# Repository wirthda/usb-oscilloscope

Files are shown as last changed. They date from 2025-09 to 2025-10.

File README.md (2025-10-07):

# Introduction
This repository serves as documentation and overview of the project **USB-oscilloscope**,
which was carried out in the summer semester 2025 at the efi faculty of the University of Applied Sciences Nuremberg (Georg-Simon-Ohm).
# Overview
### Project structure:
Project structure separated into areas of responsibility.
<ins>legend:</ins>\
HW - hardware\
FW - firmware\
SW - software

### USB oscilloscope prototype:
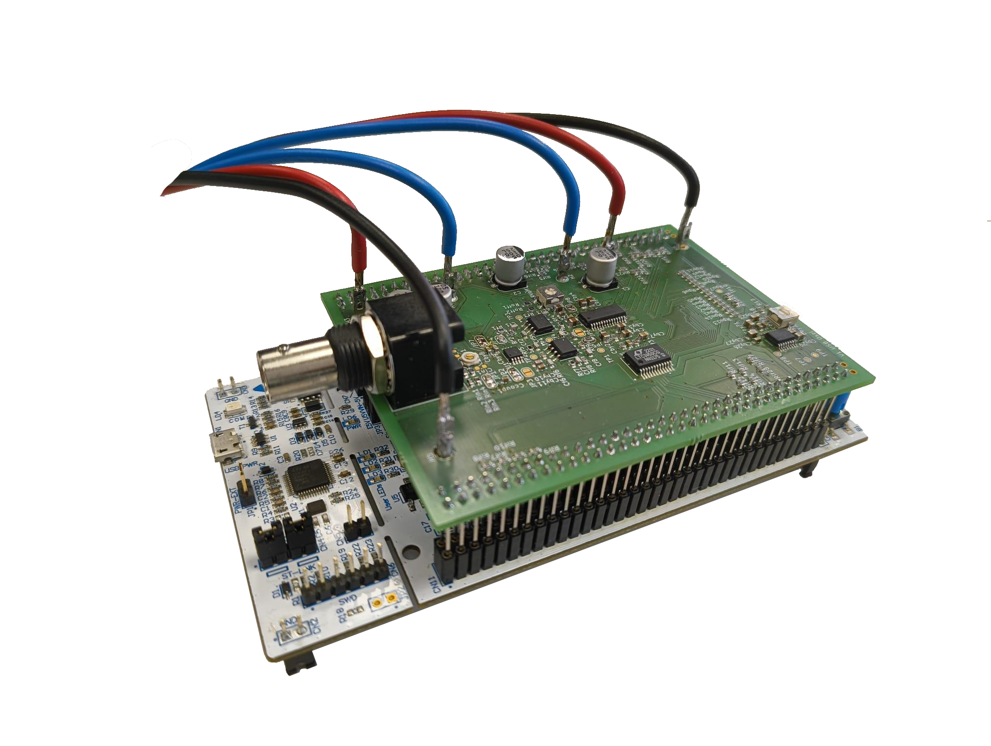
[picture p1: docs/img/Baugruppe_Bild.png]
Picture of the USB oscilloscope prototype.


### Documentation:
PDF [GER]: [Dokumentation_Projekt_USB_Oszi.pdf](docs/documentation/LATEX_german/Dokumentation_Projekt_USB_Oszi.pdf)

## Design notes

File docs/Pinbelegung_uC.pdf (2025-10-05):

## Projekt USB Oszilloskop

Pinbelegungen Microcontroller-Entwicklungsboard NUCLEO-F767ZI

CN11 und CN12 sind sowohl auf dem NUCLEO-Board, als auch auf der Baugruppe vorhanden.
Die Verbindung erfolgt 1:1.
ADC | | | | Trigger | | | | DAC
Pin | Funktion | Stecker | Steckerpin | Pin | Funktion | Stecker | Steckerpin | Pin | Funktion | Stecker | Steckerpin
PF3 3V3_ADC1_D0 | CN12 | 58 | PF2 | 3V3_TRIGGERED_SIG_OUT CN11 | 52 | PE0 | 3V3_DAC1_CLEAR_LOW_ACTIVE CN12 | 64
PF4 3V3_ADC1_D1 | CN12 | 38 | PE1 | 3V3_DAC1_LOAD_LOW_ACTIVE | CN11 | 61
PF5 3V3_ADC1_D2 | CN12 | 36
PF6 3V3_ADC1_D3 | CN11 | 9 | PE2 | 3V3_DAC1_D0 | CN11 | 46
PF7 3V3_ADC1_D4 | CN11 | 11 | PE3 | 3V3_DAC1_D1 | CN11 | 47
PF8 3V3_ADC1_D5 | CN11 | 54 | PE4 | 3V3_DAC1_D2 | CN11 | 48
PF9 3V3_ADC1_D6 | CN11 | 56 | PE5 | 3V3_DAC1_D3 | CN11 | 50
PF10 3V3_ADC1_D7 | CN12 | 42 | PE6 | 3V3_DAC1_D4 | CN11 | 62
PF11 3V3_ADC1_D8 | CN12 | 62 | PE7 | 3V3_DAC1_D5 | CN12 | 44
PF12 3V3_ADC1_D9 | CN12 | 59 | PE8 | 3V3_DAC1_D6 | CN12 | 40
PF13 3V3_ADC1_D10 | CN12 | 57 | PE10 3V3_DAC1_D7 | CN12 | 52
PF14 3V3_ADC1_D11 | CN12 | 50 | PE11 3V3_DAC1_D8 | CN12 | 56
PF15 3V3_ADC1_OF_BIT (Overflow Flag) | CN12 | 60 | PE12 3V3_DAC1_D9 | CN12 | 49
PE13 3V3_DAC1_D10 | CN12 | 55
PE9 3V3_ADC_CLK_IN | CN12 | 52 | PE14 3V3_DAC1_D11 | CN12 | 51

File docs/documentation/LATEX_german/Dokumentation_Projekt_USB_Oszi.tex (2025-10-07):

% Ersteller: 	Daniel Wirth
% Software:	TeX-Distribution --> MiKTeX (https://miktex.org/); Editor --> Texmaker (https://www.xm1math.net/texmaker/)
% Literatur:	.bib erstellt mit JabRef (https://www.jabref.org/); %Achtung: bilatex-mode verwenden (preferences) und dann .bib-file erstellen; Engine --> biber
%

\documentclass[a4paper, portrait, 12pt]{scrartcl} % Vorgabe TH Nbg
%%%%%%%%%%% Präambel %%%%%%%%%%%

% Standardpakete
%\usepackage[latin1]{inputenc}
\usepackage[T1]{fontenc}
\usepackage[ngerman]{babel}
\usepackage[left=3cm, right=2cm]{geometry} % Vorgabe TH Nbg
\usepackage{graphicx}
\graphicspath{ {../../img/} }
\usepackage{amsmath,amsfonts}
\usepackage{siunitx}
\usepackage{textcomp} % €
\usepackage[dvipsnames]{xcolor}
\usepackage{xspace} % Sorgt dafür, dass Leerzeichen hinter parameterlosen Makros nicht als Makroendezeichen interpretiert werden

% Formatierung etc.: Allgemein
\usepackage{setspace}
\onehalfspacing % Vorgabe TH Nbg
%\spacing{1.X}
\setlength{\parindent}{0pt} % Kein Einzug
\usepackage{afterpage}
\usepackage{lastpage}
\usepackage{fancyhdr} % Für beliebige Kopf- und Fußzeilen
\pagestyle{fancy}
\fancyhf{} % Löscht vorherige Einstellungen - Gesamt
%\fancyhead{} % Löscht voherige Einstellungen
%\fancyfoot{} % Dito
\renewcommand{\headrulewidth}{0 pt} % Keine obere Trennlinie
%\(this)pagestyle{empty} % Keine Seitenzahlen
%\setcounter{page}{n} % Bestimme Seite mit n bezeichnen, nachfolgende ist dann n+1
\rfoot{\thepage\ von \pageref{LastPage}} % Seite x von y; Vorgabe TH Nbg
\usepackage{enumitem}

% Formatierung etc.: Schrift
\usepackage{lmodern} % bessere Fonts
%\usepackage{ulem} % Unterstreichen
\usepackage{relsize} % Schriftgröße relativ festlegen

% Formatierung etc.: Tabellen/Arrays
%\usepackage{tabularx} % "Einfacher Tabllen gestalten"
%\usepackage{adjustbox}
\usepackage{caption} % Beschriftung von Bildern/Tabellen
\usepackage{subcaption} % Analog zu oben
%\setlength{\topsep}{0pt} % Kein xtra Abstand über Tabulator	
%\setlength{\partopsep}{0pt} % Kein xtra Abstand unter Tabulator	

% Code-Snippets
\usepackage{listings}

% Hyperlinks und URLs etc.
\usepackage[ 
       colorlinks=true,		%% wenn keine Farbigen Links: = false
    ]{hyperref}
\hypersetup{colorlinks=true, linkcolor=black, urlcolor=MidnightBlue, citecolor=black}
\urlstyle{same}

% Graphiken, Plots, PDFs etc.
%!TEX root = name.tex % Andere .tex-Datei einbinden
\usepackage{pdfpages}
\usepackage{float}
\usepackage{wrapfig}
%\usepackage{pgfplots}
%\pgfplotsset{width=10cm,compat=1.9} % Zweiten Parameter nicht verändern!

% Rechtschreibung bzw. Trennung
%\hyphenchar\font=\string"7F % Nötig für korrekte Silbentrennung!
%\hyphenation{Kom-pli-ziert-es-Wort}
%\hyphenpenalty = XXX
%\tolerance = XXX

% Mathe
%\usepackage{aligned-overset}
%\usepackage{mathabx} %\widehat{•} & \widecheck{}

% "Speziellere" Befehle
%\newcommand{\forceindent}{\leavevmode{\parindent=1.5em\indent}}

% Bibliographie
\usepackage[style=alphabetic, backend=biber]{biblatex}  
\usepackage{csquotes} % Für Anführungszeichen bei Zitaten
\addbibresource{Bibliographie_Projekt_USB_Oszi.bib}
%\usepackage[nohyperlinks, printonlyused]{acronym} % Abkürzungsverzeichnis

% define style for code snippets
\definecolor{codegreen}{rgb}{0,0.6,0}
\definecolor{codegray}{rgb}{0.5,0.5,0.5}
\definecolor{codepurple}{rgb}{0.58,0,0.82}
\definecolor{codefunc}{rgb}{0,0.3,0.7}
\definecolor{backcolour}{rgb}{0.95,0.95,0.92}

\lstdefinestyle{pythonstyle}{
    backgroundcolor=\color{backcolour},   
    commentstyle=\color{codegreen},
    keywordstyle=\color{magenta},
    identifierstyle=\color{codefunc},
    numberstyle=\tiny\color{codegray},
    stringstyle=\color{codepurple},
    basicstyle=\ttfamily\footnotesize,
    breakatwhitespace=false,         
    breaklines=true,                 
    captionpos=b,                    
    keepspaces=true,                 
    numbers=left,                    
    numbersep=5pt,                  
    showspaces=false,                
    showstringspaces=false,
    showtabs=false,                  
    tabsize=2
}

\lstdefinestyle{plaintextstyle}{
    language={},                     % Keine Sprache -> keine Keywords
    basicstyle=\ttfamily\scriptsize, % Nur kleine Monospace-Schrift
    keywordstyle=,                    % Keywords deaktivieren
    commentstyle=,                    % Kommentare deaktivieren
    stringstyle=,                     % Strings deaktivieren
    identifierstyle=,                 % Variablen/Bezeichner deaktivieren
    numbers=none,                     % Keine Zeilennummern
    showspaces=false,                 
    showstringspaces=false,           
    showtabs=false,                   
    breaklines=true,                  
    breakatwhitespace=false,
    backgroundcolor=                  % Kein Hintergrund
}

\lstset{style=pythonstyle}

\title{Projektarbeit ``USB-Oszilloskop``}
\author{Samuel Oeser, Nicole Sturm, Daniel Wirth}
\date{\today}

%%%%%%%%%%% Main %%%%%%%%%%%
\begin{document}

\setlist{noitemsep}	% no item separation in lists

%%%%%%%%%%% Deckblatt %%%%%%%%%%%
\maketitle
\begin{figure}[H]
	\centering
     
	\label{fig:Baugruppe_Bild}
\end{figure}

\begin{center}
	Bachelorstudiengang Elektro- und Informationstechnik (BEI)\\
	Technische Hochschule Nürnberg\\
	Fakultät efi\\
	SoSe2025
\end{center}

\thispagestyle{empty}

\pagebreak

%%%%%%%%%%% TOC %%%%%%%%%%%
%\thispagestyle{empty}
\tableofcontents
\pagebreak

%%%%%%%%%%% Abstract / Zusammenfassung %%%%%%%%%%%
\section{Abstract / Zusammenfassung}

Im Rahmen eines praxisnahen Projektes wurde erfolgreich ein USB-Oszilloskop als digitaler Speicheroszilloskop-Prototyp entwickelt. Zielsetzung war die eigenständige Realisierung aller wesentlichen Entwicklungsphasen, von der Konzeption bis zur Inbetriebnahme, unter Zusammenführung von Hardware, Firmware und PC-Software. Die Hardware besteht aus einem analogen Frontend zur Signalaufbereitung, einem 12-Bit-Analog-Digital-Wandler und einem Mikrocontroller, der die Schnittstelle zum PC bereitstellt.\\ 
Das Projektteam folgte einem strukturierten Vorgehensmodell und definierte die Systemanforderungen in enger Abstimmung mit der Projektbetreuung. Dazu gehörten eine Bandbreite von 1~MHz, eine Abtastrate von 10~MS/s und ein flexibler Eingangsspannungsbereich von $\pm5$~V, der mit üblichen Tastköpfen erweitert werden kann. Die Firmware steuert die Datenerfassung und Vorverarbeitung effizient mittels Zustandsautomat und DMA, die Datenübertragung zum PC erfolgt stabil über USB. Die eigens programmierte Benutzeroberfläche ermöglicht eine intuitive Steuerung sowie Echtzeit-Visualisierung und Analyse der Messdaten.\\ 
Im Rahmen umfangreicher Tests wurde bestätigt, dass das System die Kernanforderungen in vollem Umfang erfüllt. Die Signalaufzeichnung ist bis 500~kHz besonders präzise, für höhere Frequenzen wurden Verbesserungsmöglichkeiten herausgearbeitet. Die modulare Systemarchitektur gewährleistet eine zuverlässige Zusammenarbeit aller Komponenten; die Bedienung erwies sich als benutzerfreundlich und fehlerfrei.\\ 
Das Projekt bot nicht nur Gelegenheit, technische Kompetenzen in den Bereichen Schaltungsentwicklung, Embedded Software und GUI-Design zu vertiefen, sondern auch Teamarbeit, Organisation und systematisches Vorgehen praxisnah umzusetzen. Der Prototyp liefert somit eine fundierte Grundlage für weitere Optimierungen sowie die Entwicklung zusätzlicher Messfunktionen.
\pagebreak

%%%%%%%%%%% Einleitung %%%%%%%%%%%
\section{Einleitung}
Die vorliegende Projektarbeit wurde im Rahmen des Bachelorstudiengangs Elektrotechnik und Informationstechnik an der Fakultät für Elektrotechnik, Feinwerktechnik und Informationstechnik (EFI) der Technischen Hochschule Nürnberg Georg Simon Ohm durchgeführt. Ziel des Projekt-Moduls ist es, den Studierenden die Möglichkeit zu geben, ihr theoretisch erworbenes Wissen in einem praxisnahen, ingenieurwissenschaftlich strukturierten Entwicklungsprojekt anzuwenden. Die Motivation für die Auswahl des Projektthemas lag in der Abbildung des vollständigen Entwicklungsprozesses eines aus Hardware, Firmware und Software bestehenden Gesamtsystems. Auf diese Weise konnten praxisnahe Erfahrungen in allen wesentlichen Entwicklungsdisziplinen gesammelt werden. Darüber hinaus bot das Projekt die Gelegenheit, die grundlegenden Funktionen eines Oszilloskops zu verstehen und im Rahmen eines Prototyps zu realisieren. Ein weiteres wesentliches Auswahlkriterium für das Thema war die klare Unterteilung in abgegrenzte Aufgabenbereiche, sodass die Teammitglieder ihre Aufgaben eigenständig bearbeiten konnten, während gleichzeitig eine Zusammenarbeit im übergeordneten Kontext möglich war.\\

Das zu Beginn definierte Ziel des Projekts war die Entwicklung eines USB-Oszilloskops. Das Gesamtsystem, bestehend aus selbstentwickelter Hardware und einem über Universal Serial Bus (USB) angeschlossenen Computer, soll die Grundfunktionen eines digitalen Speicheroszilloskops (DSO) abbilden. Die Realisierung sollte durch den Einsatz eines Analog-Digital-Umsetzers (ADC) zur Messwerterfassung sowie eines Mikrocontrollers ($\mu$C) als Schnittstelle zwischen der Hardware (ADC-Schaltung) und der Software (Computer) erfolgen.\\

Das Projektteam setzte sich aus drei Studierenden zusammen: Samuel Oeser war verantwortlich für die Entwicklung der Hardware (HW), Daniel Wirth übernahm die Firmware (FW), während Nicole Sturm die Software (SW) einschließlich der grafischen Benutzeroberfläche (GUI) entwickelte. Die Betreuung des Projekts erfolgte durch Prof. Dr. Sven Loquai, der die Studierenden während des gesamten Entwicklungsprozesses begleitete.
\pagebreak

%%%%%%%%%%% Fachliche Grundlagen %%%%%%%%%%%
\section{Fachliche Grundlagen}

\subsection{Allgemeiner Aufbau eines DSOs}
\label{subsec:oscilloscope_func}
Das DSO erfasst Eingangssignale, digitalisiert sie und stellt die Messdaten nach Speicherung und Verarbeitung dar. Der grundlegende Aufbau umfasst die Eingangsumschaltung (DC AC GND) mit Vertikalverstärkung/abschwächung, den ADU mit Signalvorverarbeitung, den Datenspeicher, Takt und Steuerung, die Triggereinrichtung sowie die Anzeige. Die digitalisierten Daten werden im Speicher abgelegt und für Darstellung und Auswertung ausgelesen (vgl. \cite[S. 216]{Muehl2020}).

\begin{figure}[H]
	\centering
     
	\caption{Blockschaltbild eines Digitaloszilloskops (Abb. 14.1 aus \cite[S. 216]{Muehl2020})}
	\label{fig:blockdiagram_oscilloscope}
\end{figure}

Für die Abtastung sind zwei Betriebsarten relevant. Die Echtzeitabtastung erfasst den kompletten Verlauf in einem Durchlauf und die zeitliche Auflösung wird durch die Rate des AD-Umsetzers (ADU) begrenzt. Die Äquivalenzzeitabtastung rekonstruiert sehr schnelle periodische Verläufe aus mehreren Durchläufen (vgl. \cite[S. 216]{Muehl2020}).

\begin{figure}[H]
	\centering
     
	\caption{Gegenüberstellung Echtzeitabtastung (a) und Äquivalenzzeitabtastung (b) (Abb. 14.2 aus \cite[S. 216]{Muehl2020})}
	\label{fig:real_equivalent_sampling}
\end{figure}

Für eine gut auswertbare Darstellung sind etwa zehn Stützstellen je Periode zweckmäßig und die si-Interpolation (auch sinc-Interpolation genannt) ermöglicht bei erfüllter Nyquist Bedingung eine nahezu verzerrungsfreie Rekonstruktion. In der Praxis sollte die maximale Signalfrequenz mindestens um den Faktor 2,5 unter der Abtastrate liegen (vgl. \cite[S. 218f]{Muehl2020}).

\begin{figure}[H]
	\centering
		 
		\caption{\centering Punktedarstellung (a) und lineare Interpolation (b)\\(Abb. 14.4 aus \cite[S. 218]{Muehl2020})}
	\label{fig:point_linear_display}
\end{figure}

\begin{figure}[H]
	\centering
		 
		\caption{\centering Lineare Interpolation (a) und si-Interpolation (b)\\(Abb. 14.5 aus \cite[S. 219]{Muehl2020})}
	\label{fig:linear_si_display}
\end{figure}

In der Praxis werden für die Digitalisierung schnelle Flash-ADUs sowie mehrstufige Sub-ranging- / Pipeline‑Varianten eingesetzt. Diese ermöglichen hohe Raten bei moderater vertikaler Auflösung. Übliche Geräte arbeiten mit acht Bit vertikaler Auflösung. Je nach Architektur sind höhere Auflösungen möglich (vgl. \cite[S. 114-119]{Bernstein2023}). Für die Datenaufnahme stehen verschiedene Acquisition-Modi zur Verfügung. Der direkte Modus liefert äquidistante Samples. Min-Max oder Peak-Detect erfasst Extremwerte innerhalb eines Abtastintervalls und macht kurze Spikes sichtbar. Average reduziert Rauschen durch wiederholtes Mitteln. Single Shot zeichnet einmalige Ereignisse auf und der Roll-Modus zeigt sehr langsame Verläufe kontinuierlich an (vgl. \cite[S. 220f]{Muehl2020}). Die Genauigkeit wird wesentlich durch die Abtastrate und Abtaststrategie, Interpolation und Quantisierung sowie durch die Eingangsbeschaltung bestimmt. Bei Unterabtastung droht Aliasing und die Rekonstruktion wird unzuverlässig (vgl. \cite{Muehl2020}, Grundlagen zur Abtastung und Quantisierung). Wichtige Kenngrößen von DSOs sind analoge Bandbreite, Abtastrate, vertikale Auflösung, Speichertiefe, Triggerfunktionen, Eingangsimpedanz, analoge Eingangsspannung sowie Anzeige und Darstellungsoptionen. Über die Kurvendarstellung hinaus gehören auch automatische Messfunktionen zum Grundumfang.

\subsubsection{Trigger}

Die Triggerung steuert die Signalspeicherung. Fortlaufend erfasste Abtastwerte laufen in einen Ringspeicher und beim Triggerereignis wird das Überschreiben gestoppt, sodass Pre Trigger und Post Trigger gezielt darstellbar sind (vgl. \cite[S. 216f]{Muehl2020}).

\begin{figure}[H]
	\centering
		 
		\caption{\centering Messsignal $s(t)$ mit eingestellter Triggerschwelle und Triggerzeitpunkt\\(Teilabbildung der Abb. 14.3 aus \cite[S. 217]{Muehl2020})}
	\label{fig:trigger_oscilloscope}
\end{figure}

Die analoge Triggerkette umfasst Quelle, Kopplung DC oder AC, einstellbare Triggerschwelle, Flankenrichtung, Hysterese und Auto Trigger. Sie erzeugt ein robustes Triggersignal für die Speichersteuerung (vgl. \cite[S. 210-212]{Muehl2020}).

\begin{figure}[H]
	\centering
		 
		\caption{\centering Funktionsblöcke einer Triggereinrichtung (Abb. 13.8 aus \cite[S. 212]{Muehl2020})}
	\label{fig:trigger_circuit_oscilloscope}
\end{figure}

\subsubsection{Frequenzkompensierter Tastkopf / Spannungsteiler}
\label{subsubsec:freq_comp_vdiv}

In der Praxis existieren verschiedene Arten von Tastköpfen wie passive, aktive und differenzielle Tastköpfe. Im Folgenden wird ausschließlich der frequenzkompensierte passive Tastkopf betrachtet, da er für das Projekt relevant ist (vgl. \cite[Kap. 15]{Muehl2020}). Dieser Tastkopf basiert auf einem frequenzkompensierten Spannungsteiler (seihe \autoref{fig:freq_compensated_vdiv}), realisiert als RC Teiler mit zu den Widerständen parallel geschalteten Kapazitäten und mit einer Anpassung an die Summe aus Bauteil- und Leitungskapazitäten. Die Kompensation mit Trimmkondensator (in \autoref{fig:freq_compensated_vdiv}: $C_T$) wird so abgeglichen, dass das Teilungsverhältnis im Nutz-Frequenzband annähernd konstant bleibt. Der Abgleich erfolgt mit einem Rechtecksignal. Unterkompensation zeigt sich durch eine nach unten geneigte Oberkante (\autoref{fig:freq_compensated_time}a), Überkompensation durch eine nach oben geneigte Oberkante (\autoref{fig:freq_compensated_time}c) und bei korrekter Kompensation bleibt die Oberkante über die Pulsbreite hinweg horizontal (\autoref{fig:freq_compensated_time}b) (vgl. \cite[S. 104-106]{Schruefer2022}).

\begin{figure}[H]
	\centering
		 
		\caption{\centering Tastteiler am Eingang eines Oszilloskops (Bild 2.42 aus \cite[S. 105]{Schruefer2022})}
	\label{fig:freq_compensated_vdiv}
\end{figure}

\begin{figure}[H]
	\centering
		 
		\caption{\centering Rechteckimpulse an RC-Spannungsteiler (Bild 2.43 aus \cite[S. 106]{Schruefer2022})\\ \footnotesize (a) unterkompensiert, (b) richtig kompensiert, (c) überkompensiert}
	\label{fig:freq_compensated_time}
\end{figure}

Mit $R_1=R_T$ und $C_1=C_T$ gilt für die obere Teilimpedanz ($\underline{Z_1}$):
\begin{equation}
	\underline{Z_1}=R_1||\frac{1}{j\omega C_1}=\frac{R_1}{1+j\omega R_1 C_1}
	\label{eq:z1}
\end{equation}
und mit $R_2=R_E$ und $C_2=C_K+C_E$ gilt für die untere Teilimpedanz ($\underline{Z_2}$):
\begin{equation}
	\underline{Z_2}=R_2||\frac{1}{j\omega C_2}=\frac{R_2}{1+j\omega R_2 C_2}
	\label{eq:z2}
\end{equation}
Über den Spannungsteiler ergibt sich aus (\ref{eq:z1}) und (\ref{eq:z2}) das Verhältnis:
\begin{equation}
	\frac{\underline{U_1}}{\underline{U_2}}=\frac{\underline{Z_1}+\underline{Z_2}}{\underline{Z_2}}=1+\frac{\underline{Z_1}}{\underline{Z_2}}=1+\frac{R_1}{R_2}\frac{1+j\omega R_2 C_2}{1+j\omega R_1 C_1}
	\label{eq:comp_vdiv}
\end{equation}
Dieses Verhältnis nimmt den frequenzunabhängigen Wert $\frac{\underline{U_1}}{\underline{U_2}}=1+\frac{R_1}{R_2}$ an, wenn gilt:
\begin{equation}
	R_1\cdot C_1=R_2\cdot C_2
\end{equation}
Durch Einsetzen der Einzelbauelemente für $R_1$, $R_2$, $C_1$ und $C_2$ und Auflösen nach $C_T$ ergibt sich für den Trimmkondensator ein Wert nach \autoref{eq:ct_compensated_vdiv}, damit der Spannungsteiler frequenzunabhängig wird (vgl. \cite[S. 104-106]{Schruefer2022}).

\begin{equation}
	C_T=\frac{R_E\cdot (C_K+C_E)}{R_T}
	\label{eq:ct_compensated_vdiv}
\end{equation}

\subsection{AAF-Entwurf (Nyquisttheorem)}
\label{subsec:aaf_nyquist}

Ein Digitaloszilloskop erfasst das analoge Eingangssignal durch Abtastung mit einer bestimmten Frequenz. Diese Abtastung entspricht der Multiplikation des Signals mit einer Reihe von Impulsen, was im Frequenzbereich einer Faltung entspricht. Eine eindeutige Rekonstruktion aus den Abtastwerten setzt ein bandbegrenztes Eingangssignal mit höchster relevanter Frequenz und eine Abtastrate oberhalb des Doppelten dieser Frequenz voraus. Bei Unterschreitung falten sich Spektralkopien in das Basisband zurück und erzeugen Aliasse. Dies wird im Frequenzbild durch die Überlappung periodischer Spektren sichtbar in \autoref{fig:aaf_freq_domain} sowie im Zeitbereich durch scheinbar niedrigere Schwingungen in \autoref{fig:aliasing_time_domain}. Aus dieser Grundlage folgt die Notwendigkeit eines vorgeschalteten Anti-Aliasing-Tiefpasses, der außerbandige Anteile vor der Wandlung ausreichend dämpft (vgl. \cite[S. 314-316]{Bernstein2023} und \cite[S. 151-156]{Bernstein2024}).

\begin{figure}[H]
	\centering
		 
		\caption{\centering Aliasing: Erzeugung einer Scheinfrequenz durch unpassende Abtastrate\\ (Bild 2.71 aus \cite[S. 154]{Bernstein2024})
		}
	\label{fig:aliasing_time_domain}
\end{figure}

\begin{figure}[H]
	\centering
		 
		\caption{\centering Abtasttheorem (Bild 4.30 aus \cite[S. 314]{Bernstein2023})\\
			\footnotesize(a) Betragsspektrum des bandbegrenzten Signals\\
			(b) Vervielfachung des Basisspektrums durch Abtastung mit $f_S > 2\cdot f_g$\\
			(c) Aliasing infolge zu niedriger Abtastrate ($f_S < 2\cdot f_g$)
		}
	\label{fig:aaf_freq_domain}
\end{figure}

Da der Entwurf des Anti-Aliasing-Filters maßgeblich durch den ausgewählten AD-Umsetzer bestimmt wird, sollte dieser zuerst festgelegt werden. Für aktive RC-Filter bewährt sich wegen Bauteiltoleranzen und des nicht idealen Übergangs vom Durchlass- in den Sperrbereich eine Abtastrate oberhalb der Mindestbedingung, typischerweise etwa 2.5 bis 4 mal $f_{max}$ und bei strengen Dämpfungszielen, z.B. wegen höheren Auflösungen, auch 5 bis 10 mal $f_{max}$. Eine höhere Abtastrate erweitert zudem die Übergangsbreite und senkt damit die notwendige Filterordnung, erleichtert die direkte Darstellung des abgetasteten Signals ohne Rekonstruktionsalgorithmen und erlaubt eine Filterfamilie mit geringerer Gruppenlaufzeitvariation und damit besserem Zeitverhalten. Aus der gewählten Abtastrate folgt dann die Nyquist-Frequenz $f_N = \frac{f_S}{2}$ und die Übergangsbreite $\Delta f = f_N - f_{max}$ \cite{Pini2020}.\\

Der theoretische, aus der Auflösung abgeleitete Dynamikbereich setzt eine Obergrenze für die sinnvoll anzustrebende Sperrbanddämpfung. Für einen \emph{N}-Bit-Umsetzer mit Full-Scale-Range \emph{FSR} gilt die Codebreite $Q = \frac{FSR}{2^N}$. Ein voll ausgesteuertes Störsignal soll auf einen Pegel unterhalb der Codebreite gedämpft werden, damit keine signifikanten Quantisierungsartefakte entstehen. Die Sperrbanddämpfung, beginnend an der Nyquist-Frequenz, wird daher so festgelegt, dass aliasingverursachende Anteile unterhalb der Codebreite bleiben:

\begin{equation}
	A(f_N)_{max}=20\cdot log_{10}\left( \frac{FSR}{Q}\right) =20\cdot log_{10}(2^N)=6.02\cdot N\hspace{0.1cm}dB
\end{equation}

In der Praxis begrenzt das $SINAD$ häufig den nutzbaren Dynamikbereich des gewählten AD-Umsetzers. Gilt $|SINAD|<|A_{max}|$ oder liegt die daraus ermittelte $ENOB$ (siehe \autoref{subsubsec:adc_characteristics} ``\nameref{subsubsec:adc_characteristics}``) unter der Auflösung des ADCs, dominieren Rauschen- und Verzerrungen. Bei Einsatz einer Mittelwertbildung kann es dennoch zweckmäßig sein, die Obergrenze $A_{max}$ anzusetzen. Im Regelfall wird die Sperrbanddämpfung an der Nyquistfrequenz so gewählt, dass gilt (vgl. \cite{Pini2020}):

\begin{equation}
	A(f_N)\approx min(|A_{max}|, |SINAD_{ADC}|)
\end{equation}

Der Entwurf der Filter und die exakte Anpassung an die eigenen Forderungen erfolgt heutzutage in erster Linie mit Filter Tools, wie z.B. dem Analog Filter Wizard. Die Bewertung des entworfenen Filters erfolgt in dem Tool oder der Simulation u. A. über die Diagramme von Amplitudengang, Phasen- und Gruppenlaufzeit sowie Sprung- und Impulsantwort. Der Frequenzgang belegt Passband-Flachheit, Übergangsbreite und die Dämpfung an $f_N$. Phase und Gruppenlaufzeit zeigen, ob das Filter im Nutzband annähernd eine konstante Verzögerung liefert und damit Impulse und Flanken formtreu bleiben. Die Sprungantwort offenbart Überschwinger und Einschwingzeit. Eine Toleranzanalyse der zu erwartenden Widerstands- und Kapazitätsstreuungen zeigt, ob die Reserven ausreichend dimensioniert wurden (vgl. \cite{Pini2020} und \cite{Padmanabhuni2017}).

\subsection{Analog-to-Digital-Converter (ADC)}
\label{subsec:adc}

Ein Digitaloszilloskop benötigt einen AD-Umsetzer als zentrales Hardwareelement, da erst die Wandlung des analogen Eingangssignals in digitale Messwerte die weitere Speicherung, Verarbeitung und Anzeige ermöglicht. Für die Auswahl steht die Topologie am Anfang, weil sie Abtastrate, erreichbare Auflösung, Latenz, Leistungsaufnahme und den Implementierungsaufwand bestimmt.\\

Für ein USB-Oszilloskop bieten sich Flash- und Pipeline-Topologien an, da beide hohe Abtastraten für breitbandige Zeitbereichsmessungen bereitstellen. Andere Varianten wie SAR oder Delta-Sigma werden in den Quellen überwiegend mittleren Geschwindigkeiten oder schmalbandigen Präzisionsaufgaben zugeordnet und sind somit für ein USB-Oszilloskop irrelevant (vgl. \cite{MPS} und \cite{AnalogDevices2001a}).\\

\subsubsection{Flash-ADC}
\autoref{fig:2bit_flash_adc} zeigt das Prinzip eines Flash-AD-Umsetzers mit zwei Bit. Eine Widerstandsleiter erzeugt abgestufte Referenzen und eine Komparatorbank vergleicht das Eingangssignal mit diesen Schwellen. Das resultierende Muster wird durch eine Logikschaltung in einen Binärcode überführt. Flash-ADCs erreichen, durch diesen simplen Aufbau, die höchste Geschwindigkeit. Da die Zahl der Komparatoren jedoch $2^N-1$ beträgt, steigen bei hohen Auflösungen Komplexität, Fläche, Leistungsaufnahme sowie insbesondere die Herstellungskosten annähernd exponentiell an (vgl. \cite{MPS} und \cite{AnalogDevices2001b}).

\begin{figure}[H]
	\centering
		 
		\caption{\centering  Flash-Umsetzer mit 2 Bit, einschl. Kodeumsetzer\\
		\footnotesize Ersteller: Saure, Quelle: \href{https://de.wikipedia.org/wiki/Datei:DMT_ADU-2-Bit-Flash.svg}{[Link]} (Lizenz: \href{https://creativecommons.org/licenses/by-sa/3.0/}{CC BY-SA 3.0})
		}
	\label{fig:2bit_flash_adc}
\end{figure}

\subsubsection{Pipeline-ADC}
Eine Alternative zur geringeren Skalierbarkeit des Flash-ADCs ist der Pipeline-ADC, der auch im Projekt zur Anwendung kommt. Er baut funktional auf dem Flash-Prinzip auf, indem mehrere niedrigauflösende Flash-ADCs in Stufen hintereinandergeschaltet werden. Am Eingang tastet eine Sample-and-Hold-Stufe das Signal ab. Jede Stufe wandelt in wenige Bits, rekonstruiert den quantisierten Anteil über einen DAC, bildet den Restfehler im Subtrahierer und verstärkt diesen für die nächste Stufe. Durch Überlappbits und digitale Fehlerkorrektur können die Genauigkeitsanforderungen an die einzelnen Stufen reduziert werden und die Durchsatzraten erhöht. Durch diesen Aufbau steigt der Aufwand mit zunehmender Auslösung nur linear an. Bauartbedingt entsteht allerdings eine definierte Zykluslatenz, die in ganzen oder halben Taktzyklen angegeben wird. Diese Latenz ist der entscheidende Nachteil eines Pipeline ADCs (vgl. \cite{MPS} und \cite{AnalogDevices2001c}).

\begin{figure}[H]
	\centering
		 
		\caption{\centering 12-bit pipelined ADC\\ \footnotesize Ersteller: MPS, Quelle: \href{https://www.monolithicpower.com/en/learning/mpscholar/analog-to-digital-converters/detailed-analysis-of-adc-architectures/pipeline-adcs}{[Link]} (Ch. 2, Fig. 4)
		}
	\label{fig:pipelined_adc}
\end{figure}
\pagebreak

\subsubsection{Wichtige Kenngrößen von AD-Umsetzern}
\label{subsubsec:adc_characteristics}

Die Kenngrößen und deren Definition können dem IEEE Standard 1241-2023 \emph{``Terminology and Test Methods for Analog-to-Digital Converters``} (\cite[S. 22ff]{IEEE2023}) entnommen werden.\\

\textbf{Auflösung und Eingangsbereich}\\
Die Auflösung eines \emph{N}-Bit-AD-Umsetzers umfasst $2^N$ binäre Codes. Der differentielle Eingangspannungssbereich wird als Full-Scale Range (\emph{FSR}) bezeichnet und in Volt angegeben. Das LSB entspricht $\frac{FSR}{2^N}$.\\

\textbf{Maximale Sampling-Rate}\\
Die Abtastrate ist der Kehrwert der Abtastperiode (Abstand zwischen Abtastwerten). Sie bestimmt die zeitliche Auflösung und ist insbesondere in Bezug auf das Niyqusttheorem relevant.\\

\textbf{Leistungsaufnahme}\\
Die Leistungsaufnahme ist in erster Linie für die Auslegung der Versorgungsspannung und der zugehörigen Leitungen relevant.\\

\textbf{Verstärkungsfehler}\\
Der Verstärkungsfehler beschreibt die Abweichung der Kennliniensteigung von der idealen Steigung nach Offsetkorrektur und wird in $LSB$ oder in Prozent der Full-Scale-Range angegeben.\\

\textbf{Offsetfehler}\\
Der Offsetfehler ist die vertikale Verschiebung der Kennlinie relativ zur Referenzgeraden und wird in $LSB$ oder in Prozent der Full-Scale-Range angegeben.\\

\textbf{Latenz}\\
Die Latenz wird als Pipeline-Delay in ganzen oder halben Taktzyklen angegeben oder alternativ als Zeitangabe und beschreibt den Abstand zwischen Abtastung und Verfügbarkeit des zugehörigen Digitalworts.\\

\textbf{Differentielle Nichtlinearität $DNL$}\\
Die DNL ist die Abweichung der tatsächlichen Codebreite $W[k]$ von der idealen Codebreite $Q$, normiert auf $Q$, und wird in $LSB$ angegeben. Die Codebreite entspricht dem Spannungsbereich, der dem Code zugeordnet ist. Formal gilt $DNL[k]=\frac{W[k]}{Q}-1$.\\
Die Angabe im Datenblatt entspricht $max\hspace{0.1cm}DNL[k]$.\\

\textbf{Integrale Nichtlinearität $INL$}\\
Abweichung des Übergangsspannungsniveaus von einem Code in den nächsten zu dem der idealisierten Geraden, nach Korrektur von Offset und Verstärkung.\\
Damit gilt $INL[k]=\sum_{n=0}^kDNL[n]$. Die Angabe im Datenblatt entspricht $max\hspace{0.1cm}INL[k]$.\\

\textbf{Rausch- und Verzerrungsmaße}\\
\textbf{$SNR$} gibt das Verhältnis von Nutzsignal- zu Rauschleistung an:
\begin{equation}
	SNR_{dB}=10\cdot \log_{10}\left( \frac{P_{Signal}}{P_{Rauschen}}\right)
\end{equation}

\textbf{$THD$} ist ein Maß für das Verhältnis von harmonischen Verzerrungen zur Grundschwingung:
\begin{equation}
	THD_{dB}=10\cdot \log_{10}\left( \frac{P_{Harmonische}}{P_{Signal}}\right)
\end{equation}

\textbf{$SINAD$} umfasst harmonische Verzerrungen und Rauschen:
\begin{equation}
	SINAD_{dB}=10\cdot \log_{10}\left( \frac{P_{Signal}}{P_{Rauschen}+P_{Harmonische}}\right)
\end{equation}

\textbf{$ENOB$} ist die effektive Bitzahl und wird aus SINAD abgeleitet:
\begin{equation}
	ENOB\approx \frac{SINAD[dB]-1.76}{6.02}
\end{equation}

\pagebreak

\subsection{Endliche Zustandsautomaten (Finite State-Machines - FSMs)}
\label{subsec:fsm}
Die Firmware und Software des Projekts sind als synchronisierte Zustandsautomaten implementiert, um einen deterministischen Ablauf der beiden Programme zu gewährleisten.
\subsubsection{Definition und formale Darstellung}
Ein endlicher Automat (EA - engl. Finite State Machine, FSM) ist ein abstraktes Rechenmodell zur Beschreibung von Systemen. Dieser befindet sich in mindestens einem Zustand von einer Zahl endlicher Zustände. Zustandsübergänge (sog. Transitionen) erfolgen durch Eingaben oder das Auftreten von Ereignissen (spezielle Form der Eingabe).\\

Zustände modellieren, was das System gerade tut bzw. in welchem internen ``Modus`` es sich befindet. Ereignisse sorgen für den Wechsel zwischen Zuständen. Übergänge definieren, wie das System im aktuellen Zustand auf ein Ereignis reagiert.

Ein FSM besteht nach \cite[S. 7ff]{Baesig2019} typischerweise aus:
\begin{itemize}
	\item einer Menge von Zuständen $S$,
	\item einem Anfangszustand $s_0$,
	\item einem Eingabe- oder Ereignisalphabet $E$ (Events),
	\item einem Ausgabealphabet $A$,
	\item einer Zustandsübergangsfunktion $\delta :S\times E\rightarrow S$,
	\item einer Ausgabefunktion $\lambda :S\times E\rightarrow A$,
	\item und einer endlichen (evtl. leeren) Menge der Endzustände $F$.
\end{itemize}

Je nach Modellierung kann das Ausgabealphabet und die Ausgabefunktion, sowie die Menge an Endzuständen entfallen.\\

Unterschieden werden folgende Arten von Endlichen Automaten:
\begin{itemize}
	\item \emph{Deterministische Endliche Automaten (DEA)}:\\
	Ein Automat wird als deterministisch bezeichnet, wenn für jede Kombination aus Eingabedaten und aktuellem Zustand eindeutig festgelegt ist, welcher Folgezustand erreicht wird. Das bedeutet, dass sich das \emph{System zu einem bestimmten Zeitpunkt stets in genau einem definierten Zustand} befindet.
	\item \emph{Nichtdeterministische Endliche Automaten (NEA)}:\\
	Bei einem NEA sind für einen bestimmten Zustand und eine Eingabe keine, genau ein oder mehrere mögliche Zustandsübergänge definiert.
\end{itemize}

DEAs sind einfacher als NEAs zu implementieren, wodurch diese in der Praxis häufiger zur Anwendung kommen (vgl. \cite[S. 14]{Baesig2019}). Im Projekt sind die FSMs als DEAs ausgeführt .\\

Eine weitere Aufgliederung von DEAs erfolgt nach der Abhängigkeit der Ausgabe, wenn diese vorhanden ist (vgl. \cite[S. 8f]{Baesig2019}).
\begin{itemize}
	\item Wenn die Ausgabe nur vom aktuellen Zustand abhängt, handelt es sich um einen \emph{Moore-Automaten}.
	\item Wenn die Ausgabe vom aktuellen Zustand \underline{und} der Eingabe abhängt, handelt es sich um einen \emph{Mealy-Automaten}.
\end{itemize}
Im Projekt kommen Moore-Automaten zur Anwendung.

\subsubsection{Modellierung und Darstellung}

Die Darstellung eines Zustandsautomaten erfolgt üblicherweise mit einem \emph{Zustandsdiagramm} (auch Zustandsübergangsdiagramm), einem gerichteten Graph\footnote{ ``Graphen sind ein [...] Konzept, um Objekte und die Beziehung zwischen diesen darzustellen.``\\Quelle: \href{https://www.tu-chemnitz.de/informatik/theoretische-informatik/TI-1/lecture-notes/06-00-graphs.html}{[Link]}}. Die Knoten stellen die Zustände der Menge $S$ dar und die gerichteten Kanten die Zustandsübergänge. Der Startzustand und die Endzustände werden gesondert gekennzeichnet. Eine übliche Darstellung für einen einfachen Moore-Automaten findet sich in \autoref{fig:statediagram_example}a (\emph{sn} sind die Zustände, \emph{xn} sind Eingaben oder Ereignisse und \emph{yn} sind Ausgaben; \emph{n = 1,2,...}) (vgl. \cite[S. 9]{Baesig2019}).\\

Die Darstellung des Zustandsdiagramms ist auch als Teil der \emph{Unified Modelling Language (UML)}\footnote{aktueller UML-Standard (V2.5.1): \href{https://www.omg.org/spec/UML/2.5.1/About-UML}{[Link]}} festgelegt, welche auch durch internationale Normung festgeschrieben ist. In der Praxis (vor allem beim händischen Entwurf von Zustandsdiagrammen) hat sich aber ein Mischform bewährt, welche auf einige Elemente der UML zurückgreift (siehe \autoref{fig:statediagram_example}b). Es lassen sich beispielsweise auch hierarchische Strukturen integrieren (verschachtelte Zustände).

\begin{figure}[H]
	\centering
     
	\caption{(a) Zustandsdiagramm (nach \cite{Baesig2019}); (b) UML-Zustandsdiagramm}
	\label{fig:statediagram_example}
\end{figure}
\subsubsection{Vorteile einer FSM bei der Programmierung}
\begin{itemize}
	\item \emph{Klarheit \& Übersichtlichkeit}\\
	Der Systemverlauf ist in wohldefinierte Zustände gegliedert. Der Code wird hierdurch verständlicher (kein ``Spaghetti-Code``).
	\item \emph{Deterministisches Verhalten}\\
	Durch die Definitionen, wie auf welches Ereignis reagiert wird, kann die Vorhersagbarkeit und Zuverlässigkeit gewährleistet werden. Außerdem lassen sich undefinierte Zustände durch die explizite Modellierung vermeiden.
	\item \emph{Modularisierung \& Wiederverwendbarkeit}\\
	Einzelne Zustände oder Teile der FSM lassen sich kapseln, segmentieren und wiederverwenden. Teilbereiche können eventuell separat getestet werden.
	\item \emph{Wartbarkeit \& Erweiterbarkeit}\\
	Das System lässt sich durch Hinzufügen neuer Zustände oder neuer Übergänge modular erweitern, ohne die vorhandene Logik stark zu verändern.
	\item \emph{Kommunikation und Dokumentation}\\
	Zustandsdiagramme können bei der Vermittlung von komplexem Programmverhalten gegenüber Nicht-Programmieren genutzt werden.
	\item \emph{Verbessertes Debugging}\\
	Da Zustandsübergänge zentralisiert sind, lassen sich Log-Messages und weitere Debugging-Mechanismen leichter verwenden.
\end{itemize}

\subsection{Direct Memory Access - DMA}
\label{subsec:dma}
\subsubsection{Allgemeines}
DMA bezeichnet den Vorgang, bei dem durch eine dedizierte Einheit ohne Beteiligung einer CPU Daten transferiert werden (also als Hintergrundprozess). Er kommt zum Einsatz, wenn große Datenmengen von der Peripherie oder einem Speicher zu einem anderen transferiert werden müssen. Ein Chip oder eine Teileinheit eines Mikrocontroller (µC), die solche Transfers durchführt, heißt \emph{Direct Memory Access Controller (DMAC)} (vgl. \cite[S. 125]{Urbanek2020}). Im Folgenden soll die Funktionsweise anhand der Realisierung in der im Projekt verwendeten STM32-Mikrocontrollerfamilie erläutert werden.

\subsubsection{DMA bei STM32-Mikrocontrollern}
Der DMA-Controller ist ein AHB-Modul (AHB - advanced high-performance bus; standardisiertes Bussystem von ARM) und kann wie auch die CPU des µCs als Master auf diesen Bus (genauer auf die Bus-Matrix) zugreifen. Durch die Datentransfers, welcher der DMAC nach seiner Konfiguration ohne CPU-Beteiligung ermöglicht, kann die System-Performance deutlich erhöht werden. Die Datentransfers können hierbei per Software oder über angeschlossene Peripherieelemente über sog. \emph{Requests} gestartet werden. Wird als steuerndes Element beispielsweise ein Hardware-Timer genutzt ermöglicht dies die zeitlich exakte Taktung von Datentransfers \cite[S. 6]{STmicroelectronics2016}, was im Projekt für den Abtastvorgang genutzt wird.

Der µC besitzt zwei unabhängige DMAC (Aufbau siehe \autoref{fig:dmac}), deren Anbindung an Peripherie und Speicher unterschiedlich ausfällt, um alle Ressourcen des Systems flexibel zu verwenden.\\

Der DMAC besitzt 3 Schnittstellen:
\begin{itemize}
	\item \emph{slave port} zur Programmierung des DMAs
	\item \emph{2 master ports} \begin{itemize}
		\item \emph{peripheral port}: peripherieseitiger Datenanschluss
		\item \emph{memory port}: speicherseitiger Datenanschluss
	\end{itemize}
\end{itemize}

\begin{figure}[H]
	\centering
     
	\caption{Blockdiagramm STM32-DMA-Controller aus \cite[S. 7]{STmicroelectronics2016}}
	\label{fig:dmac}
\end{figure}

Jeder Controller besitzt 8 Datenwege (\emph{Streams}), die separat für unterschiedliche Datentransfers konfiguriert werden können (die Transfers können aber nicht gleichzeitig laufen). Die Streams besitzen hierbei eine konfigurierbare Priorität und ein zentrales Modul, der \emph{Arbiter}, regelt den Zugriff der Streams auf die Ports in Abhängigkeit der Priorität und sorgt für einen deterministischen Ablauf der Transfers. Die einzelnen Streams besitzen noch eine Anzahl an \emph{Channeln}, über die der entsprechende Peripherie-Request für einen Stream ausgewählt werden kann (vgl. \cite[S. 7ff]{STmicroelectronics2016}). Die Zuordnung eines Peripherie-Requests zu einer Channel-Stream-Kombination kann dem Reference-Manual des Controllers entnommen werden (für den STM32F767: \cite[S. 252]{STmicroelectronics2024}).

\pagebreak

Jeder Stream besitzt außerdem einen 4-stufige \emph{FIFO}-Pufferspeicher (First-In-First-Out), welcher Latenzen beim Zugriff auf das Übertragungsmedium (Bus-Switch-Matrix) überbrücken kann und ein \emph{Verpacken/Entpacken der Daten} erlaubt (z.B.: input: 8bit-Pakete, output: 32bit-Pakete; siehe \autoref{fig:dma_fifo}).

\begin{figure}[H]
	\centering
     
	\caption{FIFO-Struktur aus \cite[S. 11]{STmicroelectronics2016} (Teilabbildung)}
	\label{fig:dma_fifo}
\end{figure}

\textbf{\underline{DMA-Transfers}}\\
Ein Transfer wird zunächst über die \emph{Quelladresse (source address)} und \emph{Zieladresse (destination address)} charakterisiert, hier kann der DMA so konfiguriert werden, dass die Adressen nach einem Transfer automatisch inkrementiert werden können. Somit lassen sich, im Speicher hintereinanderliegende, Daten einfach übertragen. Quell- oder Zieladresse können jeweils aber auch konstant gehalten werden (siehe \autoref{fig:periph_to_mem}).

\begin{figure}[H]
	\centering
     
	\caption{DMA Quell- und Zieladressinkrementierung aus \cite[S. 10]{STmicroelectronics2016}}
	\label{fig:dma_transfer_inc}
\end{figure}

Weitere wichtige Parameter sind die Übertragungsgröße (transfer size), die in einem dedizierten Register (\emph{NDTR} - Number of Data Transfers Register) abgelegt ist, und die Datenbreite (Byte, Half-word, Word). Der Inhalt des NDTR wird nach jedem Transfer entsprechend der Größe des Transfers dekrementiert. Hier wird noch zwischen Circular mode und Normale mode unterschieden. Beim Normal mode ist eine Transaktion (bestehend aus NDTR Transfers) bei NDTR=0 beendet. Der Stream wird deaktiviert und es finden bis zum nächsten Aktivieren des Streams keine Transfers mehr statt. Beim Circular mode wird bei NDTR=0 das Register NDTR mit dem Initialwert geladen und die Transfers beginnen erneut (auch die Adressregister werden mit den Initialwerten geladen) $\rightarrow$ Kreislauf (circular).\\

Die drei möglichen Transfer-Modi sind:
\begin{itemize}
	\item Peripheral-to-Memory (siehe Beispiel in \autoref{fig:periph_to_mem}))
	\item Memory-to-Peripheral
	\item Memory-to-Memory
\end{itemize}

Bei einem Timer-Überlauf des Hardware-Timers TIM1 findet ein DMA-Request statt (ein Stream wurde hierbei entsprechend konfiguriert). Dieser Request löst einen Daten-Transfer zwischen Ziel und Quelle aus (die Datenbreite wurde im Beispiel auf 1 Byte festgelegt). Anschließend werden die Adressen entsprechend der Datenbreite inkrementiert, um die Ziel- und Quelladresse für den nächsten Transfer vorzubereiten. Dieser Prozess geschieht so lange, bis ``Number of Transfers`` durchgeführt worden sind. Der Wert von NDTR wird nach dem Transfer dekrementiert.\\

\begin{figure}[H]
	\centering
     
	\caption{peripheral-to-memory-Transfer}
	\label{fig:periph_to_mem}
\end{figure}

Im Abtastsystem ist keine Inkrementierung der Quelladresse notwendig, da nur das Eingangsdatenregister ausgelesen werden muss, welches die Schnittstelle zum parallelen ADC-Interface darstellt (siehe \autoref{fig:data_acq_dma} im Entwurfsteil der FW).

\pagebreak

\textbf{\underline{DMA-Transferwege}}\\

Gemeinsames Übertragungsmedium ist die Bus-Switch-Matrix, die auch in den vorherigen Abbildungen schon dargestellt wurde. Der Zugriff auf diese wird mit Hilfe einer Arbitrierung nach einem round-robin-Algorithmus geregelt. 
Durch den Arbitrierungsvorgang oder die Blockierung des Übertragungsmediums durch einen anderen Bus-Master (z.B. die CPU) kann eine \emph{Latenz beim DMA-Transfer} entstehen.

\begin{figure}[H]
	\centering
     
	\caption{Systemarchitektur für STM32F76xxx $\mu$C aus \cite[S. 72]{STmicroelectronics2024}}
	\label{fig:sysarch_stm32f7}
\end{figure}

Nur Bus-Master (z.B.: Prozessor, DMA-Controller (in \autoref{fig:sysarch_stm32f7} rot hervorgehoben) können Lese- und Schreiboperationen initiieren.

\pagebreak

\subsection{Digitale Filterung (Preprocessing)}
\label{subsec:digital_filtering}

\subsubsection{Motivation und Grundlagen digitaler Filterung}
Digitale Filterung ist ein zentrales Element der digitalen Signalverarbeitung (DSP). Filter werden im Allgemeinen für zwei Hauptzwecke eingesetzt:
\begin{itemize}
	\item Trennung von Signalen, die miteinander überlagert wurden,

	\item Wiederherstellung von Signalen, die auf ihrem Übertragungsweg oder bei der Messung verzerrt wurden \cite[S. 261]{Smith1999}.
\end{itemize}

Während analoge Filter durch elektronische Schaltungen realisiert werden, bieten digitale Filter eine wesentlich höhere Präzision und Flexibilität. Sie können sehr steile Übergänge zwischen Durchlass- und Sperrbereich (passband und stopband) erzeugen und zeigen kaum Toleranzprobleme wie analoge Filter. Beim analogen Filterdesign ist die Beherrschung von Bauteiltoleranzen von wesentlicher Bedeutung \cite[S. 262]{Smith1999}. Digitale Filterung bietet sich bei Anwendungen mit Mikrocontrollern an, da die Filter-Algorithmen direkt einprogrammiert werden können und eine analoge Filterschaltung ersetzen oder reduzieren können.

\subsubsection{Filterklassifikation}

\underline{Einteilung nach Signalcharakteristik}\\
Die Einteilung der Filter richtet sich einerseits danach, in welcher Form die Information im Signal enthalten ist \cite[S. 265]{Smith1999}.

\begin{itemize}
	\item \emph{Zeitbereich (time-domain):}\\
	Die Information ist direkt in der Form des Signals enthalten.\\
	Bsp.: Glätten von Messdaten, DC-Offset-Entfernung, Signalerkennung.\\
	$\rightarrow$ Die Sprungantwort (step-response) ist hier entscheidend.

	\item \emph{Frequenzbereich (frequency-domain):}\\
	Die Information steckt in den Frequenzkomponenten des Signals.\\
	Bsp.: Trennung von Audiosignalen oder Herausfiltern bestimmter Störfrequenzen.\\
	$\rightarrow$ Der Frequenzgang (frequency-response) ist hier entscheidend.
\end{itemize}

\pagebreak

\underline{Einteilung nach Implementierung}\\
Die Einteilung der Filter richtet sich einerseits danach, in welcher Form die Information im Signal enthalten ist \cite[S. 265]{Smith1999}.

\begin{itemize}
	\item \emph{FIR-Filter (Finite Impulse Response):}\\
	Umsetzung erfolgt durch \textbf{Faltung (Convolution)} des Eingangssignals mit einem endlichen Filterkern (\emph{engl. filter kernel}). Ein Ausgangswert wird berechnet, indem Eingangswerte mit zuvor definierten Gewichtungsfaktoren multipliziert und anschließend aufaddiert werden.\\
	Eigenschaften:
	\begin{itemize}
		\item Stabil und vorhersagbar,
		\item Endliche Impulsantwort,
		\item Einfach zu implementieren, aber rechenintensiv.
		\item Beispiel: Moving Average Filter.
	\end{itemize}

	\item \emph{IIR-Filter (Infinite Impulse Response):}\\
	Umsetzung durch \textbf{Rekursion}, bei der sowohl aktuelle Eingangswerte als auch frühere Ausgangswerte zur Berechnung herangezogen werden.\\
	Eigenschaften:
	\begin{itemize}
		\item Sehr effizient (weniger Rechenaufwand),
		\item Theoretisch unendliche Impulsantwort,
		\item Gefahr der Instabilität bei fehlerhafter Parametrierung.
		\item Beispiel: digitale Tiefpassfilter auf Basis analoger Schaltungen.	
	\end{itemize}
\end{itemize}

\pagebreak

\subsubsection{Gleitender Mittelwertfilter}

Der \emph{gleitende Mittelwertfilter (engl. Moving Average Filter - MAF)} ist einer der einfachsten und am häufigsten eingesetzten digitalen Filter. Er arbeitet, indem er für jedes Ausgabesample den Mittelwert aus einer festen Anzahl aufeinanderfolgender Eingangssamples berechnet \cite[S. 277]{Smith1999}.
Seine Hauptaufgabe besteht darin, zufälliges Rauschen zu reduzieren (siehe \autoref{fig:mov_avg_filter_signal}), während plötzliche Signaländerungen (Steps) möglichst gut erhalten bleiben.

\begin{figure}[H]
	\centering
     
	\caption{\centering Anwendung eines MAF unterschiedlicher Fensterbreite\\
				\footnotesize
				(a) Eingangssignal, (b) Ausgangssignal $M=11$, (c) Ausgangssignal $M=51$\\				(Figure 15-1 aus \cite[S. 279]{Smith1999})}
	\label{fig:mov_avg_filter_signal}
\end{figure}

\underline{Grundidee}
Für ein Fenster der Breite $M$ ergibt sich das Ausgangssignal $y[i]$ aus dem Eingangssignal $x[i]$ durch:
\begin{equation}
	y[i]=\frac{1}{M}\sum_{j=0}^{M-1}x[i+j]
\end{equation}
Es ist zu erkennen, dass die rechtsseitigen Eingangswerte zum Ausgangswert aufsummiert werden. Eine alternative Umsetzung wäre es die aufzusummierenden Eingangswerte symmetrisch um den Ausgangswert zu wählen (Beispiel für einen Ausgangswert):
\begin{equation}
	y[80]=\frac{x[78]+x[79]+x[80]+x[81]+x[82]}{5}
\end{equation}

Damit entspricht der Moving Average Filter einer Faltung des Eingangssignals mit einem rechteckigen Filterkern \cite[S. 277f]{Smith1999}.\\

Für das Projekt wurde der Filter kumulativ und rekursiv implementiert und nach den Algorithmen in \autoref{lst:moving_avg_filter_algorithm_cumulative} und \autoref{lst:moving_avg_filter_algorithm_recursive} im \autoref{subsubsec:preprocessing_concept} umgesetzt.

\subsection{Parallele Prozesse und Nebenläufigkeiten in Python}

\subsubsection{Threads in Python}
	
	Ein Thread ist ein paralleler Ausführungsstrang innerhalb eines Programms. Alle Threads teilen sich den selben Speicherbereich. 
	Dadurch kann es zu Wettlaufbedingungen kommen oder zu unvorhersehbaren Verhalten. Der Zugriff auf gemeinsame Daten muss daher synchronisiert werden, z.B. mit Locks, Semaphoren oder Warteschlangen. 
	Durch den Global Interpreter Lock (GIL), ein zentrales Konzept im Standard-Python-Interpreter CPython, 
	kann zu einem Zeitpunkt immer nur ein Thread, Python-Bytecode ausführen. Das heißt, auch wenn für einen Job mehrere Threads gestartet werden, arbeitet immer nur ein Thread gleichzeitig.
	Dieses Prinzip widersricht zwar der Idee von paralleler Ausführung, jedoch darf ein anderer Thread Programmcode ausführen, wenn der Thread gerade auf eine Eingabe wartet.
	Das GIL wird in Python genutzt, da es die Verwaltung von Python-Objekten im Speicher vereinfacht. Dies ist vor allem wichtig, da der der Speicher in Python typischerweise
	automatisch verwaltet wird (vgl. \cite{Lang2024} Abschnitt ``Was sind Threads in Python{?}``). 

	Threading eignet sich vor allem für E/A-lastige Aufgaben, die mit Datenaustausch verbunden sind.

	\underline{Synchronisation}
	\begin{itemize}
		\item Locks: Sperren, die verhindern, dass mehrere Threads gleichzeitig auf die selben Daten zugreifen.
		\item Semaphoren: Begrenzen die Anzahl gleichzeitiger Zugriffe auf eine Ressource.
		\item Warteschlange (Queues): Erlauben thread-sicheren Austausch von Datenobjekten, nach dem FIFO-Prinzip.
	\end{itemize}

\subsubsection{Multiprocessing in Python}	
	
	Beim multiprocessing werden mehrere, vollständig unabhängige Prozesse gestartet. Jeder Prozess ist eine eigene Instanz des Programms mit eigenem Speicherbereich. Dies führt dazu, dass die
	Kommunikation zwischen den jeweiligen Prozessen komplexer ist. Hierfür stellt das Python-Modul multiprocessing Funktionen und Klassen bereit.

	Multiprocessing kann die Leistungsfähigkeit bei rechenintensiven Aufgaben deutlich steigern, bringt aber auch Overhead durch Speicherbedarf und zusätzliche Komplexität in der Verwaltung mit.

	\underline{Synchronisation}
	\begin{itemize}
		\item Pipes: Unidirektionale Kanäle für Datenübertragung zwischen Prozessen. 
		\item Shared Memory: Gemeinsamer Speicherbereich für Datenaustausch.
	\end{itemize}

\begin{figure}[H]
	\centering
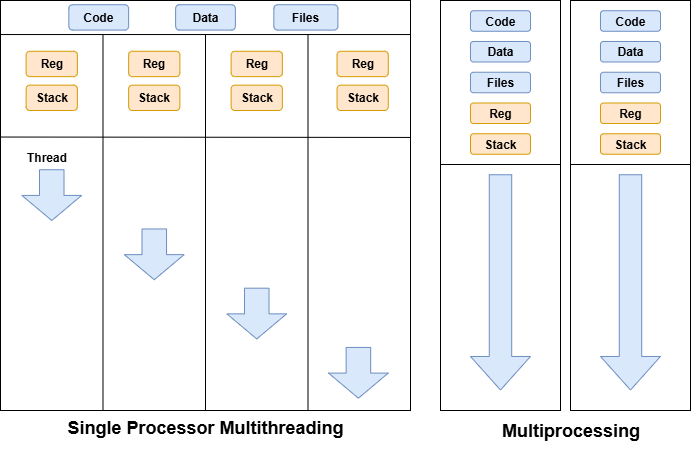
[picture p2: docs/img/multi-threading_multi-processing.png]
     
	\caption{Vergleich Multi-Threading und Multi-Processing}
	\label{fig:multithr/pro}
\end{figure}

In unserem Projekt wurden Threads verwendet, da die Anwendung hauptsächlich E/A-gebunden ist. Zusätzlich wird ein gemeinsamer Speicher benötigt, damit die Messdaten an die Benutzeroberfläche 
übergeben werden können. Die Kommunikation wurde mit zwei Warteschlangen realisiert, eine dient zur Übergabe von Statusmeldungen von der FSM zur Benutzeroberfläche (GUI) und die andere zur
Übergabe von Befehlen von der GUI an die FSM (vgl. \cite{Lang2024} Abschnitt ``Was ist Multiprocessing in Python{?}``). 

%%%%%%%%%%% Projektkonzeption %%%%%%%%%%%
\section{Projektkonzeption}
\subsection{Vorgehensweise}
Das übergeordnete Vorgehen folgte einem strukturierten Prozess, der sich gut durch das \textbf{V-Modell} visualisieren lässt. Diese Vorgehensweise eignete sich insbesondere aus drei Gründen: \emph{Erstens}, Änderungen an Hardware sind nach deren Umsetzung nur schwer möglich, was iterative Prozesse sehr aufwendig macht. \emph{Zweitens} standen die Projektziele von Beginn an eindeutig fest. \emph{Drittens} waren die Aufgabenbereiche klar voneinander abgegrenzt. Zudem handelte es sich um ein überschaubares Projekt.

\begin{figure}[H]
\centering
     
	\caption{V-Modell}
\end{figure}

Im Folgenden werden die einzelnen Phasen und zugehörigen Validierungsschritte kurz erläutert.\vspace{0.1cm}\\
\underline{Anforderungsanalyse und Abnahmetest}\\
In enger Abstimmung mit dem betreuenden Professor wurden die grundlegenden Anforderungen definiert. Dazu gehörten unter anderem Bandbreite, Abtastrate, Auflösung und Eingangsspannungsbereich. Der spätere Abnahmetest bestand darin zu überprüfen, ob das entwickelte System diese Vorgaben in einer realistischen Versuchsumgebung erfüllte.\vspace{0.1cm}\\
\underline{Systemdesign und Systemtest}\\
Anschließend wurden die grundlegenden Systemfunktionen festgelegt, die zur Erfüllung der Anforderungen notwendig waren. Dazu zählten Signalaufnahme, Digitalisierung, Weiterleitung über USB und Visualisierung am PC. Im Systemtest wurde das fertige Gerät als Gesamtsystem geprüft.\vspace{0.1cm}\\
\underline{Architekturdesign und Integrationstest}\\
In dieser Phase erfolgte die Aufteilung des Systems in die Bereiche Hardware, Firmware und Software. Dabei wurden die Schnittstellen definiert, die ermöglichen sollten, die Module weitgehend unabhängig voneinander zu entwickeln. Diese wurden während des Komponentendesigns bei Bedarf konkretisiert. Im Integrationstest wurde die Zusammenarbeit dieser Module überprüft, insbesondere die zuverlässige Kommunikation zwischen den Subsystemen.\vspace{0.1cm}\\
\underline{Komponentendesign und Komponententest}\\
In dieser Phase wurden die Teilsysteme detailliert ausgearbeitet. Es wurden Konzepte erstellt, Bauteile gewählt, Implementierungsmöglichkeiten abgewogen etc. Jedes Subsystem wurde einzeln getestet, z. B. Spannungsversorgung und ADC in der Hardware, Speicherzugriffe in der Firmware oder Datenanzeige in der Software.\vspace{0.1cm}\\
\underline{Implementierung}\\
In der zentralen Phase wurden die geplanten Komponenten umgesetzt. Dies umfasste das Layout der Schaltungen, die Programmierung der Firmware sowie die Entwicklung der PC-Software. Ziel war es, die entworfenen Module funktionsfähig zu realisieren und für die Integration bereitzustellen.\\

\textbf{Organisation und Zusammenarbeit}\\
Die Zusammenarbeit erfolgte hauptsächlich über ein gemeinsames Projektteam in Microsoft Teams. Dieses war in mehrere Kanäle gegliedert: einen allgemeinen Kanal für projektübergreifende Informationen, jeweils eigene Kanäle für Hardware, Firmware und Software sowie zusätzliche Kanäle für die Schnittstellen. Diese Struktur erleichterte die Ablage von Quellen, Materialien und Informationen und stellte die Übersicht über das gesamte Projekt sicher.\\
Die Abstimmung innerhalb des Teams erfolgte in regelmäßigen Treffen, in denen abgeschlossene Arbeitspakete dokumentiert und neue Zielvorgaben bis zum nächsten Treffen festgelegt wurden. Die Ergebnisse wurden jeweils in Protokollen festgehalten. Eine detaillierte Auflistung der Tätigkeiten sowie deren Zuordnung zu den einzelnen Teammitgliedern findet sich im \autoref{subsec:appendix_a_responsibilities} ``\nameref{subsec:appendix_a_responsibilities}``.
\pagebreak

\subsection{Anforderungen}
\label{subsec:requirements}
Die Anforderungen an das Projekt wurden in Zusammenarbeit mit dem betreuenden Professor sowie dem Laboringenieur des MCT-Labors Hr. Lenkowski nach einer ersten Machbarkeitsanalyse im Hinblick auf die definierten Projektziele festgelegt. Neben den obligatorischen Grundfunktionen eines digitalen Speicheroszilloskops (siehe \autoref{subsec:oscilloscope_func} ``\nameref{subsec:oscilloscope_func}``) wurden folgende zentrale technische Parameter bestimmt:
\begin{itemize}
\item Bandbreite: 1 MHz (Grenzfrequenz des Anti-Aliasing-Filters)
\item Abtastrate: mindestens 10 MS/s (siehe \autoref{subsec:aaf_nyquist})
\item Auflösung: mindestens 10 Bit
\item Analoge Eingangsspannung: ± 5 V
\item Offset: ± 5 V (bezogen auf die Eingangsspannung)
\end{itemize}

Ein weiterer wesentlicher Aspekt war die \emph{Spannungsversorgung} des Systems, für die bewusst keine strikten Anforderungen formuliert wurden. Auf diese Weise sollte während des Entwicklungsprozesses ein höheres Maß an Flexibilität gewährleistet werden, um den Fokus auf die grundlegende Funktionalität des Gesamtsystems legen zu können. Die Signalaufnahme sollte auf \emph{einen Kanal} beschränkt bleiben, um Schwierigkeiten bei der Synchronisation mehrerer ADCs sowie den erhöhten Verwaltungsaufwand für Mehrkanalsysteme zu vermeiden. Außerdem sollte die Möglichkeit bestehen, dass Oszilloskop mit einem Standardtastkopf zu betreiben. Zusätzlich war vorgesehen, die Baugruppe als \emph{erweiterbares Steckboard für ein Mikrocontroller-Entwicklungsboard} umzusetzen, wodurch die Komplexität reduziert und die Funktionalität der Baugruppe in den Vordergrund gestellt werden konnte.\\

Für die Schnittstelle zwischen ADC und Mikrocontroller wurde eine \emph{parallele Anbindung} vorgesehen, da eine serielle Übertragung über SPI bei den geforderten Abtastraten eine zu hohe Taktfrequenz erfordert hätte. Dies hätte einen direkten Datentransfer in den Speicher des Mikrocontrollers nicht mehr zuverlässig ermöglicht. Für die zentrale Recheneinheit wurde sich auf die \emph{Mikrocontroller der STM32-Familie} beschränkt, um vorhandene Kenntnisse aus den Modulen Mikrocomputertechnik und Embedded Systems gezielt einsetzen zu können. Die Kommunikation mit dem PC sollte über eine \emph{USB-Schnittstelle} erfolgen, um eine möglichst uneingeschränkte Kompatibilität zu gewährleisten. Auf dem PC war die Entwicklung einer \emph{eigenen Anwendung zur Visualisierung und Verarbeitung der Messdaten} vorgesehen. Diese sollte über \emph{genormte Kommandos} kommunizieren, sodass auch eine Integration in gängige Entwicklungs- und Analyseumgebungen wie \emph{LabVIEW} oder \emph{MATLAB} möglich wäre.\\

Neben diesen zentralen Vorgaben wurden auch \emph{optionale Erweiterungen} definiert, die nicht als kritisch für den Projekterfolg eingestuft wurden oder den vorgesehenen Arbeitsumfang überschritten. Dazu zählten insbesondere die Implementierung eines \emph{Logikanalysators} mit Protokolldekodierung gängiger Schnittstellen (z. B. SPI, I²C, UART), die Realisierung einer \emph{Fast-Fourier-Transformation (FFT)} zur Spektrumanalyse, die Erweiterung um einen \emph{zweiten analogen Kanal}, die Integration von \emph{Mathematik- und Messfunktionen} sowie die Nutzung unterschiedlicher \emph{Triggerbedingungen}. Weitere Optionen im Hardwarebereich betrafen eine \emph{Optimierung hinsichtlich elektromagnetischer Verträglichkeit (EMV)}, eine \emph{Minimierung des Rauschverhaltens}, die \emph{Stromversorgung über USB} sowie die \emph{Integration des Mikrocontrollers direkt auf der Baugruppe}.

\subsection{Konzept / Architektur}
Parallel zu den Anforderungen wurde ein Konzept entwickelt, um die grundlegende Architektur und Aufgabenverteilung des Projekts festzulegen. Zu Beginn entstand ein grundlegendes, rein funktionales Übersichtsbild (siehe \autoref{fig:block_concept} in \autoref{sec:appendix_a}). Dieses stellt die wesentlichen Signalflüsse und Verarbeitungsschritte dar, die für die Realisierung des USB-Oszilloskops erforderlich sind. Der Signalpfad führt dabei vom Device under Test (DUT) über die Signalerfassung zur Speicherung der Rohdaten und weiter zur Verarbeitung auf PC-Ebene. Dieses Schema diente als Orientierungshilfe für die weiteren konzeptionellen Schritte, ohne jedoch bereits konkrete Funktionseinheiten Bauteile oder Schnittstellen festzulegen.\\

Auf Basis dieser funktionalen Skizze sowie des in der Fachliteratur beschriebenen Grundaufbaus eines digitalen Speicheroszilloskops (siehe \autoref{subsec:oscilloscope_func}) wurde schließlich ein Gesamtkonzept entwickelt, das Funktionseinheiten definiert und den jeweiligen Bereichen Hardware, Firmware und Software zuordnet (siehe \autoref{fig:complete_concept}).

\begin{figure}[H]
	\centering
     
	\caption{Gesamtkonzept des USB-Oszilloskops (nach \cite[S. 216]{Muehl2020})}
	\label{fig:complete_concept}
\end{figure}

Ausgehend von diesem Konzept und der klaren Aufteilung in die Bereiche Hardware, Firmware und Software, wurden die entsprechenden Schnittstellen festgelegt und die Aufgabenbereiche verteilt.

\pagebreak

%%%%%%%%%%% Realisierung %%%%%%%%%%%
\section{Hardware (HW)}

Die Entwicklung der Hardware umfasste im Wesentlichen den \emph{Schaltplanentwurf, das Leiterplattenlayout, die Fertigung sowie den anschließenden Test} eines Aufsteckmoduls für den eingesetzten Mikrocontroller bzw. das zugehörige Nucleo-Board. Kernaufgabe dieser Baugruppe war die \emph{Signalaufnahme und -konditionierung} sowie die \emph{Wandlung des analogen Eingangssignals in ein digitales Signal}.

\subsection{Entwurf}

In der Entwurfsphase wurden Konzepte für die einzelnen Funktionaltäten erstellt und in einen Schaltplan umgesetzt, sowie die entsprechenden Bauelemente gewählt.

\subsubsection{Auswahl des ADCs}

Die zentrale Entscheidung im Hardwareentwurf war die Auswahl eines geeigneten \emph{Analog-Digital-Umsetzers (ADC)}. Grundlage hierfür bildeten die zuvor definierten Projektanforderungen, insbesondere die \emph{Signalbandbreite von 1 MHz} und die daraus abgeleitete Abtastrate von 10 MS/s (vgl. \autoref{subsec:aaf_nyquist}). Darüber hinaus wurde eine \emph{Auflösung von mindestens 10 Bit} sowie ein \emph{analoger Eingangsspannungsbereich von $\pm$ 5 V} gefordert, wobei letzterer bei Bedarf über einen Spannungsteiler realisiert werden konnte. Da im Projekt lediglich ein einzelner Kanal vorgesehen war, genügte ein einkanaliger ADC. Trotz der deutlich geringeren Komplexität einer Anbindung über SPI wurde eine parallele Schnittstelle gewählt, da diese aufgrund der seriellen Übertragung einen deutlich höheren Takt erfordert hätte.\\

Neben diesen grundlegenden Anforderungen wurden weitere Parameter berücksichtigt, unter anderem das Rauschverhalten (SINAD, THD, ENOB…) sowie die Linearitätseigenschaften (INL, DNL). Um eine hohe Flexibilität im Entwicklungsprozess zu gewährleisten, fiel die Wahl auf einen Baustein, der sowohl im single-ended als auch im differenziellen Betrieb eingesetzt werden kann. Zusätzlich sollte er im Dual-Supply- wie auch im Single-Supply-Betrieb einsetzbar sein und auf der digitalen Seite sowohl mit 3.3 V als auch mit 5 V betrieben werden können. Auch die Option zur Verwendung einer internen oder externen Referenzspannung war ein relevantes Kriterium, um die Anpassungsfähigkeit im späteren Entwicklungsverlauf zu erhöhen. Da die Wandlungslatenz nicht die primäre Einschränkung darstellte und vielmehr die Übertragungsgeschwindigkeit zwischen Mikrocontroller und PC der begrenzende Faktor war, wurde hinsichtlich der Architektur ein Pipeline-ADC ausgewählt. Dies ermöglichte im Vergleich zum Flash ADC eine höhere Auflösung (10 oder 12 Bit), bei gleichzeitiger Einhaltung eines annehmbaren Preisrahmens. Auch die Verfügbarkeit von SMD-Bauformen war ein wichtiges Kriterium.\\

Nach eingehender Recherche und Vergleichen bei verschiedenen Bauteillieferanten konnte mit dem \href{https://www.analog.com/en/products/ltc1420.html}{LTC1420} von Linear Technology ein ADC identifiziert werden, der alle definierten Anforderungen erfüllt. Er bietet mit \emph{12 Bit} eine höhere Auflösung als ursprünglich gefordert, zeichnet sich durch eine hohe Flexibilität im Betrieb (Single- oder Dual-Supply, differentiell oder single-ended, interner oder externer Referenzbetrieb) aus und weist zugleich ein \emph{sehr gutes Rauschverhalten} auf. Dieses zeigt sich insbesondere darin, dass die \emph{effektive Auflösung (ENOB)} nahe an der nominalen Bitzahl liegt (siehe Datenblatt \cite{LinearTechnology1420}, Berechnung von ENOB aus SINAD).

\subsubsection{Anforderungen an die Signalaufnahme und -konditionierung}

Nach der Auswahl des ADC mussten die Anforderungen an die \emph{Signalkonditionierung} sowie an die \emph{Signalaufnahme} spezifiziert werden. Für die Signalaufnahme war vorgesehen, dass diese ebenfalls über einen \emph{Tastkopf} möglich sein sollte. Daraus ergaben sich die Notwendigkeit einer \emph{BNC-Buchse} als Eingangsschnittstelle sowie ein \emph{Eingangswiderstand von 1 M$\Omega$}. Eine Anpassung der Eingangs- oder Leitungsimpedanz war aufgrund der im Projekt relevanten Frequenzen nicht erforderlich.\\

Der \emph{LTC1420} weist eine durch die Versorgungsspannung begrenzte maximale absolute Eingangsspannung auf. Im \emph{Single-Supply-Betrieb} liegt der Eingangsbereich zwischen 0 V und VDD (typisch 5 V), während er im \emph{Dual-Supply-Betrieb} durch VDD und VSS definiert wird. Der \emph{differenzielle Eingangsspannungsbereich} ist direkt proportional zur \emph{Referenzspannung (VREF)} und beträgt bei \emph{VREF = 5 V (maximal zulässig laut Datenblatt)} $\pm$2,5 V (entspricht 5 Vpp zwischen VIN+ und VIN–). Zur Realisierung eines Oszilloskop-Eingangsbereichs von $\pm$5 V (10 Vpp) war daher eine \emph{Pegelabsenkung} am Eingang vorzusehen. Entsprechend wurde eine \emph{maximale absolute Eingangsspannung von $\pm$10 V} an der BNC-Buchse festgelegt \cite[S. 1f]{LinearTechnology1420}.\\

Um auch bei Eingangssignalen mit geringerer Amplitude die \emph{volle Auflösung des ADC} zu nutzen, wurde eine \emph{variable Eingangsspannungsskalierung} vorgesehen. Zusätzlich war ein \emph{einstellbarer DC-Offset} erforderlich, um Signale mit Gleichanteil in den nutzbaren Wandlungsbereich zu verschieben. Darüber hinaus sollte eine \emph{umschaltbare AC-Kopplung} über einen Längskondensator die Unterdrückung von Gleichanteilen ermöglichen. Außerdem war ein \emph{Anti-Aliasing-Filter} mit Grenzfrequenz und Sperrbanddämpfung nach dem \emph{Nyquist-Kriterium} auszulegen, um Alias-Effekte und daraus resultierende Signalverzerrungen bei der Digitalisierung zu vermeiden (siehe \autoref{subsec:aaf_nyquist}). Außerdem war eine analoge Triggereinrichtung vorgesehen.

\subsubsection{Konzept der Signalaufnahme und- konditionierung}

Auf Basis der Anforderungen an Signalaufnahme und -konditionierung wurde zunächst ein Gesamtkonzept für den Hardwareteil erarbeitet. Diese Vorarbeit war notwendig, weil sich die Funktionsblöcke des Hardwareteils gegenseitig beeinflussen und zentrale Architekturentscheidungen früh zu treffen waren. Zwei Fragen standen dabei zu Beginn im Vordergrund. Erstens die Wahl zwischen Single-Ended und differenzieller Signalführung im analogen Frontend. Zweitens die Versorgung des Analogteils mit Single- oder Dual-Supply. Trotz der Vorteile eines differenziellen Frontends wie Gleichtaktunterdrückung und Messung gegen ein vom Gerätemassepunkt unabhängiges Bezugspotenzial fiel die Entscheidung zugunsten einer Single-Ended-Lösung. Ausschlaggebend waren die deutlich größere Bauteilauswahl, der geringere Schaltungsaufwand und die vermiedene doppelte Signalführung. Für die Versorgung wurde eine Dual-Supply-Variante vorgesehen. Eine reine Single-Supply-Auslegung hätte einen virtuellen Massepunkt durch eine Offsetschaltung im analogen Frontend und geringe Aussteuerungsreserven erfordert und wäre damit näher an den Grenzwerten von Operationsverstärkern und ADC gelegen.\\

Im nächsten Schritt wurde der nutzbare Eingangsspannungsbereich des ADC festgelegt. Da der gewählte Umsetzer eine Anpassung über die Referenzspannung erlaubt, wird der Bereich über VREF in Verbindung mit einem DAC gesetzt. Diese Lösung ist im Datenblatt vorgesehen und ersetzt einen variablen analogen Verstärker im Frontend, womit eine aufwendige OPV-Schaltung oder Bauteilrecherche vermieden werden konnten. Zusätzlich verringert sich damit die Komplexität des Signalpfads. Es entfallen zusätzliche Rausch- und Stabilitätsrisiken, die bei verstellbaren Verstärkungsstufen erfahrungsgemäß auftreten. Aus dem selben Grund wird der notwendige Gleichspannungs-Offset nicht durch eine separate OPV-Schaltung erzeugt, sondern über den negativen Analogeingang des ADC eingebracht. Das analoge Frontend stellt damit nur die Funktionen bereit, die unmittelbar für Impedanz, Pegelanpassung, Kopplung, Pufferung, Triggerabgriff und Bandbegrenzung erforderlich sind.\\

Das Analoge Frontend beginnt unmittelbar nach der BNC-Buchse mit einer Eingangsimpedanz von 1 M$\Omega$. Dieser Widerstand ist Teil eines Spannungsteilers, der die Pegel auf den zuvor definierten ADC-Bereich absenkt. Um den Teiler nicht zu belasten, folgt ein hochohmiger Spannungsfolger als Impedanzwandler. Zwischen Teilerknoten und OPV-Eingang ist eine schaltbare Kopplung vorgesehen. Durch den hohen Eingangswiderstand des Puffers entsteht bereits mit kleinen Kapazitäten ein Hochpass mit niedriger Grenzfrequenz, sodass im AC-Betrieb auch langsame Signalanteile kaum beeinflusst werden. Hinter dem Impedanzwandler wird das Triggersignal abgegriffen und einer eigenen Auswertestufe zugeführt, die ein digitales Triggerereignis an den Mikrocontroller weitergibt. Vor dem positiven Analogeingang des ADC liegt das Anti-Aliasing-Filter, dessen Auslegung im entsprechenden Kapitel (\autoref{subsubsec:aaf_concept}) beschrieben ist und das die erforderliche Bandbegrenzung sicherstellt. Den Abschluss des Konzepts bilden die Versorgungsblöcke. Sie stellen die duale Versorgung für Operationsverstärker und Peripherie bereit.\\

Das beschriebene Konzept reduziert den Schaltungsaufwand auf das notwendige Minimum, nutzt die Stärken des ADC bei Bereichs- und Offseteinstellung und minimiert zugleich Empfindlichkeit gegen Rauschen, Schwingen und Toleranzen. Es schafft damit eine belastbare Grundlage für die nachfolgenden Teilschaltungen. Das Konzept ist in dem in \autoref{fig:afe_diagram} skizzierten Blockschaltbild dargestellt.

\begin{figure}[H]
	\centering
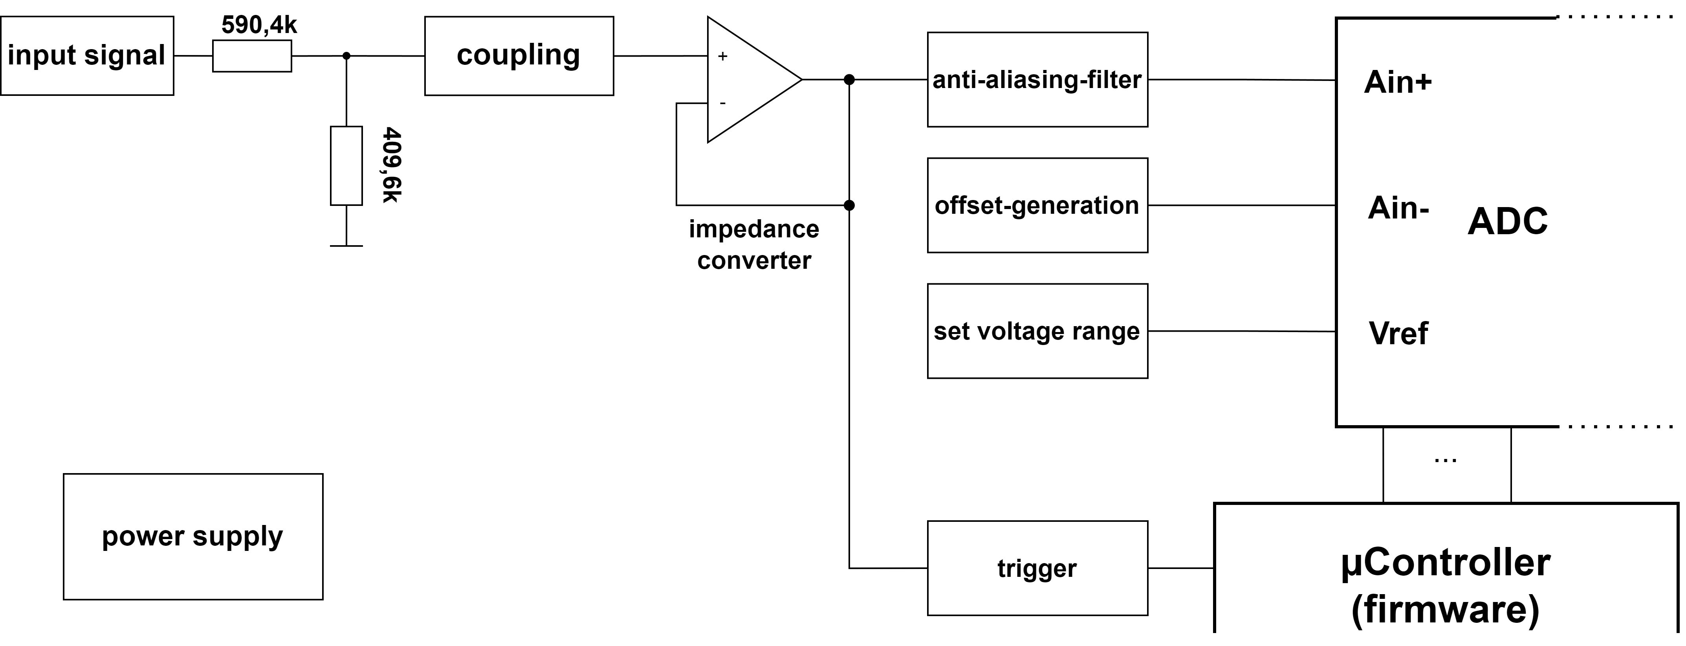
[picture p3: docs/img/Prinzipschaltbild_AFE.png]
     
	\caption{Prinzipschaltbild des Hardware-Konzepts}
	\label{fig:afe_diagram}
\end{figure}

Nach Abschluss des Gesamtkonzepts für die Hardwareschaltung wurden die einzelnen Funktionsbereiche in sinnvoller Reihenfolge ausgearbeitet und schrittweise in einen Schaltplan überführt. Als Werkzeug diente KiCad\footnote{\href{https://docs.kicad.org/}{KiCad Dokumentation}}, das später auch für die Erstellung des Platinenlayouts verwendet wurde. Die Entscheidung für KiCad fiel aufgrund der offenen Lizenz und der niedrigen Einstiegshürde.

\subsubsection{Anpassung des Spannungsbereichs}

Zunächst wurde die Methode zur Einstellung des Spannungsbereichs festgelegt, weil diese die Auslegung von Teilerverhältnis, Offset und maximal möglicher Eingangsspannung bestimmt. Gewählt wurde die Einstellung über einen Digital-Analog-Umsetzer, da diese Vorgehensweise im Datenblatt beschrieben ist und bereits eine entsprechende Schaltung vorgegeben wird. Der ADC-Eingangsbereich wird ohne Vorverstärkung durch $\frac{V_{ref}}{2}$ bestimmt \cite[S. 9]{LinearTechnology1420}. Die im Datenblatt gezeigte Beschaltung (siehe \autoref{fig:adc_reference_circuit}) nutzt den im LTC1420 integrierten Operationsverstärker in einer invertierenden Konfiguration mit Bezugspotenzial am nichtinvertierenden Eingang. Über die externe Beschaltung ergibt sich ein invertierender Verstärker mit einer Verstärkung von 1, dessen Bezugspotenzial um 2.048 V angehoben ist. Die Beziehung zu $V_{ref}$ lässt sich wie folgt herleiten:\\

Unter der Annahme, dass die Differenzspannung der OPV-Eingänge und die Eingangsströme jeweils Null sind, gelten die Gleichungen\\

\begin{equation}
	I_1 = I_2
\end{equation}

und damit

\begin{equation}
	\frac{U_1}{R_1} = \frac{U_2}{R_2}
\end{equation}

\begin{equation}
	U1 = U_{DAC} - U_{int}
\end{equation}

\begin{equation}
	U2 = U_{int} - V_{ref}
\end{equation}

daraus folgt

\begin{equation}
	\frac{U_{DAC} - U_{int}}{R_1} = \frac{U_{int} - V_{ref}}{R_2}
\end{equation}

umgestellt nach $V_{ref}$

\begin{equation}
	V_{ref} = -\frac{R_2}{R_1} \cdot (U_{int} - V_{ref}) + U_{int}
\end{equation}

Für $R_1 = R_2 = 5 k\Omega$ und $U_{int} = 2.048V$ ergibt sich

\begin{equation}
	V_{ref} = -U_{DAC} + 4.096V
\end{equation}

\begin{figure}[H]
	\centering
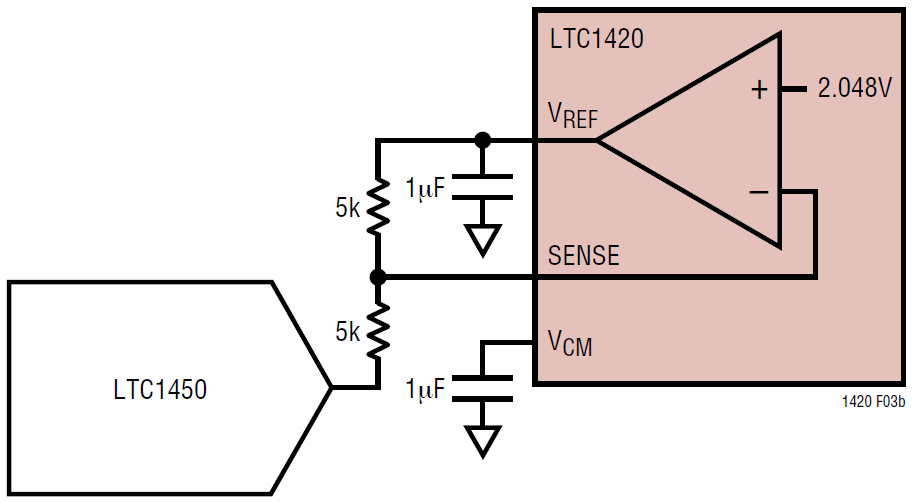
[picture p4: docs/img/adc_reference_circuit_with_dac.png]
     
	\caption{Ansteuerung von $V_{ref}$ mittels DAC (aus \cite[S. 9]{LinearTechnology1420})}
	\label{fig:adc_reference_circuit}
\end{figure}

Auf Basis dieser Formel ist in der gezeigten Beschaltung ein theoretischer Einstellbereich von $V_{ref}$ zwischen 0 V und 4.096 V möglich, was einem differentiellen Eingangsspannungsbereich von $\pm$ 2.048V entspricht. Als DAC wird, wie im Datenblatt beschrieben, der LTC1450 eingesetzt (siehe \autoref{fig:adc_reference_circuit}). Die Auflösung beträgt 1 mV bezogen auf den ADC-Eingang, entsprechend den 12 Bit des DAC. Die Beschaltung des DAC wird aus dem Datenblatt abgeleitet. Zur Nutzung der internen Referenz des DAC sind REFOUT und REFHI verbunden. An diesen beiden Knoten liegt ein RC-Glied zur Reduzierung des Referenzrauschens, ausgeführt nach den Empfehlungen des Datenblatts. REFLO ist an die analoge Masse geführt (siehe \autoref{fig:ltc1450_block_diagram}) \cite[S. 1 u.7]{LinearTechnology1450}.\\

Die digitale Ansteuerung des LTC1450 folgt der im Datenblatt erläuterten Logik. Die Eingänge CSLSB, CSMSB und WR sind low-aktiv und schalten die Input-Latches transparent, wobei WR zum Schreiben aktiv sein muss und die beiden anderen jeweils die unteren acht beziehungsweise die oberen vier Bit ansteuern \cite[S. 1,7 u. 10]{LinearTechnology1450}.

\begin{figure}[H]
	\centering
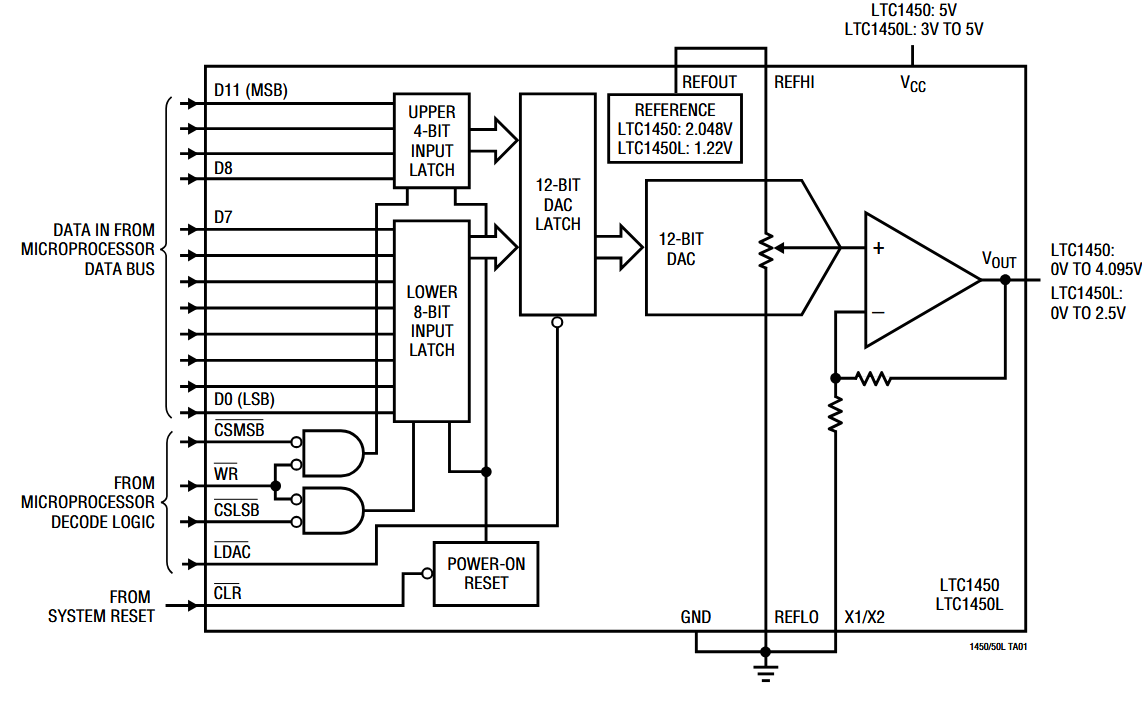
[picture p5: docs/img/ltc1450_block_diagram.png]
     
	\caption{Blockschaltbild des LTC1450 aus \cite[S. 1]{LinearTechnology1450}}
	\label{fig:ltc1450_block_diagram}
\end{figure}

Da die ausgegebenen Werte in diesem Projekt direkt in die Input-Latches geschrieben werden, sind alle drei Signale dauerhaft auf Low gelegt, sodass immer alle zwölf Bit in die Latches übernommen werden. Das Update des Ausgangs erfolgt ausschließlich über den LDAC-Eingang, der die Inhalte der Input-Latches in die DAC-Latches übernimmt und damit die Ausgangsspannung aktualisiert. Der CLR-Eingang setzt alle Latches auf Null und damit den Ausgang des invertierenden Verstärkers sofort auf den höchsten möglichen Wert für $V_{ref}$, also den größtmöglichen Eingangsspannungsbereich. Die Ausgangsverstärkung des DAC-Puffers wird über X1/X2 bestimmt und ist hier durch Verbindung nach GND auf zwei gesetzt, wodurch eine Full-Scale-Spannung von 4.095 V erreicht wird. Zusätzlich werden die Versorgungsspannung von 5 V sowie der digitale Ground angeschlossen. Zwischen $V_{CC}$ und GND ist gemäß Datenblatt ein 0,1 $\mu$F-Kondensator vorzusehen \cite[S. 1,7 u. 10]{LinearTechnology1450}. Mit diesen Festlegungen ließ sich die Referenzschaltung im Schaltplan umsetzen. Die Datenleitungen wurden über Bussymbole geführt, um sie im Schaltplan eindeutig und übersichtlich den nachfolgenden Verarbeitungsschritten zuzuordnen.\\

Der zugehörige Schaltplanteil findet sich auf Seite 3 des Schematics in \autoref{subsec:appendix_a_schematic}.

\subsubsection{Offset und Eingangsbeschaltung des ADCs}

Für das USB-Digitaloszilloskop wurde ein einstellbarer Gleichspannungs-Offset vorgesehen, damit der volle Spitze-Spitze-Eingangsbereich von 10 V nicht nur für Signale mit Mittelpunkt bei 0 V nutzbar ist. Rein positive oder rein negative Eingangssignale können damit ebenfalls in den Arbeitsbereich des ADCs verschoben werden.\\

Das Konzept folgt den Hinweisen des Datenblatts, nach denen der negative Analogeingang -AIN bei Gleichstromkopplung extern über einen Widerstandsteiler oder eine Spannungsreferenz auf ein Bezugspotenzial gelegt werden kann. Das Datenblatt zeigt hierfür sowohl ein festes Bezugspotenzial per Teiler als auch einen fein einstellbaren Offsetabgleich per Potentiometer (siehe \autoref{fig:adc_input_circuitry_ltc1420}). Beide Ansätze wurden zusammengeführt, um einen größeren und für unsere Anwendung erforderlichen Einstellbereich zu erhalten.

\begin{figure}[H]
	\centering
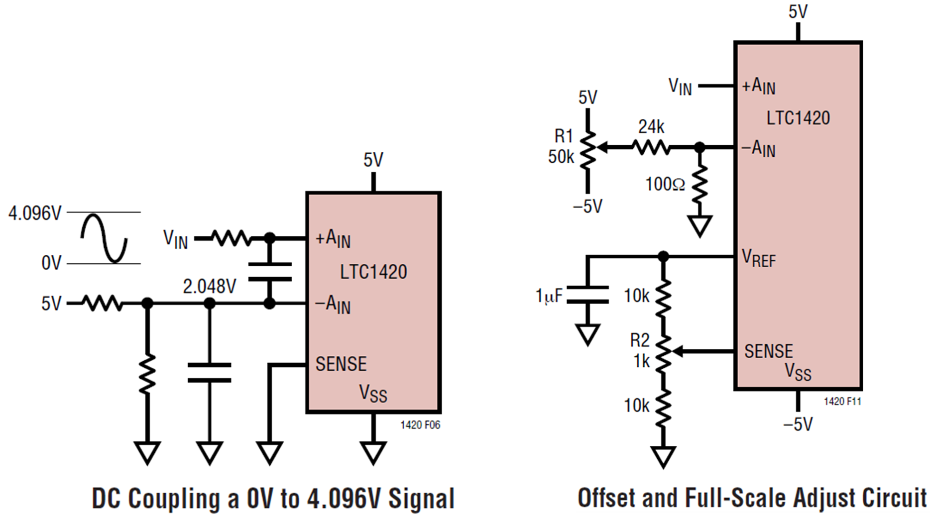
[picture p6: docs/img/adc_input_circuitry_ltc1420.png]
     
	\caption{Mögliche Eingangsbeschaltungen des ADCs (aus \cite[S. 10 u. 12]{LinearTechnology1420})}
	\label{fig:adc_input_circuitry_ltc1420}
\end{figure}

Das Datenblatt empfiehlt für bestmögliche dynamische Eigenschaften eine Zentrierung der Analogeingänge um 0 V im Dual-Supply-Betrieb sowie um 2.5 V im Single-Supply-Betrieb \cite[S. 9]{LinearTechnology1420}). Die tatsächliche Dynamikverschlechterung bei Abweichungen wird dort jedoch nicht quantifiziert. Das Design sieht daher eine Offseteinstellung über einen Spannungsteiler vor und bewertet die Performance experimentell im Aufbau.\\

Der am Eingang des AD-Umsetzers nutzbare Bereich liegt differenziell bei $\pm$ 2.048 V. Daraus folgt als Zielgröße ein einstellbarer Offset von ebenfalls $\pm$ 2,048 V, weil sich damit rein positive oder rein negative Signale, deren Spitze-Spitze-Spannung $\pm$ 2.048V beträgt, in die Mitte des nutzbaren Fensters verschieben lassen. Diese Realisierung ist im Dual-Supply-Betrieb möglich, da die Aussteuerungsgrenzen entsprechend $\pm$ 5 V Versorgungsspannung ausreichende Reserven bieten.\\

Die Offsetschaltung besteht aus einem Potentiometer $R_{Voff1}$ = 5 k$\Omega$, das zwischen +5 V und -5 V liegt. An den Enden des Potentiometers befinden sich symmetrische Vorwiderstände $R_{off1}$ = $R_{off2}$ = 2.7 k$\Omega$. Der Schleifer stellt den Offset bereit und speist über einen Jumper den Knoten -AIN. Nachgeschaltet sind zwei Glättungskondensatoren mit 1 $\mu$F und 100 nF gegen analoge Masse, die Versorgungsschwankungen und Spannungsspitzen dämpfen. Der Jumper ermöglicht bei Bedarf die Trennung des Offsets vom Eingangspfad, durch Überbrücken eines der Kondensatoren ist eine Festlegung des Signals auf 0 V möglich. Ein zusätzlicher Spannungsfolger oder eine Referenzquelle wurde bewusst vermieden, da das Datenblatt für DC-Kopplung einen einfachen Widerstandsteiler zulässt und damit der Schaltungsaufwand reduziert wird.\\

Der zugehörige Schaltplanteil findet sich auf Seite 3 des Schematics in \autoref{subsec:appendix_a_schematic}.

Mit dieser Wahl der Bauelemente ergibt sich folgender Einstellbereich.

\[R_{Sigma} = R_{off1} + R_{Voff} + R_{off2} \]
\[V_{off}^{(+)} = -V_S + 2V_S\cdot \frac{R_{Voff} + R_{off2}}{R_{Sigma}} = +2.404 V \]
\[V_{off}^{(-)} = -V_S + 2V_S\frac{R_{off}\cdot 2}{R_{Sigma}} = -2.404 V\]

Der Bereich deckt den Zielwert von $\pm$ 2,048 V ab und eignet sich damit für den vorgesehenen Zweck.\\

\textbf{Weitere Beschaltung des ADCs}\\
Neben den Beschaltungen für Offset und Spannungsbereich waren weitere Maßnahmen am AD-Umsetzer erforderlich, die dem Datenblatt entnommen wurden.  
Da die 2.5-V-Spannung an $V_{CM}$ nicht genutzt wird, wurde sie mit einem 1-$\mu$F-Keramikkondensator gegen Masse verbunden.  
Zusätzlich wurden an $V_{REF}$, $V_{SS}$ und $V_{DD}$ jeweils 1-$\mu$F-Keramikkon-densatoren nach Masse vorgesehen. Die positive und die negative Versorgung $V_{SS}$ und $V_{DD}$ wurden ebenfalls angeschlossen.  
$V_{DD}$ und $OV_{DD}$ wurden gebrückt, um beide mit derselben 5-V-Versorgung zu speisen. Ursprünglich war vorgesehen, den digitalen Teil mit 3.3 V vom Mikrocontroller zu versorgen; dies wird jedoch nur im Single-Supply-Betrieb empfohlen, während im Dual-Supply-Betrieb 5 V empfohlen werden \cite[S. 12]{LinearTechnology1420}). Analoge und digitale Masse werden in unmittelbarer Nähe des AD-Umsetzers zusammengeführt, um die im Datenblatt geforderte Leitungsführung im Layout zu verdeutlichen. Weitere Informationen dazu folgen im Kapitel \textit{Layout} (siehe \autoref{subsec:hw_implementation}). Der Eingangsverstärkungsfaktor wurde auf eins gesetzt, da das Eingangssignal bereits durch einen Teiler herabgesetzt wird und eine zusätzliche Verstärkung eine stärkere Absenkung des Pegels durch den Spannungsteiler erfordern würde.  Der $GAIN$-Anschluss liegt dazu auf Versorgungspotenzial \cite[S. 6 u. 7]{LinearTechnology1420}).  Die Datenleitungen sind über Bussymbole geführt, um sie im Schaltplan eindeutig und übersichtlich den nachfolgenden Verarbeitungsschritten zuzuordnen.

\begin{figure}[H]
	\centering
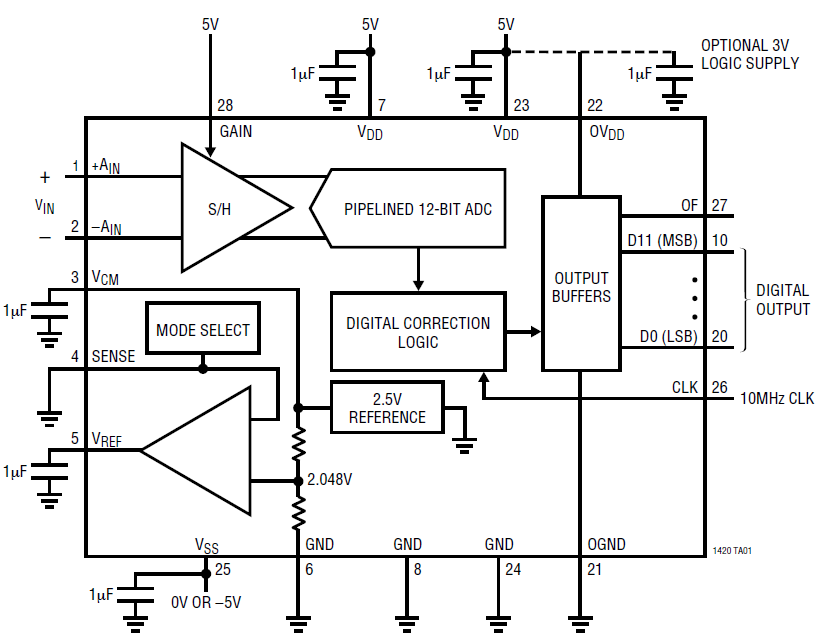
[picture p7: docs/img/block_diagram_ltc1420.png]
     
	\caption{Blockschaltbild des ADCs LTC1420 (aus \cite[S. 1]{LinearTechnology1420})}
	\label{fig:ltc1420_block_diagram}
\end{figure}

\subsubsection{Eingangsimpedanz und Kopplung}
\label{subsubsec:input_impedance_coupling}

Nachdem die Beschaltung des ADCs fertiggestellt war, konnte mit dem Design des analogen Frontends begonnen werden, angefangen mit Eingangsimpedanz und Kopplung.\\  
Nach der BNC-Buchse wurde zur Festlegung der Eingangsimpedanz von 1 M$\Omega$ und zur gleichzeitigen Pegelabsenkung ein Spannungsteiler realisiert.\\  
Ziel war, die Spannung auf die zulässigen Maximalwerte der Folgestufen zu begrenzen.  
Für den an den ADC-Bereich von $\pm$ 2.048 V angepassten Teiler wurde ein Teilfaktor von 0.4096 angesetzt ($R_2 \approx 0.4096$ M$\Omega$, $R_1 \approx 0.5904$ M$\Omega$).\\  
In der praktischen Umsetzung wurden die Widerstände als Serienkombinationen ausgeführt, um mit den vorhandenen E-Reihen möglichst nah an den errechneten Wert heranzukommen:\\  
$R_1$ durch 560 k$\Omega$ + 30 k$\Omega$ (590 k$\Omega$) und $R_2$ durch 390 k$\Omega$ + 20 k$\Omega$ (410 k$\Omega$).  
Damit wurde bewusst eine geringe Abweichung vom Soll in Kauf genommen, die später durch Softwarekalibrierung oder den Einsatz präziserer Widerstände korrigiert werden kann.\\  
Da der Ausgang des Teilers eine hohe Ausgangsimpedanz besitzt, wurde anschließend ein Spannungsfolger eingesetzt, um die Belastbarkeit zu erhöhen.\\  
Als Operationsverstärker wurde – in Anlehnung an ein Referenzprojekt\footnote{Siehe S.26 von \href{https://web.mit.edu/6.111/www/f2013/projects/kramnik_Project_Final_Report.pdf}{HDMI Digital Oscilloscope}} – der THS4631DGN gewählt. Im Projekt selbst wurde der OPA659 eingesetzt. Aufgrund des für unsere Anwendung zu geringem zulässigen Spannungsbereichs wurde jedoch auf eine im Datenblatt genannte Alternative mit höherem Versorgungsspannungsbereich bis zu $\pm$ 15V zurückgegriffen \cite[S. 3]{TexasInstruments659}. Der THS4631 überzeugte darüber hinaus durch einen sehr hohen Eingangswiderstand von 1 G$\Omega$ sowie eine Verstärkungsbandbreite von 210 MHz \cite[S. 1]{TexasInstruments4631}.\\  
Seine sehr hohe Eingangsimpedanz (G$\Omega$-Bereich) belastet den hochohmigen Teiler nur vernachlässigbar (1 G$\Omega \parallel$ 410 k$\Omega \approx$ 409.8 k$\Omega$) und die verfügbare Bandbreite ist für den Einsatzzweck geeignet.\\
Zur wahlweisen AC-Kopplung wurde zwischen Teilerknoten und OPV-Eingang ein Längskondensator vorgesehen.  
Aufgrund der hohen Eingangsimpedanz des OPV ergibt sich bereits mit kleinen Kapazitäten eine niedrige Hochpass-Grenzfrequenz, was die Bauteilauswahl vereinfacht.\\ 
Um zwischen AC- und DC-Betrieb ohne Entstehung offener Leiterstücke umschalten zu können, wurden zwei Jumper jeweils vor und hinter dem Koppelkondensator platziert, sodass der Kondensator bei Bedarf vollständig getrennt werden kann.\\
 
Da am OPV-Eingang und an den Zuleitungen unvermeidliche Kapazitäten anliegen, würde in Verbindung mit dem hochohmigen Teiler ein ausgeprägtes Tiefpassverhalten entstehen, dessen Grenzfrequenz deutlich unterhalb der angestrebten 1-MHz-Bandbreite läge.\\
Deshalb wurde – analog zum Prinzip des Oszilloskop-Tastkopfs (siehe \autoref{subsubsec:freq_comp_vdiv}) – ein kompensierter Spannungsteiler vorgesehen.\\
Ein einstellbarer Trimmkondensator parallel zu $R_1$ zur Feineinstellung, ergänzt um einen parallelen Festwertkondensator zur Grobeinstellung, erlaubt den Abgleich der Zeitkonstante und damit eine frequenzunabhängigere Abschwächung.\\  
Hierdurch werden die durch Eingangs- und Leitungskapazitäten verursachten Pegel- und Phasenfehler wirkungsvoll reduziert.\\

Der zugehörige Schaltplanteil findet sich auf Seite 2 des Schematics in \autoref{subsec:appendix_a_schematic}.\\

Für Messungen an 50-$\Omega$-Systemen ist optional ein Widerstand zur Eingangs-Anpassung vorgesehen. Damit kann der Eingang bei Bedarf auf 50 $\Omega$ umgeschaltet werden, ohne dass im Normalbetrieb die hohe 1-M$\Omega$-Eingangsimpedanz beeinträchtigt wird. Für den OPV wurden entsprechend des Datenblatts je Versorgungspannung zwei Bypass Kondensatoren mit 0.1$\mu$F und 100pF eingeplant. Ein weiterer größerer Kondensator im uF-Bereich, war ebenfalls gefordert. Da dieser laut Datenblatt allerdings nicht direkt am Device gefordert ist und mit anderen Bausteinen geteilt werden kann, wurde auf Grund der weiteren OPVs in der Nähe des Spannungsfolgers auf diesen verzichtet \cite[S. 20]{TexasInstruments4631}.

\subsubsection{Anti-Aliasing-Filter}
\label{subsubsec:aaf_concept}

Der zugehörige Schaltplanteil findet sich auf Seite 2 des Schematics in \autoref{subsec:appendix_a_schematic}.\\

Der Entwurf des Anti-Aliasing-Filters erfolgte mit dem Analog Filter Wizard\footnote{\url{https://tools.analog.com/en/filterwizard/}} von Analog Devices und orientierte sich an den im Kapitel zum Filterentwurf festgelegten Kriterien (\autoref{subsec:aaf_nyquist}). Für die Synthese wurden die 3-dB-Grenzfrequenz, die geforderte Sperrbanddämpfung und der Beginn des Sperrbands vorgegeben. Außerdem wurde ein Spannungsbereich von $\pm$5 V festgelegt. Die 3-dB-Grenzfrequenz wurde auf 1,5 MHz festgelegt, um die Zielbandbreite von 1 MHz sicher zu erreichen. Der Beginn des Sperrbands wurde mit der Nyquist-Frequenz gleichgesetzt, die bei der halben Abtastrate liegt und hier 5 MHz beträgt. Die notwendige Sperrbanddämpfung wurde aus der Auflösung des AD-Umsetzers hergeleitet, da das SINAD ebenfalls bei rund 72 dB liegt.

\begin{equation}
	A_{stop} \approx 6.02 \cdot N dB \approx 72 dB
\end{equation}

Es wurde ein Tiefpass neunter Ordnung gewählt. Zur Begrenzung der Komplexität und zur Reduktion von Instabilitätsrisiken sollte die Realisierung höchstens vier Operationsverstärker umfassen. Das Filter wurde daher als Kaskade aus vier aktiven Stufen ausgelegt und am Ausgang um ein zusätzliches RC-Glied ergänzt. Die Auslegung basiert auf der Annahme eines hohen Eingangswiderstands des AD-Umsetzers während der Wandlung, weshalb hinter dem RC-Glied kein weiterer Puffer erforderlich ist.
Im Designwerkzeug wurden die Parameter auf das schnellstmögliche Einschwingverhalten unter den gegebenen Randbedingungen eingestellt. Zusätzlich erfolgte eine Optimierung auf niedriges Rauschen. Für die endliche Verstärkungsbandbreite der eingesetzten Operationsverstärker wurde eine Kompensation in der Beschaltung berücksichtigt. Die Bauteilauswahl folgt praxisnahen Reihen mit Kondensatoren aus der E12-Reihe und Widerständen aus der E24-Reihe.

Die Bewertung des Filters erfolgte anhand der zuvor definierten Kriterien im \autoref{subsec:aaf_nyquist}, insbesondere anhand der Diagramme zur Gruppenlaufzeit (\autoref{fig:afw_group_delay_aaf}), Sprungantwort (\autoref{fig:afw_step_response_aaf}) und Betrags-Frequenzgang (\autoref{fig:afw_magnitude_dB_aaf}). Das Design-Tool schlug als OPV den AD8022 von Analog Devieces vor, welchen wir nach einer Sichtung des Datenblatts übernommen. Das Ergebnis wurde in den Schaltplan übernommen, dabei wurden die im Datenblatt der OPVs beschriebenen Entkopplungskondensatoren berücksichtigt.

\begin{figure}[H]
	\centering
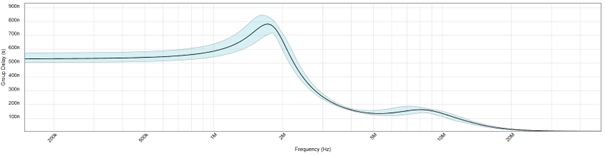
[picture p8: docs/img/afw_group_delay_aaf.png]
     
	\caption{Gruppenlaufzeit des AAF (Analog Filter Wizard)}
	\label{fig:afw_group_delay_aaf}
\end{figure}

\begin{figure}[H]
	\centering
     
	\caption{Sprungantwort des AAF (Analog Filter Wizard)}
	\label{fig:afw_step_response_aaf}
\end{figure}

\begin{figure}[H]
	\centering
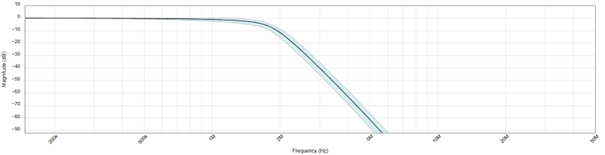
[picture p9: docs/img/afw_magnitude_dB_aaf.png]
     
	\caption{Betrags-Frequenzgang des AAF (Analog Filter Wizard)}
	\label{fig:afw_magnitude_dB_aaf}
\end{figure}

\subsubsection{Trigger- und Clock-Schaltung}

Entsprechend der im Kapitel zur Schnittstelle beschriebenen Anforderungen (\autoref{subsec:requirements_hw_fw_interface}) war eine Pegelwandlung des Taktsignals erforderlich. Parallel dazu war eine analoge Triggereinrichtung vorgesehen. Beide Funktionen wurden über einen Komparator realisiert. Für die Umsetzung der beiden Komparatorfunktionen Pegelwandlung des Taktsignals sowie Trigger-Erfassung wurde der LT1714 gewählt. Es handelt sich um einen Dual-Komparator, der zwei identische Komparatorstufen in einem Gehäuse bereitstellt \cite[S. 1]{LinearTechnology1714}.\\

\textbf{Anforderungen}

\begin{enumerate}
    \item Pegelwandlung Takt 3.3 V $\rightarrow$ 5 V
    \begin{itemize}
        \item Taktfrequenz 10 MHz
        \item Sehr kurze Verzögerungszeiten und CMOS-kompatibler Ausgang erforderlich
        \item Versorgung 5 V Single Supply ausreichend
    \end{itemize}
    \item Trigger-Erfassung
    \begin{itemize}
        \item Konfiguration mit einstellbarer Referenzspannung über Trimm-Potentiometer
        \item Betrieb mit Dual Supply ±5 V, um positive und negative Eingangssignale zu erfassen
        \item Niedriges Propagation Delay für präzise Flankenerkennung
        \item CMOS-kompatibler Ausgang für die digitale Weiterverarbeitung
    \end{itemize}
\end{enumerate}

\textbf{Begründung der Auswahl}\\
Der LT1714 besitzt ein Propagation Delay von 7 ns bei 20 mV Übersteuerung und maximal 12 ns sowie eine maximale Schaltfrequenz von 65 MHz, womit die geforderten 10 MHz für die Takt-Pegelumsetzung problemlos realisierbar sind (\cite[S. 1, 3-4]{LinearTechnology1714}). Das IC unterstützt sowohl Single-Supply-Betrieb von 2.4 V bis 12 V als auch Dual-Supply von $\pm$ 2.4 V bis $\pm$ 6 V, womit die Versorgung mit $\pm$ 5 V für die Trigger-Anwendung möglich ist (\cite[S. 1-2]{LinearTechnology1714}). Die Eingänge sind rail-to-rail und können 100 mV über die Versorgungsspannungen hinaus betrieben werden, sodass sich bei $\pm$ 5 V ein nutzbarer Bereich von etwa -5.1 V bis +5.1 V ergibt. Eine Hysteresebeschaltung ist vorgesehen und unterstützt eine stabile Triggerung (\cite[S. 1, 8, 10]{LinearTechnology1714}). Die Ausgänge sind rail-to-rail, komplementär und TTL/CMOS-kompatibel; bei 5 V Versorgung werden typischerweise $V_{OH} = 4.8\,\text{V}$ bei 1 mA Last und $V_{OL} = 0.2\,\text{V}$ erreicht, was eine direkte digitale Weiterverarbeitung ermöglicht (\cite[S. 3-4]{LinearTechnology1714}).\\

Für die Trigger-Einrichtung wurde zur Einstellung des Triggerpegels ein Potentiometer verwendet, das über zwei symmetrische Widerstände zwischen die positiven und negativen 5-V-Versorgungsschienen gelegt ist. Der Schleifer führt zum negativen Komparatoreingang. Die Widerstände besitzen 820 $\Omega$, das Potentiometer 10 k$\Omega$. Damit ist eine Spannung von etwa $\pm$ 4.096 V geplant. Die tatsächlich erreichbaren Endwerte ergeben sich aus der Spannungsteilung und lauten wie folgt:

\[
R_{\Sigma} = R_{\text{trig1}} + R_{V_{\text{trig}}} + R_{\text{trig2}}
\]

\[
V_{\text{trig}}^{(+)} = -V_S + 2V_S\frac{R_{V_{\text{trig}}} + R_{\text{trig2}}}{R_{\Sigma}} = +4.296\,\text{V}
\]

\[
V_{\text{trig}}^{(-)} = -V_S + 2V_S\frac{R_{\text{trig2}}}{R_{\Sigma}} = -4.296\,\text{V}
\]

Zur Glättung gegen Versorgungsschwankungen und Spannungsspitzen wurden zwei Bypass-Kondensatoren mit 0.1 $\mu$F und 4.7 $\mu$F eingesetzt. Über zwei Widerstände wurde gemäß Datenblatt eine Hysterese von 10 mV eingestellt, um eine höhere Stabilität zu gewährleisten (siehe \autoref{fig:comparator_hysteresis_circuit}).

\begin{figure}[H]
	\centering
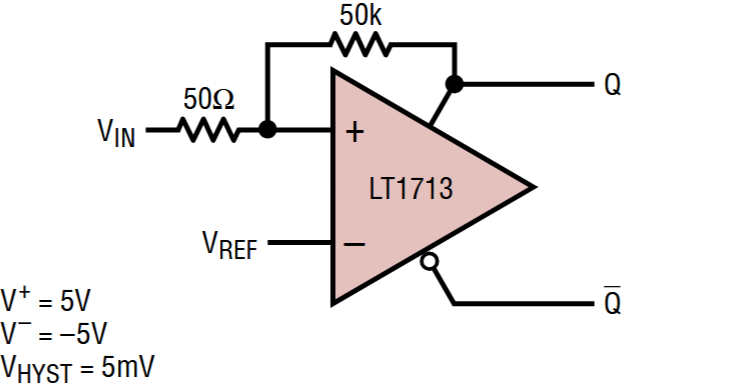
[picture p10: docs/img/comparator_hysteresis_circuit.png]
     
	\caption{Hysterese Beschaltung aus \cite[S. 10]{LinearTechnology1714}}
	\label{fig:comparator_hysteresis_circuit}
\end{figure}

Für die Pegelwandlung des Clock-Signals wurde die Schaltschwelle über einen Widerstandsteiler definiert. Der obere Widerstand besitzt 68 k$\Omega$ und der untere 33 k$\Omega$. Die resultierende Schwelle beträgt näherungsweise 1.63 V und ergibt sich aus:

\[
V_{\text{th,clk}} = V_S \cdot \frac{R_{\text{clk2}}}{R_{\text{clk1}} + R_{\text{clk2}}} = 5\,\text{V} \cdot \frac{33k}{68k + 33k} = 1.634\,\text{V}
\]

Auch diese Stufe wurde zur Stabilisierung mit 0.1 $\mu$F und 4.7 $\mu$F beschaltet. Zusätzlich wurde ebenfalls eine Hysterese von 10 mV realisiert. Entkopplungskondensatoren mit 0.1 $\mu$F und 4.7 $\mu$F wurden entsprechend dem Datenblatt vorgesehen (\cite[S. 9]{LinearTechnology1714}).\\

Als Abgriff für das Triggersignal wurden ein Jumper direkt am Eingang des AD-Umsetzers und ein weiterer Jumper unmittelbar hinter dem Spannungsfolger vorgesehen. Über einen zusätzlichen Jumper wird die gewünschte Triggerquelle ausgewählt. Der Abgriff hinter dem Spannungsfolger ist aufgrund der niedrigen Ausgangsimpedanz grundsätzlich vorteilhaft. Bei höheren Frequenzen kann er jedoch durch die Lage vor dem Anti-Aliasing-Filter dazu führen, dass der Trigger nicht exakt dem im Oszilloskop dargestellten Signal entspricht.\\

Der zugehörige Schaltplanteil findet sich auf Seite 6 des Schematics in \autoref{subsec:appendix_a_schematic}.

\subsubsection{Simulation des AFEs}

Zur Verifikation des gesamten analogen Frontends und zur frühzeitigen Erkennung möglicher Probleme vor dem Layout wurde das geplante Design in PSPICE übertragen (siehe Simulationen im \autoref{sec:appendix_a}). Die Simulation diente außerdem dazu, Richtwerte für Kompensationskondensator und Koppelkondensator zu bestimmen. Da im Analog Filter Wizard bereits eine Filtersimulation vorlag, lag der Schwerpunkt auf dem Gesamtsystem. Einzelne Stufen wurden zur Absicherung ebenfalls simuliert. Eine vollständige Darstellung aller Einzelergebnisse würde jedoch den Rahmen dieser Dokumentation sprengen.\\

Die verwendeten Simulationsmodelle stammten überwiegend aus den integrierten Bibliotheken des Programms. Das Modell des Spannungsfolgers wurde aus einer Internetbibliothek des Herstellers \footnote{\url{https://www.ti.com/product/de-de/THS4631\#design-tools-simulation}} eingebunden. Nach Abschluss des Schaltplans wurden verschiedene Simulationen ohne aktivierte Kopplung durchgeführt. Zunächst wurde der geeignete Wert beziehungsweise der geeignete Wertebereich für den Kompensationskondensator ermittelt. In der AC-Analyse ergab die parametrische Darstellung des Frequenzgangs einen idealen Wert von rund 5.6 pF. Daraus wurde ein Trimmkondensator mit einem Einstellbereich von 2 bis 10 pF abgeleitet. Anschließend folgten Transientenanalysen mit repräsentativen Eingangssignalen. Exemplarisch sind im Anhang Rechtecksignale mit 100 kHz und 1 MHz sowie Sinussignale mit 100 kHz und 1 MHz dargestellt. Zusätzlich wurden Frequenzgang und Gruppenlaufzeit über AC-Analysen bestimmt. An der Bandbreitengrenze von 1 MHz ergab sich simulatorisch eine Dämpfung von rund 1 dB. Die Ergebnisse stimmten gut mit den Resultaten des Filterdesign-Tools überein und stützen die gewählte Schaltungsauslegung.\\

Die Verifikation der Kopplung erwies sich als anspruchsvoller. Die Kopplung arbeitete nicht über den gesamten Frequenzbereich so trennscharf wie gewünscht. Je nach gewählter Kapazität wurde der Gleichanteil nicht ausreichend unterdrückt oder es trat bereits eine Dämpfung bei Signalen auf, die noch nicht gedämpft werden sollten. In der Simulation zeigte eine Kapazität von etwa 12 pF die besten Ergebnisse. Für eine optimierte Kopplung wäre vermutlich eine aufwendigere Schaltungstopologie erforderlich gewesen. Vor diesem Hintergrund wurde die Kopplung in der vorliegenden Form umgesetzt und im praktischen Aufbau evaluiert. Für die Grundfunktion des Oszilloskops ist sie nicht zwingend erforderlich, da sich eine Zentrierung des Wechselanteils um Masse und damit die Entfernung des Offsetanteils auch über die Offset-Funktion erreichen lässt.

\subsubsection{Interface und Connector zum $\mu$C}

Entsprechend der festgelegten Anforderungen an die Schnittstelle zwischen Firmware und Hardware (\autoref{subsec:requirements_hw_fw_interface}) wurde im Schaltplan ein Interface entworfen, das die definierten Pegel sicherstellt. Das Interface besteht primär aus Spannungsteilern für die Leitungen vom HW-Teil zum Mikrocontroller sowie aus Pull-up-Widerständen für Leitungen vom Mikrocontroller zum HW-Teil. Die Pegelwandlung war bereits konzeptionell festgelegt und wurde durch geeignete Widerstandswerte umgesetzt.

Für die Pull-up-Widerstände wurden 10 k$\Omega$ gewählt. Diese Dimensionierung begrenzt die statische Belastung der Versorgung und erlaubt zugleich eine ausreichend schnelle Flankenbildung für die vorgesehenen Steuerereignisse.

Für die Spannungsteiler wurde ein niedrigerer Gesamtwiderstand gewählt, da diese Pfade für die ADC-Kommunikation bestimmt sind und damit höhere Geschwindigkeiten erfordern. Gleichzeitig fließt hier nicht dauerhaft Strom wie bei den Pull-ups. Verwendet wurden 1.8 k$\Omega$ als oberer Widerstand zum 5-V-Pegel und 3.3 k$\Omega$ als unterer Widerstand nach Masse. Der resultierende Ausgangspegel bei einem 5-V-Eingang beträgt:

\[
V_{out} = V_{in} \cdot \frac{R_{unten}}{R_{oben} + R_{unten}} = 5 V \cdot \frac{3.3\,k\Omega}{1.8\,k\Omega + 3.3\,k\Omega} \approx 3.235 V
\]

Damit liegt der Logikpegel im zulässigen Bereich für die 3.3-V-Eingänge des Mikrocontrollers.

Die Daten- und Steuerleitungen des fertiggestellten Interfaceblocks (siehe Seite 4 des Schematics in \autoref{subsec:appendix_a_schematic}) wurden anschließend gemäß der zuvor vereinbarten Pinbelegung auf die Mikrocontroller-Konnektoren geführt. Die Spannungsversorgung und die Masse wurden an den Konnektoren ebenfalls angeschlossen (siehe Seite 8 des Schematics in \autoref{subsec:appendix_a_schematic}).

\subsubsection{Spannungsversorgung}

Die Spannungsversorgung wurde bewusst auf Labornetzteile ausgelagert, da der Entwicklungsfokus auf Signalverarbeitung, Erfassung und Konditionierung liegen sollte und dadurch eine freiere Bauteilwahl sowie Schaltungsentwicklung möglich war. Das analoge Frontend erhielt eine eigene Versorgung. ADC, DAC und sämtliche digitalen Schaltungsteile wurden über eine weitere Versorgung gespeist. \\

Für das analoge Frontend wurde eine Versorgungsspannung von $\pm$12 V gewählt. Die höhere Betriebsspannung schafft Reserven, da nach dem Eingangsteiler Signale bis zu 4.096 V am Frontend zulässig sind. Die eingesetzten Operationsverstärker arbeiten nicht rail-to-rail, daher erhöht die Wahl von $\pm$12 V die Aussteuerungsreserve und vermindert Klippgefahr. Außerdem liefern die OPVs bei dieser Versorgungsspannung die beste Gesamtperformance \cite[S. 1 u. 13]{AnalogDevices8022}. Der ADC und der Komparator erfordern eine Versorgung von $\pm$5 V. Für den Digitalteil einschließlich Mikrocontroller werden +5 V benötigt. Die +5-V-Schiene wurde gemeinsam mit den $\pm$5 V bereitgestellt, wodurch die Anzahl externer Netzteile reduziert wird und die Verteilung im Aufbau vereinfacht.\\
Zur Spannungsstabilisierung sind pro Schiene Elektrolytkondensatoren mit 100 $\mu$F vorgesehen. Als Verpolschutz werden Schottky-Dioden in die Zuleitungen eingesetzt. Die Versorgungseinspeisung erfolgt über Löt-Vias.\\
Der zugehörige Schaltplanteil findet sich auf Seite 5 des Schematics in \autoref{subsec:appendix_a_schematic}.

\subsubsection{Schaltplan / Zusammenführung}

Die einzelnen Funktionsteile wurden in KiCad zu einem mehrseitigen Schaltplan zusammengeführt. Der Entwurf ist hierarchisch aufgebaut und umfasst eine Root-Page, die eine Blockübersicht bereitstellt (siehe Seite 1 des Schemtaics in \autoref{sec:appendix_a}), sowie untergeordnete Seiten mit den jeweiligen Funktionsgruppen. Die Seiten gliedern sich in das analoge Frontend mit Eingangsimpedanz, Kopplung und Anti-Aliasing-Filter. Hinzu kommt die Beschaltung des ADCs mit dem DAC für die Referenz, der Offsetschaltung und den weiteren Beschaltungen des ADCs. Das Interface zum Mikrocontroller gewährleistet die notwendigen Pegel und Betriebsbedingungen für die Kommunikation. Der Trigger- und Clock-Block wandelt den Taktpegel und stellt die Triggersignale bereit. Ein weiterer Block bildet den Mikrocontroller-Connector ab. Die Verbindung zu den Konnektoren des Mikrocontrollers folgt der im Kapitel zur Schnittstelle zwischen Hardware und Firmware beschriebenen Zuordnung (\autoref{subsec:pin_mapping_levels}). Die Spannungsversorgung ist als eigener Abschnitt realisiert. Ein Block für einen Logic-Analyzer wurde vorbereitet, jedoch aus Zeitgründen nicht implementiert.\\
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

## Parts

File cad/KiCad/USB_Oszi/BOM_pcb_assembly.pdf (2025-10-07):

Referenz | Wert | Footprint | Anzahl
A1 | NUCLEO-F767ZI | NUCLEO-F767ZI:ST_NUCLEO-F767ZI | 1
ADC1 | LTC1420CGN-PBF ADC_USB_OSZI:FOOTPRINT_ADC_USB_OSZI | 1
Cbulk1,Cbulk2,Cbulk3,Cbulk4 | 100uF | Capacitor_SMD:CP_Elec_6.3x7.7 | 4
Cby1,Cby2,Cby3,Cby4,Cby5,Cby24 | 1u | Capacitor_SMD:C_0805_2012Metric | 6
Cby6,Cby8,Cby10,Cby12,Cby14,Cby16,Cby18,Cby20,Cby22,Cby26,Cby28 | 0.1u | Capacitor_SMD:C_0603_1608Metric | 11
Cby7,Cby21,Cby23,Cby27,Cby29 | 4.7u | Capacitor_SMD:C_0805_2012Metric | 5
Cby9,Cby11 | 100p | Capacitor_SMD:C_0603_1608Metric | 2
Cby13,Cby15,Cby17,Cby19 | 10u | Capacitor_SMD:C_0805_2012Metric | 4
Cby25 | 100n | Capacitor_SMD:C_0603_1608Metric | 1
Ccoup1 | ~12p | Capacitor_SMD:C_0603_1608Metric | 1
Cf1,Cf3,Cf5,Cf9 | 820p | Capacitor_SMD:C_0603_1608Metric | 4
Cf2 | 47p | Capacitor_SMD:C_0603_1608Metric | 1
Cf4 | 220p | Capacitor_SMD:C_0603_1608Metric | 1
Cf6 | 470p | Capacitor_SMD:C_0603_1608Metric | 1
Cf7,Cf8 | 680p | Capacitor_SMD:C_0603_1608Metric | 2
Cin1 | C | Capacitor_SMD:C_0603_1608Metric | 1
CTrim1 | 2-10p | Capacitor_SMD:C_Trimmer_Voltronics_JR | 1
D1,D2,D3,D4 | SS14 | Diode_SMD:D_SMA | 4
DAC1 | LTC1450CG-PBF | DAC_USB_OSZI:SSOP-24_G_LIT | 1
H1 | +5V | TestPoint:TestPoint_THTPad_D2.5mm_Drill1.2mm | 1
H2 | -5V | TestPoint:TestPoint_THTPad_D2.5mm_Drill1.2mm | 1
H3 | V+ | TestPoint:TestPoint_THTPad_D2.5mm_Drill1.2mm | 1
H4 | V- | TestPoint:TestPoint_THTPad_D2.5mm_Drill1.2mm | 1
H5,H6 | GND | TestPoint:TestPoint_THTPad_D2.5mm_Drill1.2mm | 2
J1 | BNC_CH1 | Connector_Coaxial:BNC_Amphenol_B6252HB-NPP3G-50_Horizontal | 1
JP1,JP2,JP7 | coupling | Jumper:SolderJumper-3_P1.3mm_Open_RoundedPad1.0x1.5mm | 3
JP3,JP4,JP5,JP6,JP8 | coupling | Jumper:SolderJumper-2_P1.3mm_Open_RoundedPad1.0x1.5mm | 5
Rclk1 | 68k | Resistor_SMD:R_0603_1608Metric | 1
Rclk2 | 33k | Resistor_SMD:R_0603_1608Metric | 1
Rf1,Rf4 | 270 | Resistor_SMD:R_0603_1608Metric | 2
Rf2 | 620 | Resistor_SMD:R_0603_1608Metric | 1
Rf3 | 130 | Resistor_SMD:R_0603_1608Metric | 1
Rf5 | 91 | Resistor_SMD:R_0603_1608Metric | 1
Rf6 | 200 | Resistor_SMD:R_0603_1608Metric | 1
Rf7 | 75 | Resistor_SMD:R_0603_1608Metric | 1
Rf8 | 180 | Resistor_SMD:R_0603_1608Metric | 1
Rf9,Rhys1,Rhys3 | 100 | Resistor_SMD:R_0603_1608Metric | 3
Rhys2,Rhys4 | 50k | Resistor_SMD:R_0603_1608Metric | 2
Rif1,Rif3,Rif5,Rif7,Rif9,Rif11,Rif13,Rif15,Rif17,Rif19,Rif21,Rif23,Rif25,Rif27 | 1.8k | Resistor_SMD:R_0603_1608Metric | 14
Rif2,Rif4,Rif6,Rif8,Rif10,Rif12,Rif14,Rif16,Rif18,Rif20,Rif22,Rif24,Rif26,Rif28 | 3.3k | Resistor_SMD:R_0603_1608Metric | 14
Rin1 | 30k | Resistor_SMD:R_0603_1608Metric | 1
Rin2 | 560k | Resistor_SMD:R_0603_1608Metric | 1
Rin3 | 20k | Resistor_SMD:R_0603_1608Metric | 1
Rin4 | 390k | Resistor_SMD:R_0603_1608Metric | 1
Rin5 | 50 | Resistor_SMD:R_0603_1608Metric | 1
Roff1,Roff2 | 2.7k | Resistor_SMD:R_0603_1608Metric | 2
Rpu1,Rpu2,Rpu3,Rpu4,Rpu5,Rpu6,Rpu7,Rpu8,Rpu9,Rpu10,Rpu11,Rpu12,Rpu13,Rpu14 10k | Resistor_SMD:R_0603_1608Metric | 14
Rref1,Rref2 | 5k | Resistor_SMD:R_0603_1608Metric | 2
Rref3 | 10 | Resistor_SMD:R_0603_1608Metric | 1
Rtrig1,Rtrig2 | 820 | Resistor_SMD:R_0603_1608Metric | 2
RVoff1 | 5k | Potentiometer_SMD:Potentiometer_Bourns_3314G_Vertical | 1
RVtrig1 | 10k | Potentiometer_SMD:Potentiometer_Bourns_3314G_Vertical | 1
TP1 | OPV4_OUT | TestPoint:TestPoint_Pad_D1.0mm | 1
TP2 | OPV3_OUT | TestPoint:TestPoint_Pad_D1.0mm | 1
TP3 | OPV1_OUT | TestPoint:TestPoint_Pad_D1.0mm | 1
TP4 | OPV2_OUT | TestPoint:TestPoint_Pad_D1.0mm | 1
TP7 | TRIGGER | TestPoint:TestPoint_Pad_D1.0mm | 1
TP8 | 5V_CLK | TestPoint:TestPoint_Pad_D1.0mm | 1
TP9 | TRIGGER_REF | TestPoint:TestPoint_Pad_D1.0mm | 1
TP10 | CLK_REF | TestPoint:TestPoint_Pad_D1.0mm | 1
U1 | THS4631DGN | Package_SO:MSOP-8-1EP_3x3mm_P0.65mm_EP1.68x1.88mm_ThermalVias | 1
U2,U3 | AD8022ARZ-REEL7 AD8022:R_8_ADI | 2
U4 | LT1714CGN-PBF | COMP_USB_OSZI:SSOP-16_GN_LIT | 1

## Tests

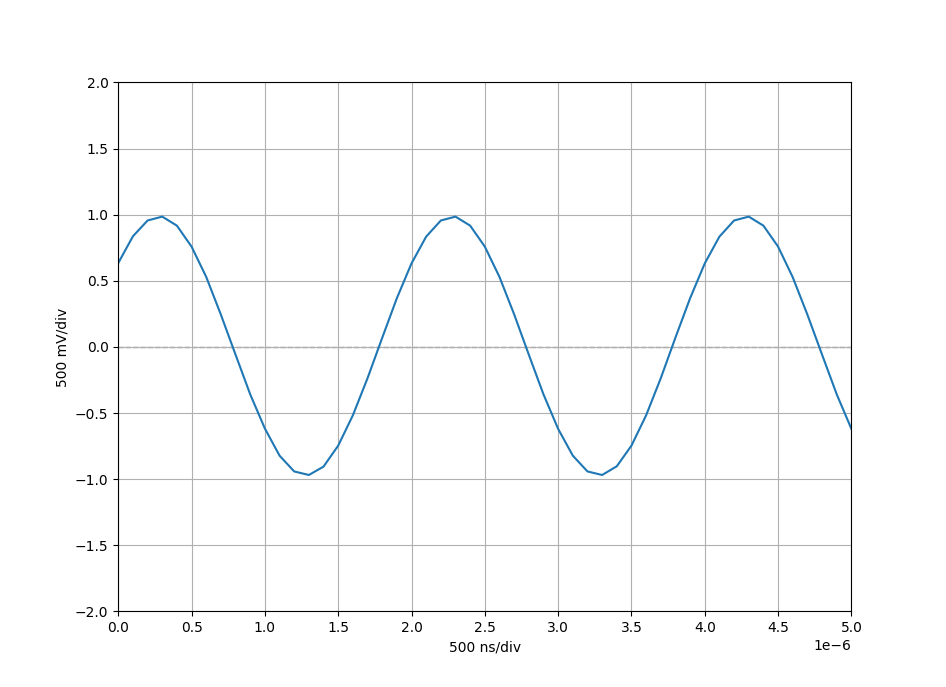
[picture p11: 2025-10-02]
docs/img/test_sine_500khz_2vpp.png

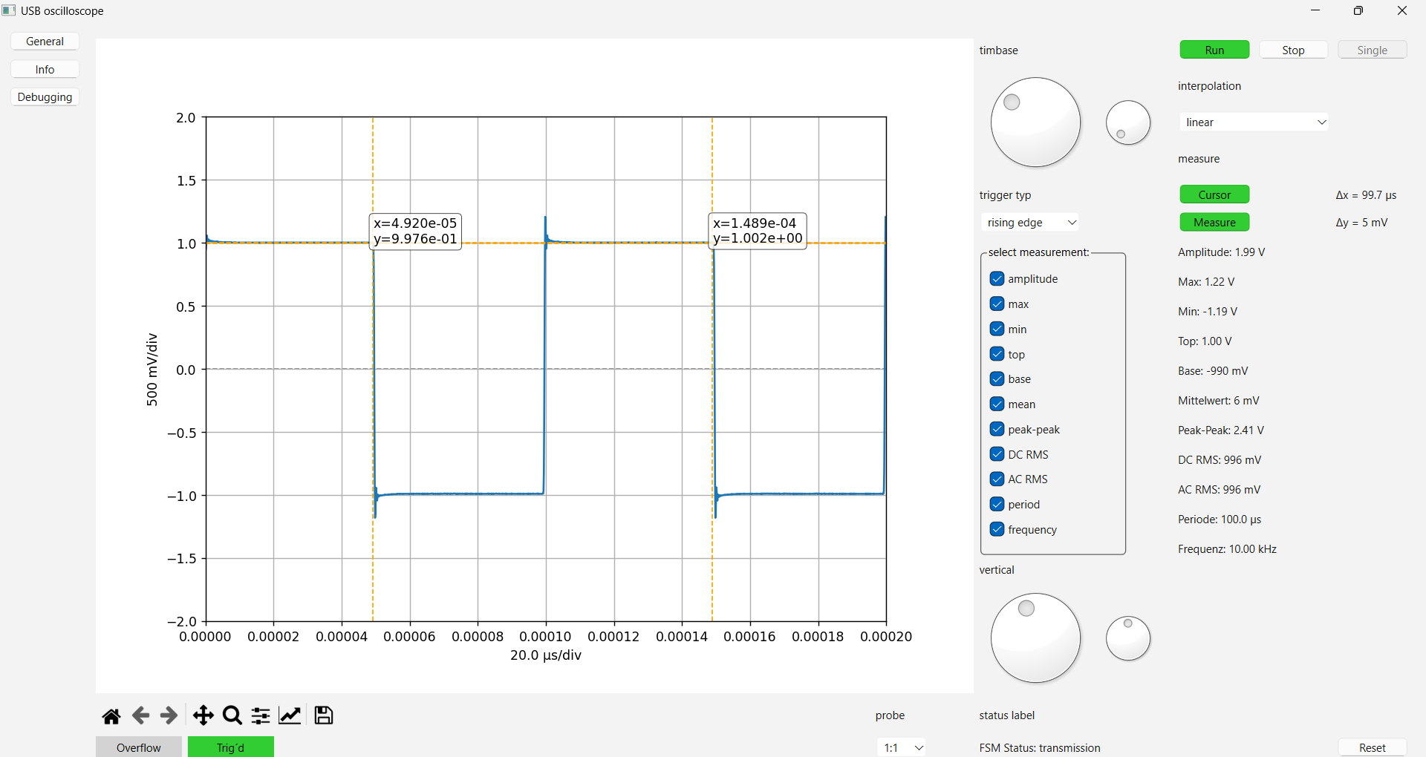
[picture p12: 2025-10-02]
docs/img/test_square_10khz_2vpp_gui_measurements_cursors.png

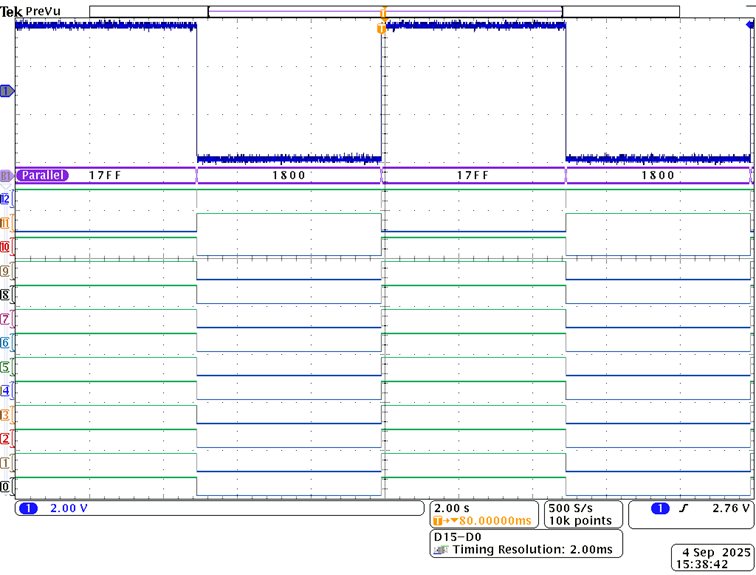
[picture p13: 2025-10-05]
docs/img/hw_test_adc_decode_Overflow_half_reference.png

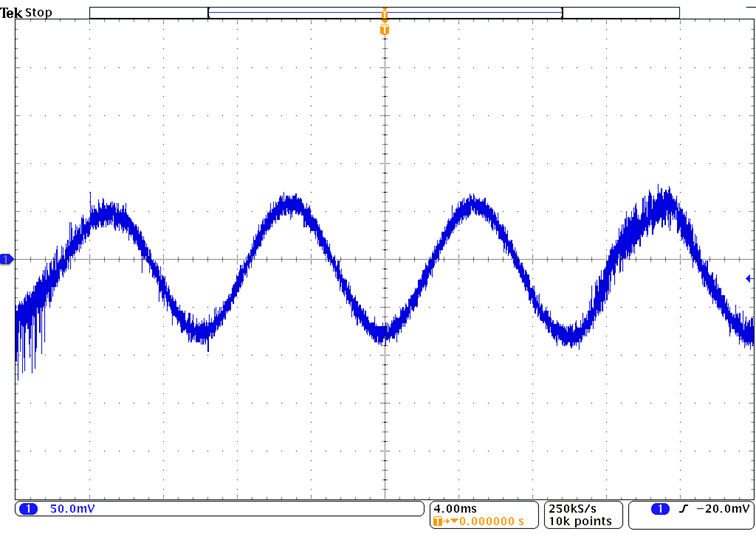
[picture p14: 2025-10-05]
docs/img/hw_test_neg_adc_input_sine_100hz_8vpp.png

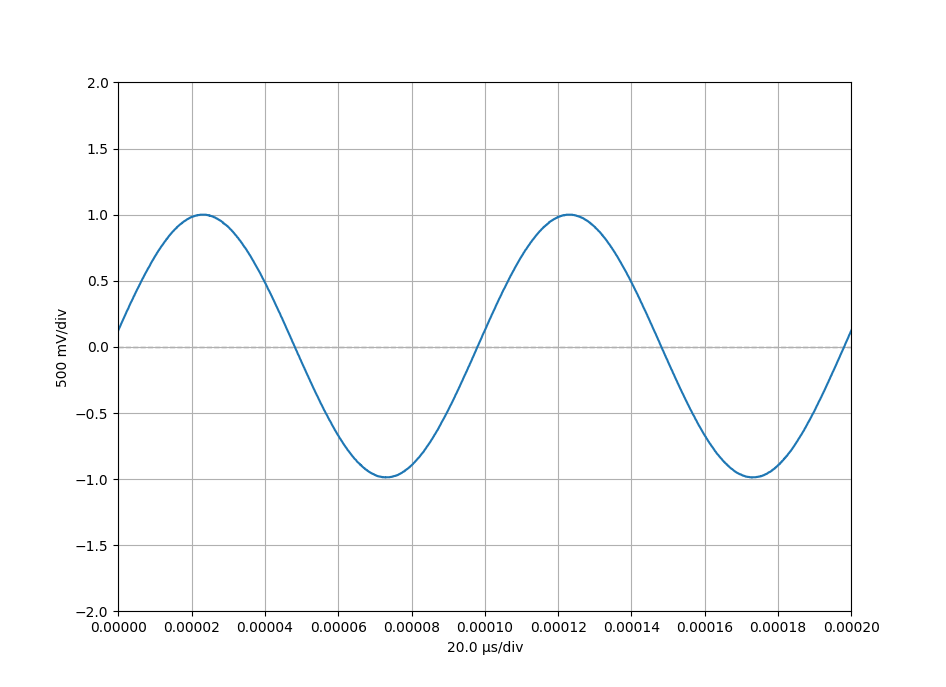
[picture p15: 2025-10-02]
docs/img/test_sine_10khz_2vpp.png

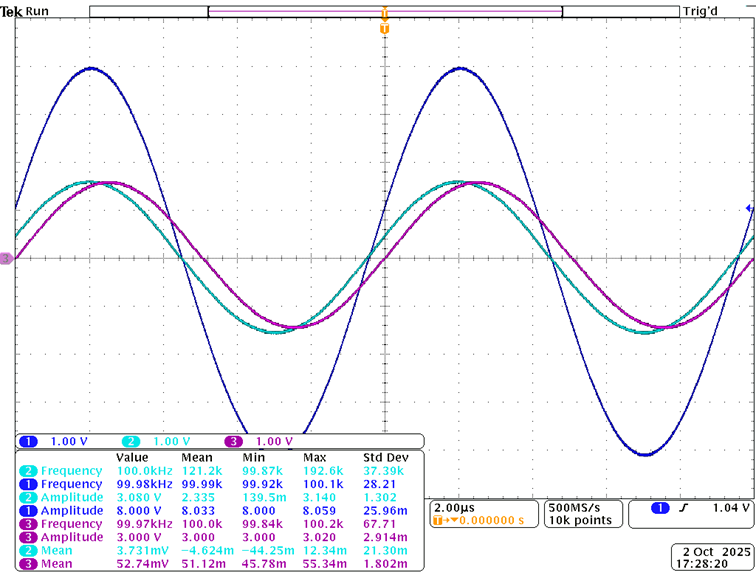
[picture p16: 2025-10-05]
docs/img/hw_test_sine_100khz_8vpp.png

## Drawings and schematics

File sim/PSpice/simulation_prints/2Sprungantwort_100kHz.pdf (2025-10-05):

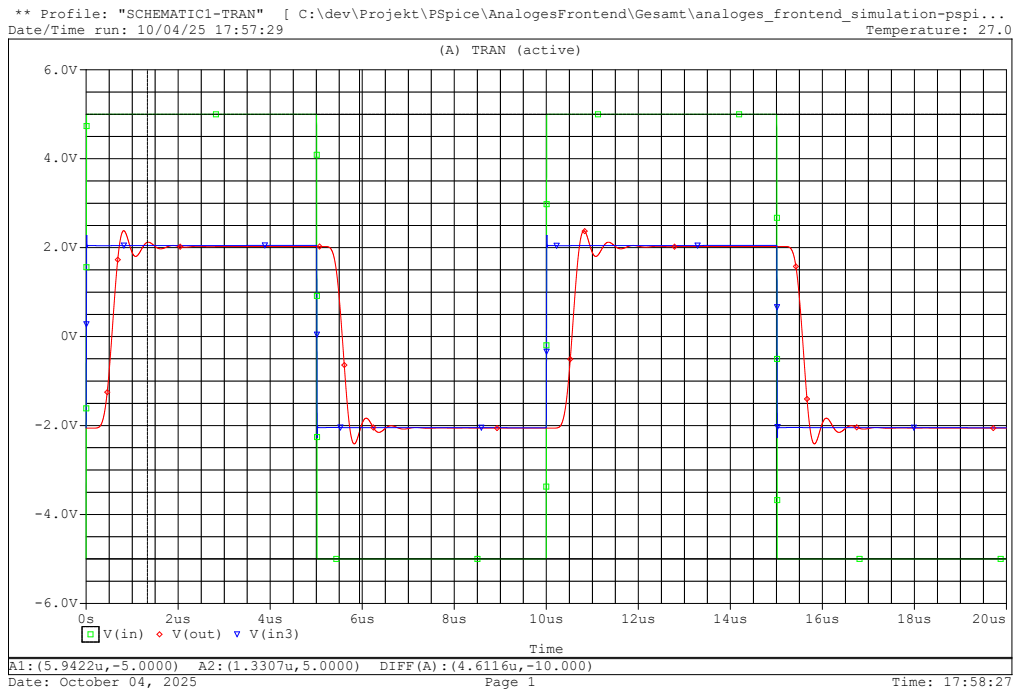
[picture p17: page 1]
A1:(5.9422u,-5.0000) A2:(1.3307u,5.0000) DIFF(A):(4.6116u,-10.000); Temperature: 27.0; Date: October 04, 2025; Page 1; Time: 17:58:27; (A) TRAN (active); Time; V(out)

** Profile: "SCHEMATIC1-TRAN" [ C:\dev\Projekt\PSpice\AnalogesFrontend\Gesamt\analoges_frontend_simulation-pspi...
Date/Time run: 10/04/25 17:57:29

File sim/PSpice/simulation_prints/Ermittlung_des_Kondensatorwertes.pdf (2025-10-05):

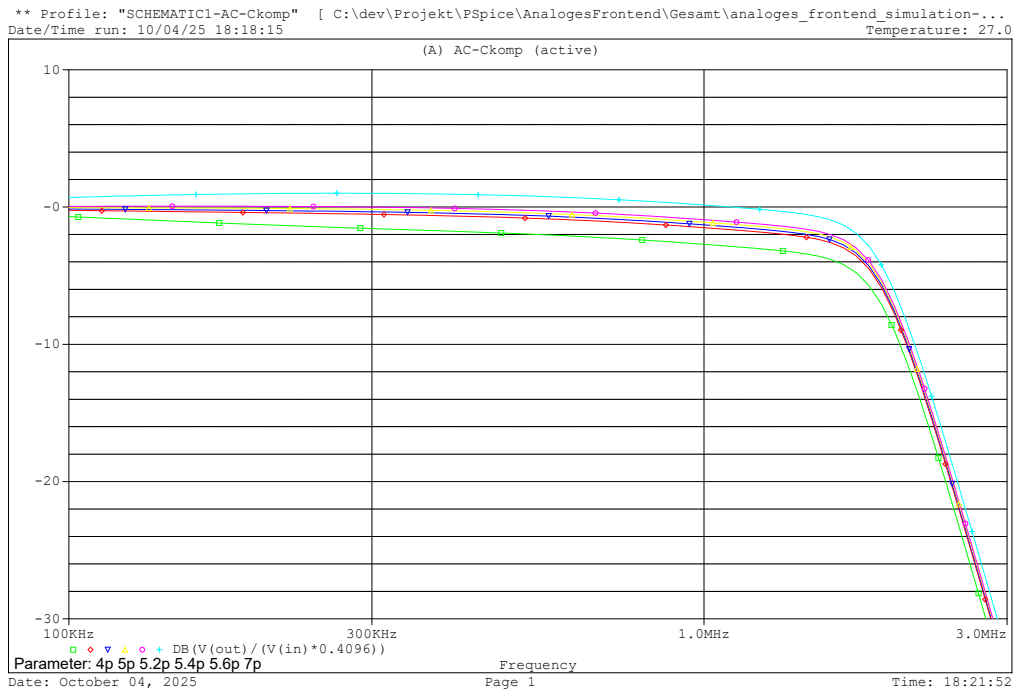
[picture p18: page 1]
Temperature: 27.0; Date: October 04, 2025; Page 1; Time: 18:21:52; Frequency; 100KHz; 300KHz; 1.0MHz; 3.0MHz; Parameter: 4p 5p 5.2p 5.4p 5.6p 7p

** Profile: "SCHEMATIC1-AC-Ckomp" [ C:\dev\Projekt\PSpice\AnalogesFrontend\Gesamt\analoges_frontend_simulation-...
Date/Time run: 10/04/25 18:18:15

(A) AC-Ckomp (active)

DB(V(out)/(V(in)*0.4096))

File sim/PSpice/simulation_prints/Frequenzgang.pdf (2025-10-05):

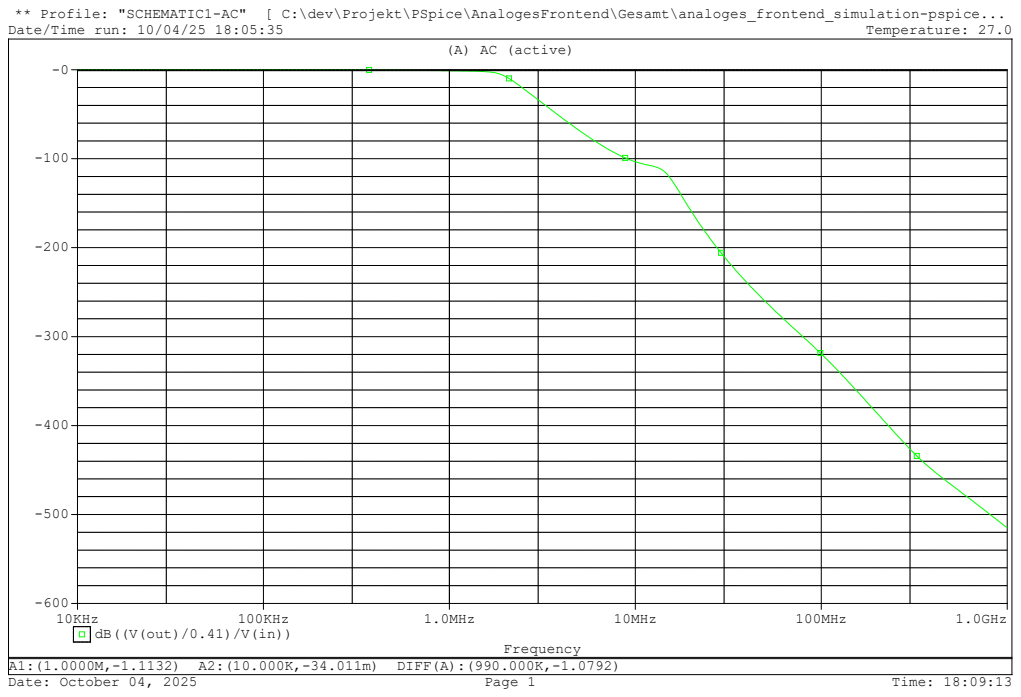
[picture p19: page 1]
A1:(1.0000M,-1.1132) A2:(10.000K,-34.011m) DIFF(A):(990.000K,-1.0792); Temperature: 27.0; Date: October 04, 2025; Page 1; Time: 18:09:13; (A) AC (active); Frequency; 10KHz; 100KHz; 1.0MHz; 10MHz; 100MHz; 1.0GHz

** Profile: "SCHEMATIC1-AC" [ C:\dev\Projekt\PSpice\AnalogesFrontend\Gesamt\analoges_frontend_simulation-pspice...
Date/Time run: 10/04/25 18:05:35

dB((V(out)/0.41)/V(in))

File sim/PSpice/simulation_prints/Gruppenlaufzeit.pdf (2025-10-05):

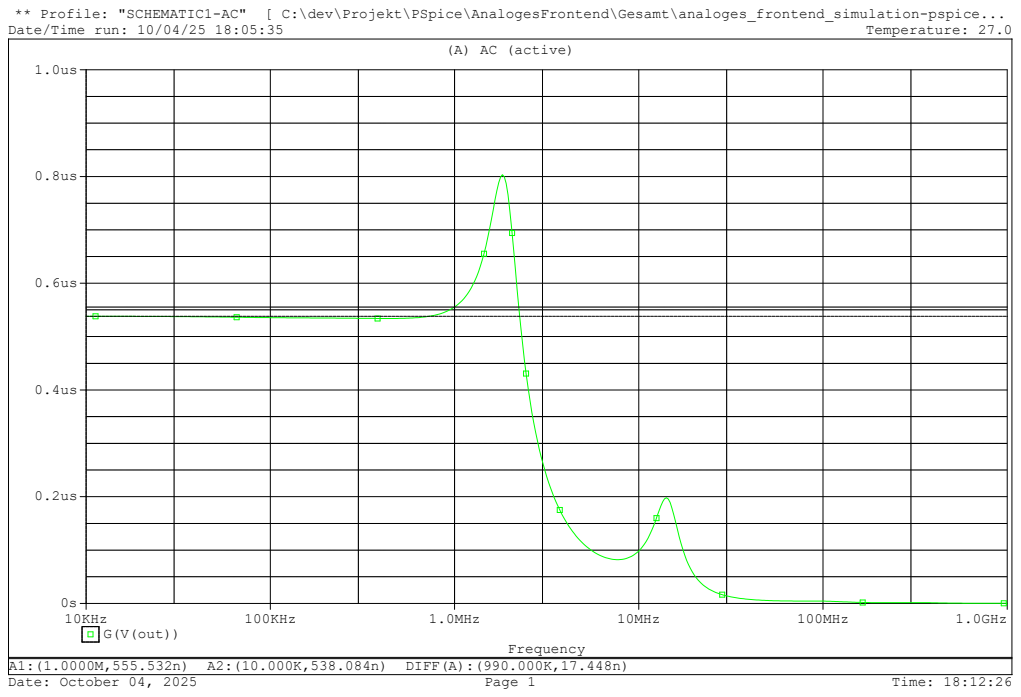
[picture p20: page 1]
A1:(1.0000M,555.532n) A2:(10.000K,538.084n) DIFF(A):(990.000K,17.448n); Temperature: 27.0; Date: October 04, 2025; Page 1; Time: 18:12:26; (A) AC (active); Frequency; 10KHz; 100KHz; 1.0MHz; 10MHz; 100MHz; 1.0GHz; G(V(out))

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

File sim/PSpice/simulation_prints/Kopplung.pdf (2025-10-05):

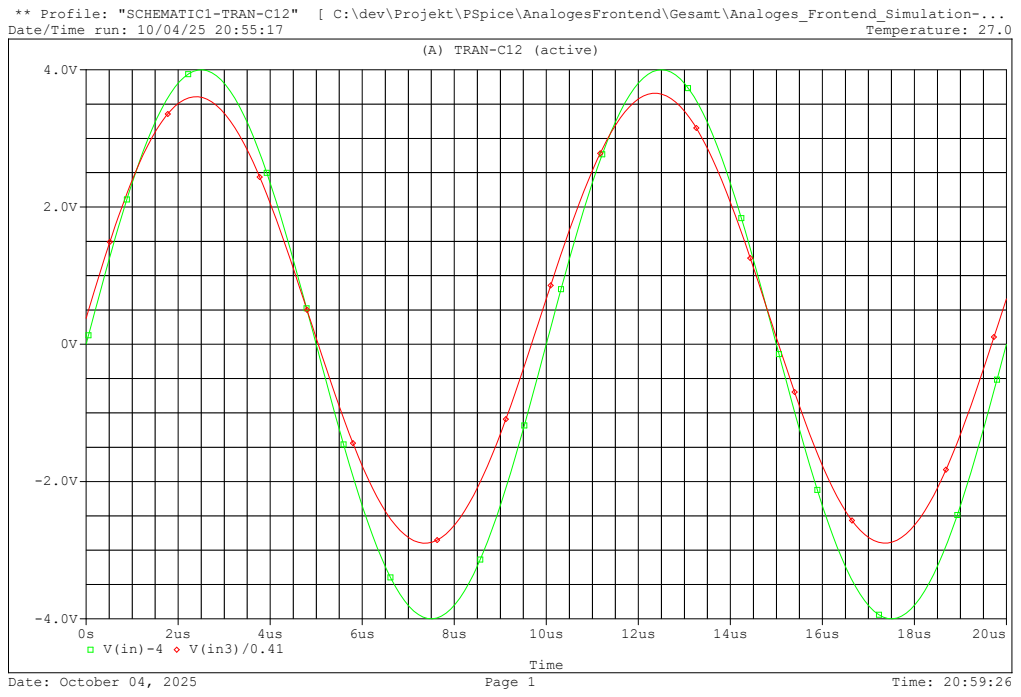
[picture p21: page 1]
Temperature: 27.0; Date: October 04, 2025; Page 1; Time: 20:59:26; (A) TRAN-C12 (active); Time

** Profile: "SCHEMATIC1-TRAN-C12" [ C:\dev\Projekt\PSpice\AnalogesFrontend\Gesamt\Analoges_Frontend_Simulation-...
Date/Time run: 10/04/25 20:55:17

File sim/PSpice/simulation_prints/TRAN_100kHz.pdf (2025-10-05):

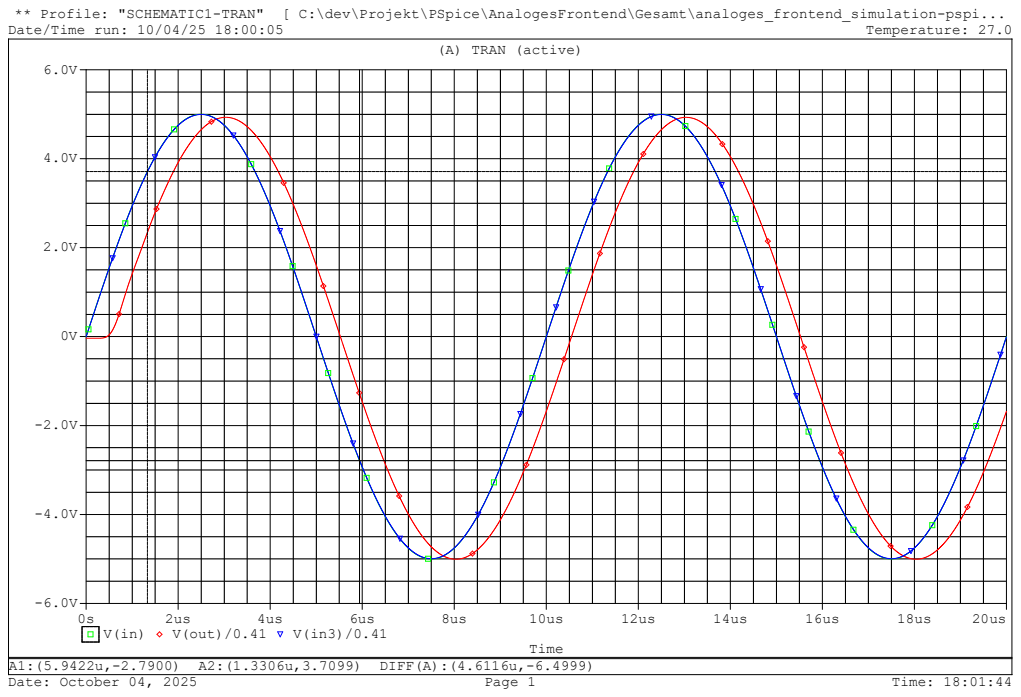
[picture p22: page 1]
A1:(5.9422u,-2.7900) A2:(1.3306u,3.7099) DIFF(A):(4.6116u,-6.4999); Temperature: 27.0; Date: October 04, 2025; Page 1; Time: 18:01:44; (A) TRAN (active); Time; V(out)/0.41

** Profile: "SCHEMATIC1-TRAN" [ C:\dev\Projekt\PSpice\AnalogesFrontend\Gesamt\analoges_frontend_simulation-pspi...
Date/Time run: 10/04/25 18:00:05

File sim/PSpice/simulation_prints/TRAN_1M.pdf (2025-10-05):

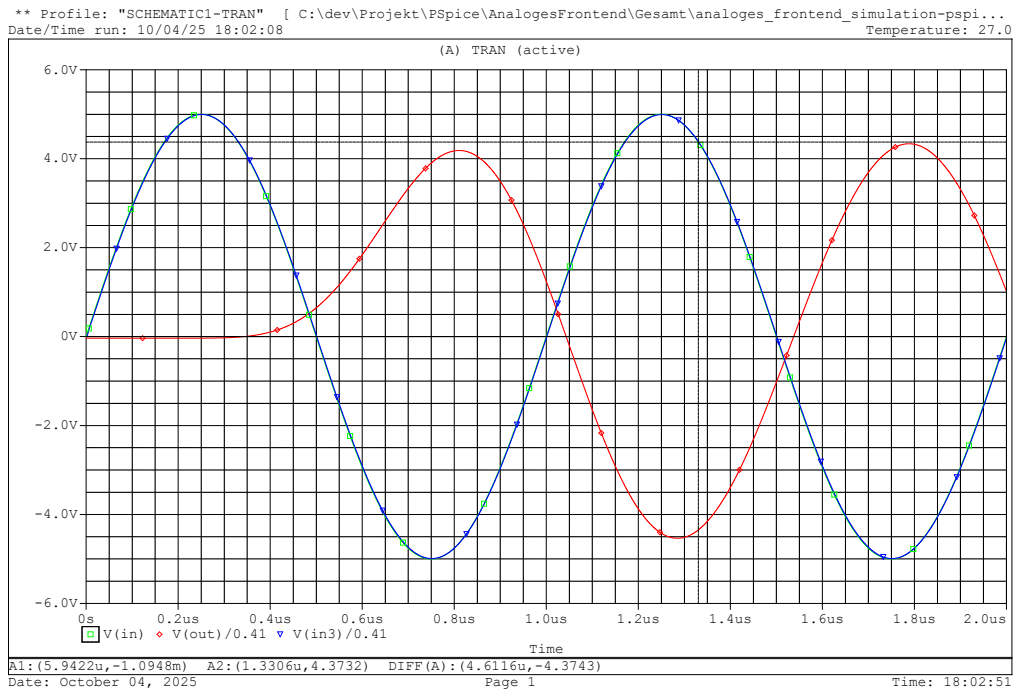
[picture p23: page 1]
A1:(5.9422u,-1.0948m) A2:(1.3306u,4.3732) DIFF(A):(4.6116u,-4.3743); Temperature: 27.0; Date: October 04, 2025; Page 1; Time: 18:02:51; (A) TRAN (active); Time; V(out)/0.41

** Profile: "SCHEMATIC1-TRAN" [ C:\dev\Projekt\PSpice\AnalogesFrontend\Gesamt\analoges_frontend_simulation-pspi...
Date/Time run: 10/04/25 18:02:08

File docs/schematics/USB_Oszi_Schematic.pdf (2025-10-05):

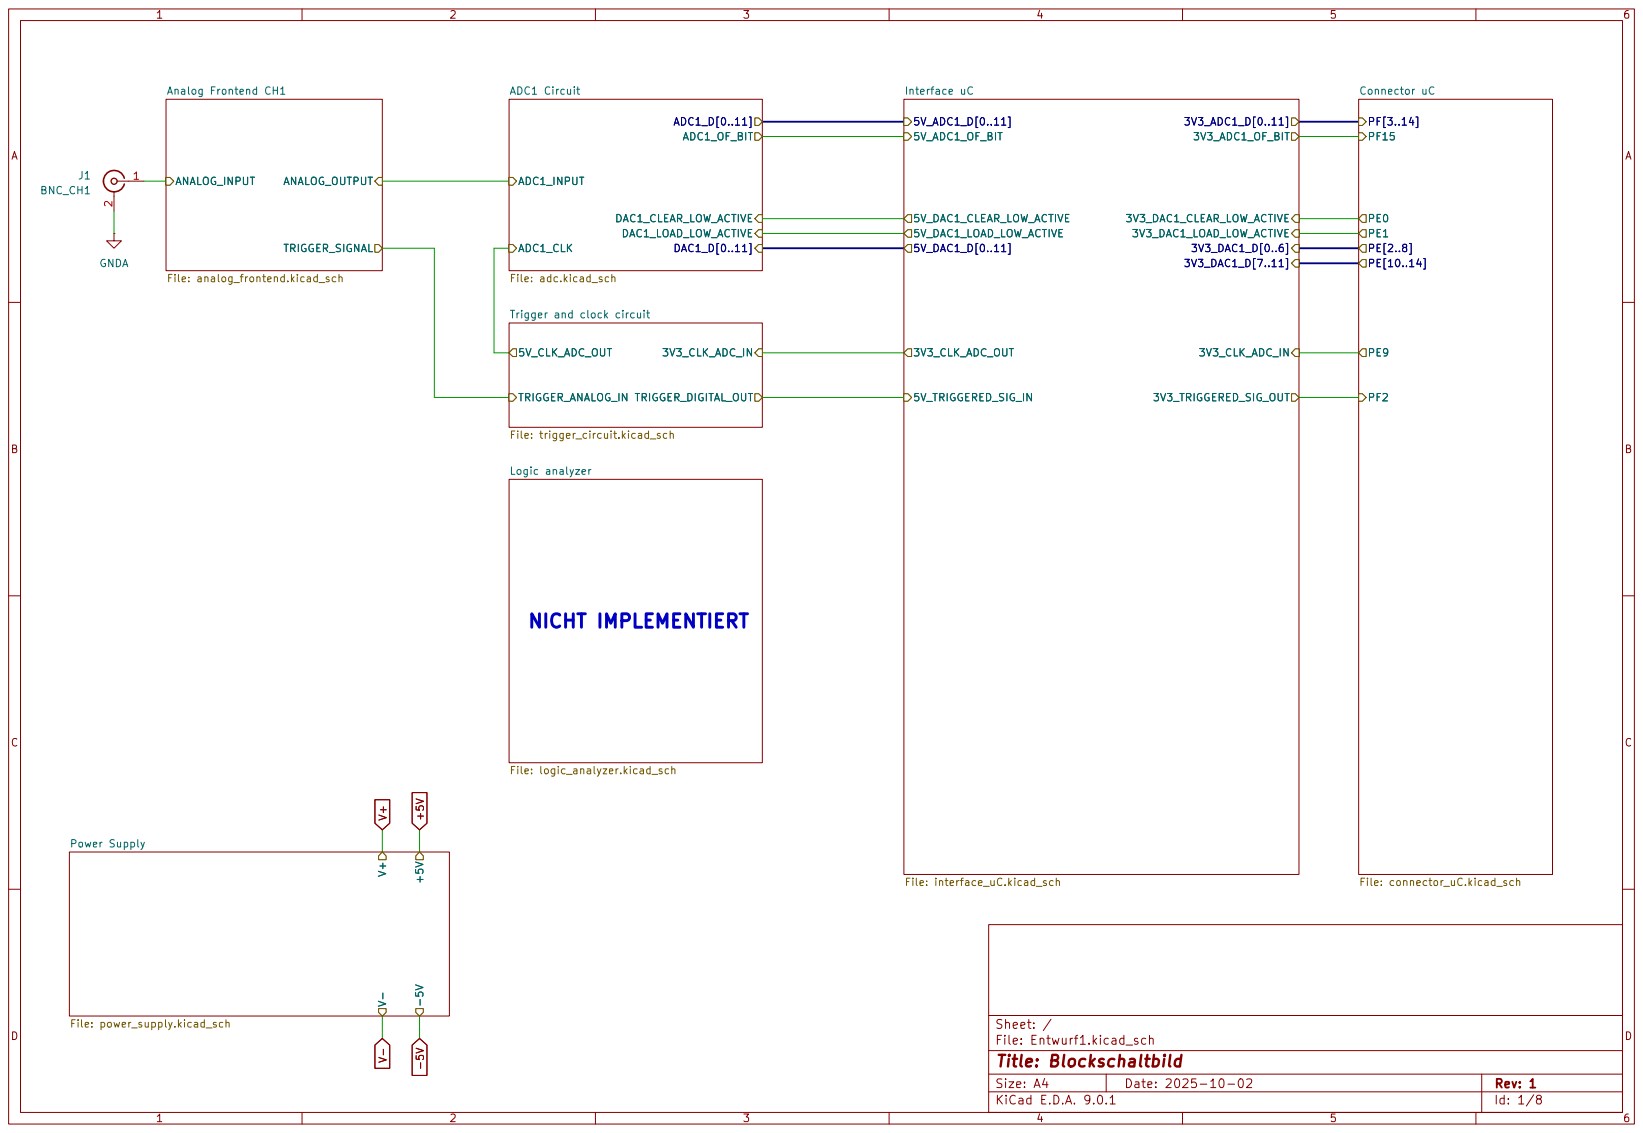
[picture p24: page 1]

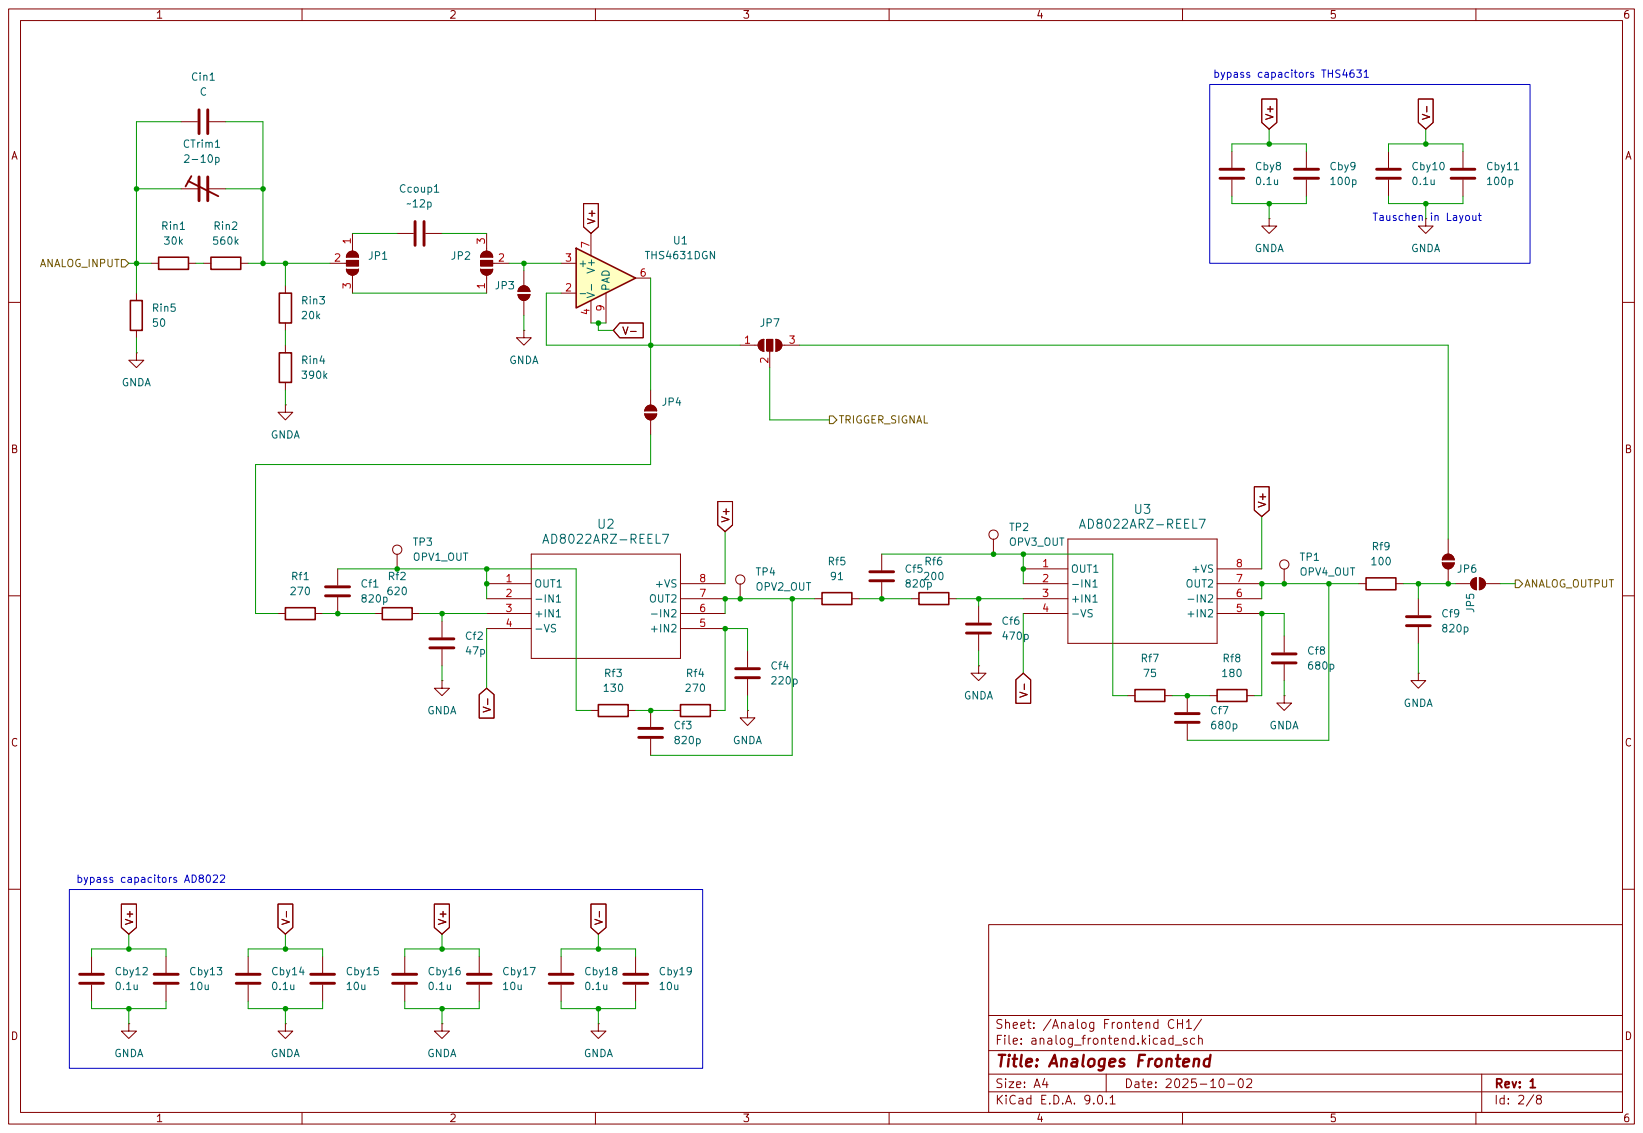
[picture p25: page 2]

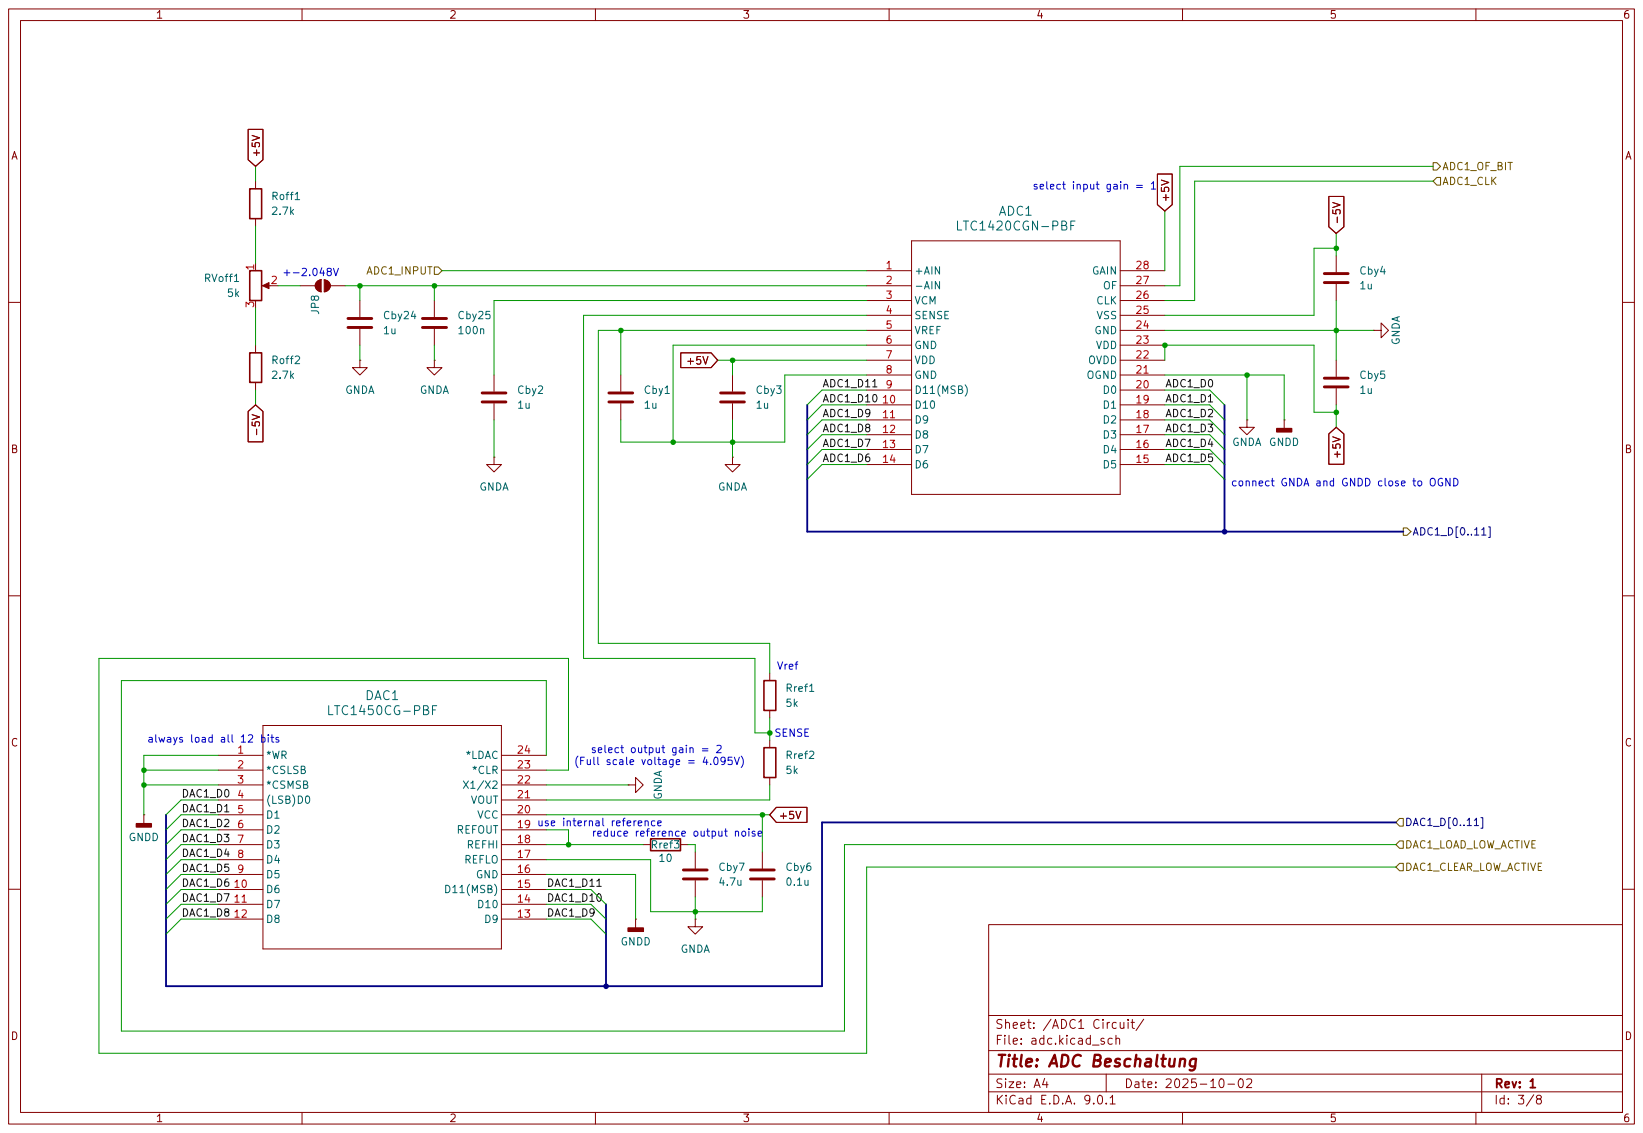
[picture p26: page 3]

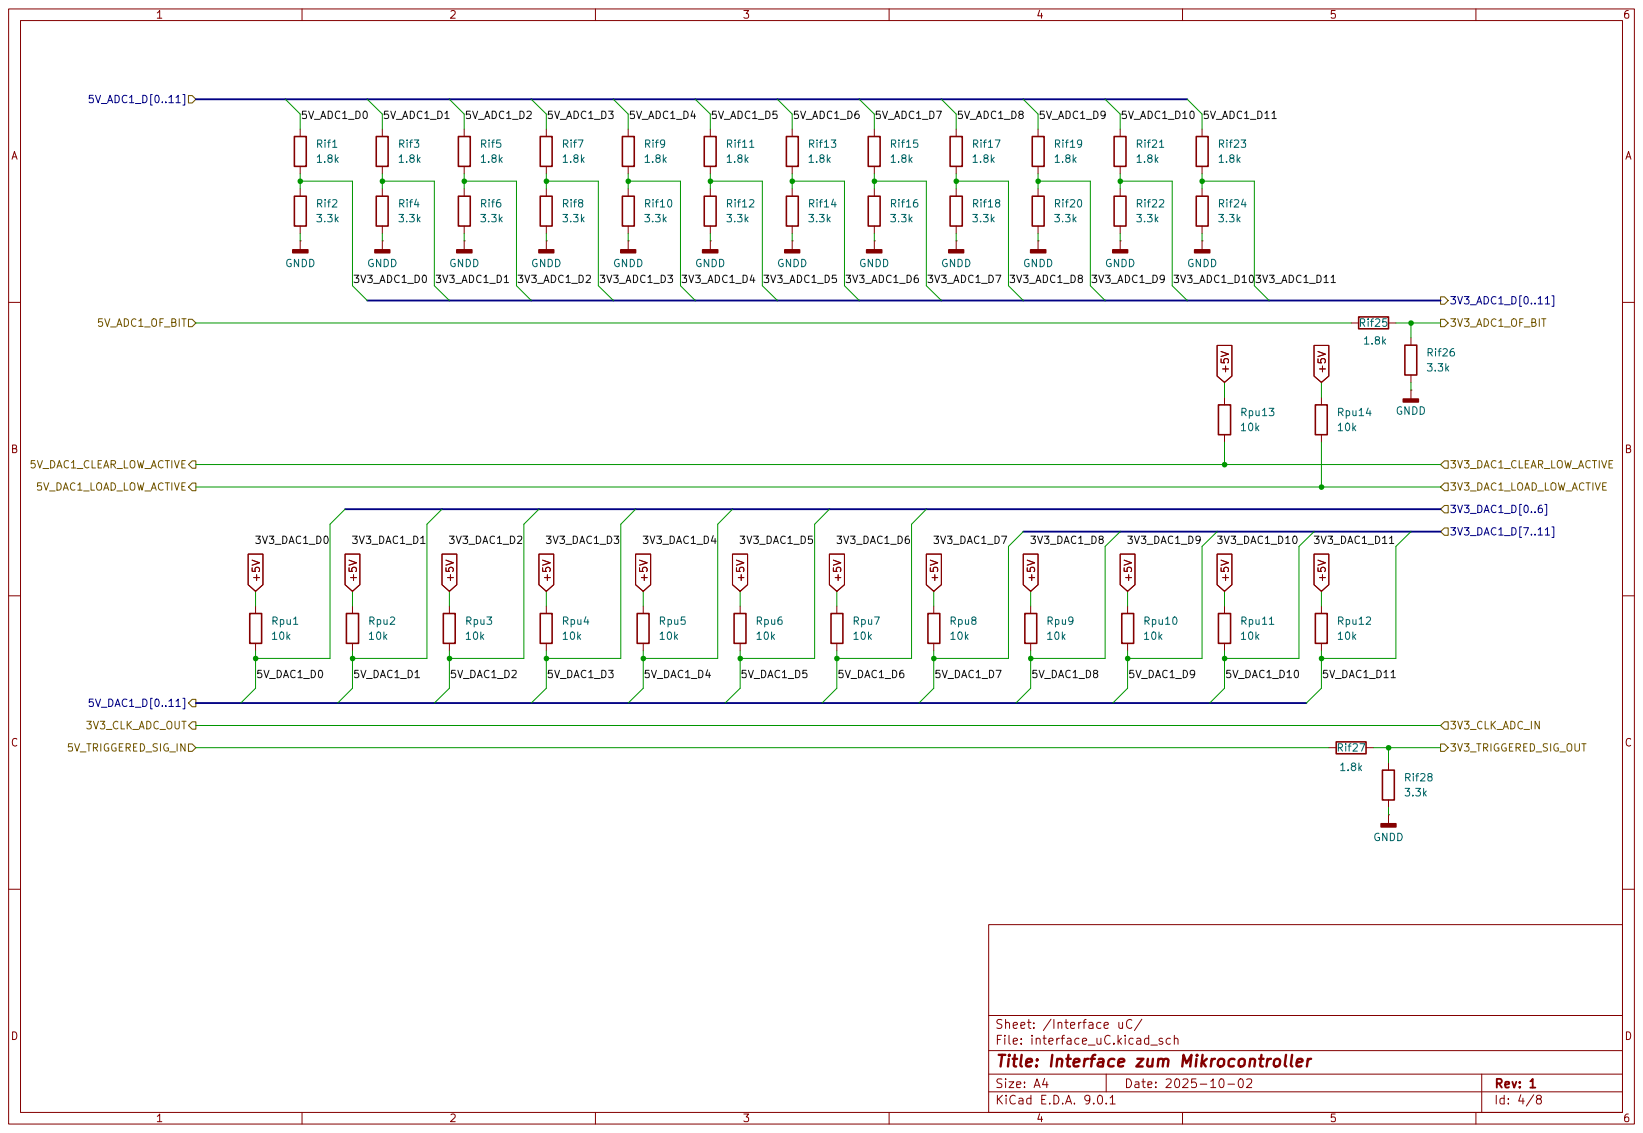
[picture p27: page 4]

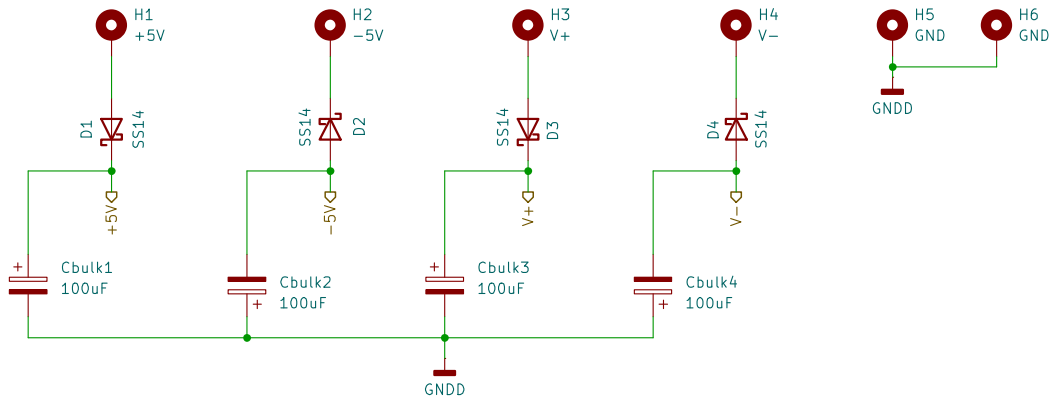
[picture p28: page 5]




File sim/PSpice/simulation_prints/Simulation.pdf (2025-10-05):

0


Simulation - USB-Oszi - Analog Frontend

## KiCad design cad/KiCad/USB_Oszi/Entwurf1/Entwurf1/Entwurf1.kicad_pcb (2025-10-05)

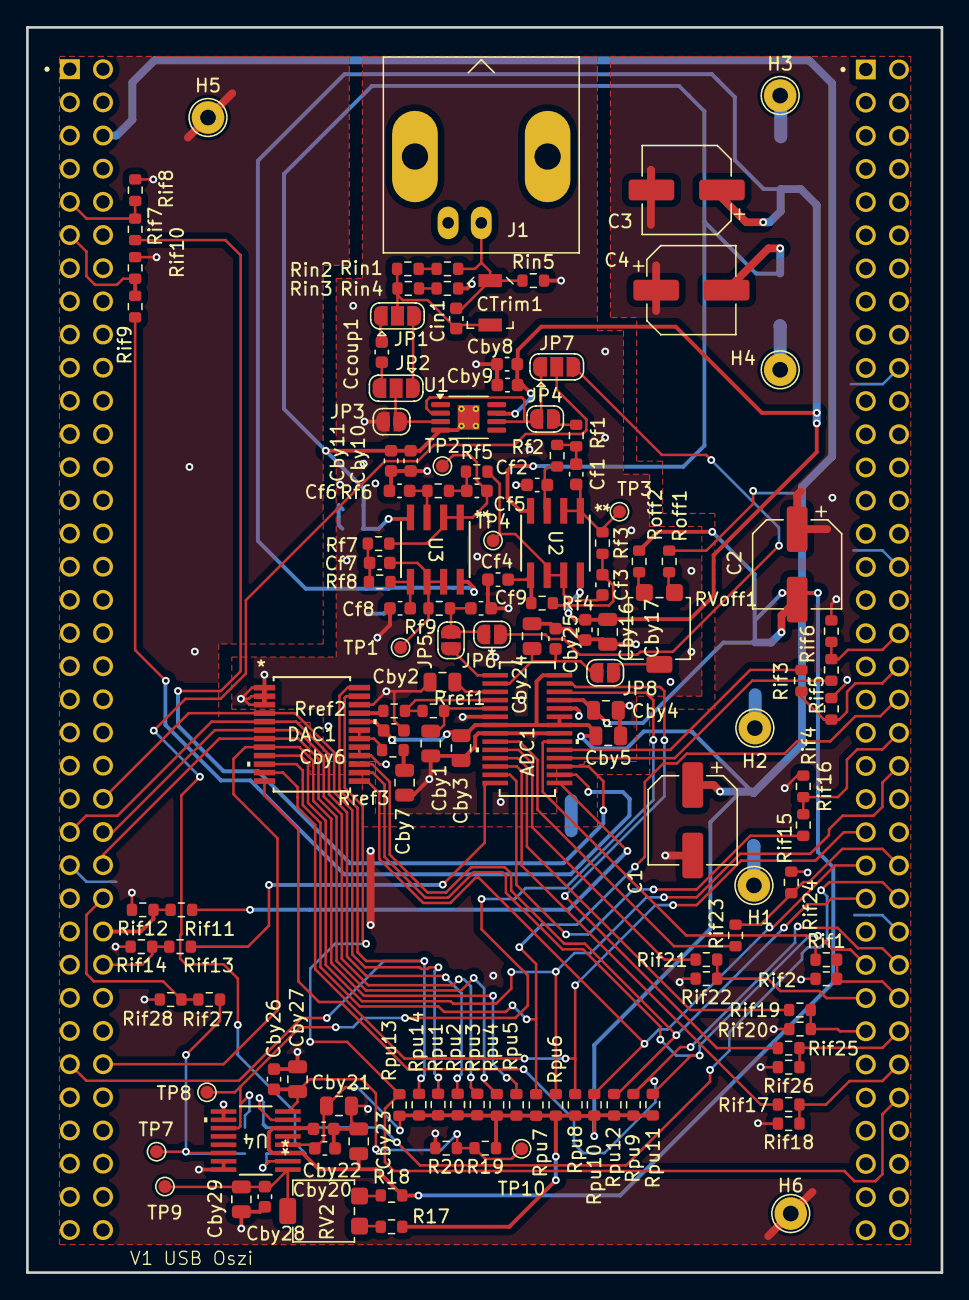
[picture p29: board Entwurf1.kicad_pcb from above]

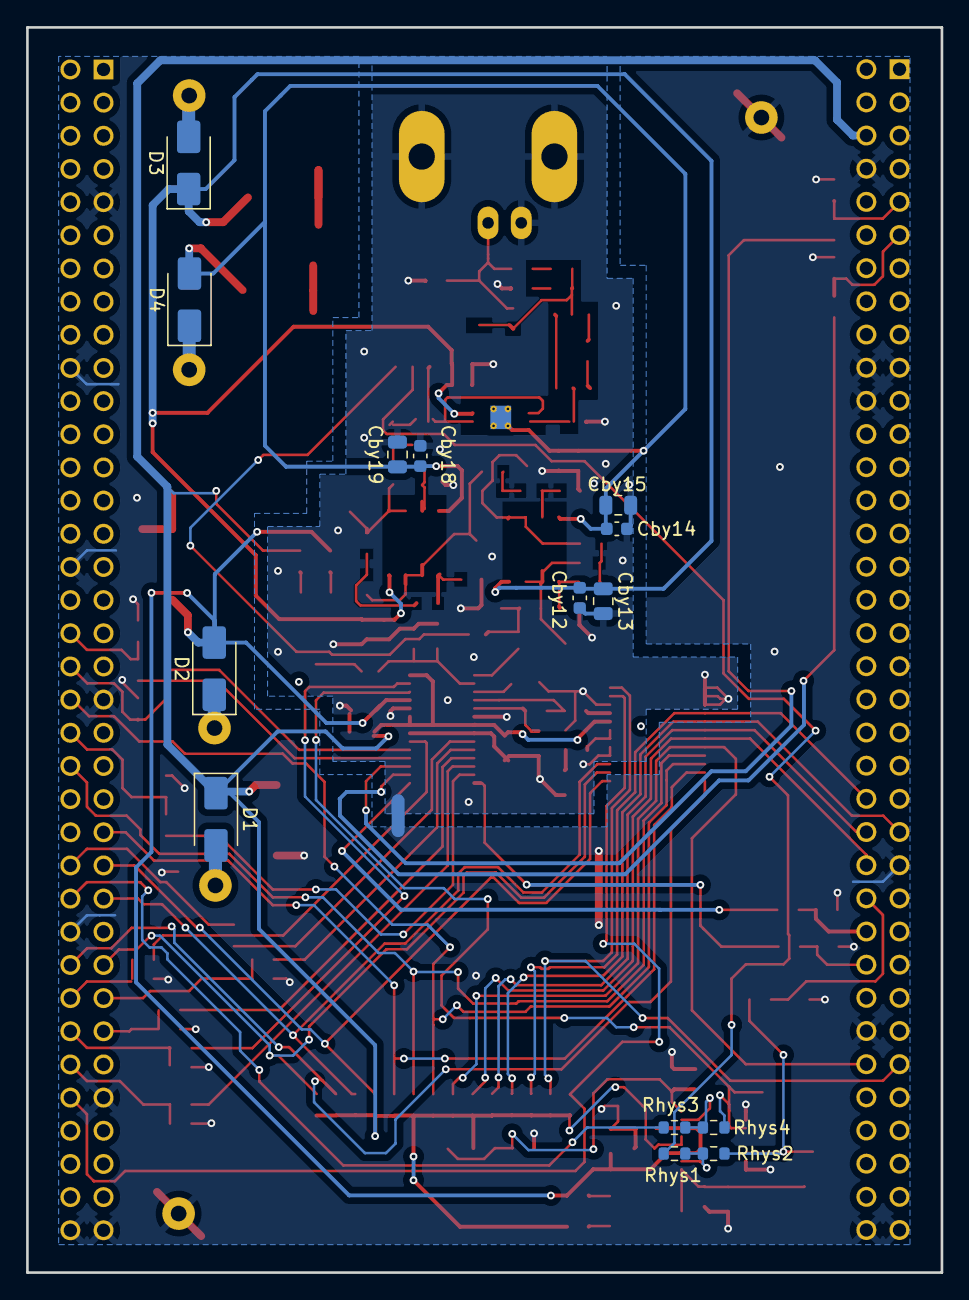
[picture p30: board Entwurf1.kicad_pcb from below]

Board: 2 copper layers, 70.0 x 95.4 mm, 150 parts (14 on the bottom side), 95 nets.

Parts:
A1: NUCLEO-F767ZI; ST_NUCLEO-F767ZI
ADC1: LTC1420CGN-PBF; FOOTPRINT_ADC_USB_OSZI
C1, C2, C3, C4: C_Polarized; CP_Elec_6.3x7.7
CTrim1: Cin2; C_Trimmer_Voltronics_JR
Cby1, Cby2, Cby3, Cby4, Cby5, Cby24: 1u; C_0805_2012Metric
Cby6, Cby8, Cby10, Cby12, Cby14, Cby16, Cby18, Cby20, Cby22, Cby26, Cby28: 0.1u; C_0603_1608Metric
Cby7, Cby21, Cby23, Cby27, Cby29: 4.7u; C_0805_2012Metric
Cby9, Cby11: 100p; C_0603_1608Metric
Cby13, Cby15, Cby17, Cby19: 10u; C_0805_2012Metric
Cby25: 100n; C_0603_1608Metric
Ccoup1: C; C_0603_1608Metric
Cf1, Cf2, Cf3, Cf4, Cf5, Cf6, Cf7, Cf8, Cf9: C; C_0603_1608Metric
Cin1: C; C_0603_1608Metric
D1, D2, D3, D4: D_Schottky; D_SMA
DAC1: LTC1450CG-PBF; SSOP-24_G_LIT
H1: +5V; TestPoint_THTPad_D2.5mm_Drill1.2mm
H2: -5V; TestPoint_THTPad_D2.5mm_Drill1.2mm
H3: V+; TestPoint_THTPad_D2.5mm_Drill1.2mm
H4: V-; TestPoint_THTPad_D2.5mm_Drill1.2mm
H5, H6: GND; TestPoint_THTPad_D2.5mm_Drill1.2mm
J1: BNC_CH1; BNC_Amphenol_B6252HB-NPP3G-50_Horizontal
JP1, JP2, JP7: coupling; SolderJumper-3_P1.3mm_Open_RoundedPad1.0x1.5mm
JP3, JP4, JP5, JP6, JP8: coupling; SolderJumper-2_P1.3mm_Open_RoundedPad1.0x1.5mm
R17, R18: 820; R_0603_1608Metric
R19: 68k; R_0603_1608Metric
R20: 33k; R_0603_1608Metric
RV2: 10k; Potentiometer_Bourns_3314G_Vertical
RVoff1: 5k; Potentiometer_Bourns_3314G_Vertical
Rf1, Rf2, Rf3, Rf4, Rf5, Rf6, Rf7, Rf8, Rf9: R; R_0603_1608Metric
Rhys1, Rhys3: 100; R_0603_1608Metric
Rhys2, Rhys4: 50k; R_0603_1608Metric
Rif1, Rif2, Rif3, Rif4, Rif5, Rif6, Rif7, Rif8, Rif9, Rif10, Rif11, Rif12, Rif13, Rif14, Rif15, Rif16, Rif17, Rif18, Rif19, Rif20, Rif21, Rif22, Rif23, Rif24, Rif25, Rif26, Rif27, Rif28: R; R_0603_1608Metric
Rin1: 30k; R_0603_1608Metric
Rin2: 560k; R_0603_1608Metric
Rin3: 20k; R_0603_1608Metric
Rin4: 390k; R_0603_1608Metric
Rin5: 50; R_0603_1608Metric
Roff1, Roff2: 2.7k; R_0603_1608Metric
Rpu1, Rpu2, Rpu3, Rpu4, Rpu5, Rpu6, Rpu7, Rpu8, Rpu9, Rpu10, Rpu11, Rpu12, Rpu13, Rpu14: 10k; R_0603_1608Metric
Rref1, Rref2: 5k; R_0603_1608Metric
Rref3: 10; R_0603_1608Metric
TP1: OPV4_OUT; TestPoint_Pad_D1.0mm
TP2: OPV3_OUT; TestPoint_Pad_D1.0mm
TP3: OPV1_OUT; TestPoint_Pad_D1.0mm
TP4: OPV2_OUT; TestPoint_Pad_D1.0mm
TP7: TRIGGER; TestPoint_Pad_D1.0mm
TP8: 5V_CLK; TestPoint_Pad_D1.0mm
TP9: TRIGGER_REF; TestPoint_Pad_D1.0mm
TP10: CLK_REF; TestPoint_Pad_D1.0mm
U1: THS4631DGN; MSOP-8-1EP_3x3mm_P0.65mm_EP1.68x1.88mm_ThermalVias
U2, U3: AD8022ARZ-REEL7; R_8_ADI
U4: LT1714CGN-PBF; SSOP-16_GN_LIT

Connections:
+5V: A1.CN11_6 (E5V), ADC1.7 (VDD), ADC1.22 (OVDD), ADC1.23 (VDD), ADC1.28 (GAIN), C1.1, Cby3.1, Cby5.2, Cby6.1, Cby20.1, Cby21.1, D1.1 (K), DAC1.20 (VCC), R17.1, R19.1, Roff1.1, Rpu1.1, Rpu2.1, Rpu3.1, Rpu4.1, Rpu5.1, Rpu6.1, Rpu7.1, Rpu8.1, Rpu9.1, Rpu10.1, Rpu11.1, Rpu12.1, Rpu13.1, Rpu14.1, U4.4 (V+), U4.5 (V+)
-5V: ADC1.25 (VSS), C2.2, Cby4.1, Cby22.1, Cby23.1, D2.2 (A), R18.2, Roff2.2, U4.3 (V-), U4.6 (V-)
/ADC1/ADC1_CLK: ADC1.26 (CLK), Rhys4.2, TP8.1, U4.11 (QB)
/ADC1/ADC1_D0: ADC1.20 (D0), Rif1.1
/ADC1/ADC1_D1: ADC1.19 (D1), Rif3.1
/ADC1/ADC1_D2: ADC1.18 (D2), Rif5.1
/ADC1/ADC1_D3: ADC1.17 (D3), Rif7.1
/ADC1/ADC1_D4: ADC1.16 (D4), Rif9.1
/ADC1/ADC1_D5: ADC1.15 (D5), Rif11.1
/ADC1/ADC1_D6: ADC1.14 (D6), Rif13.1
/ADC1/ADC1_D7: ADC1.13 (D7), Rif15.1
/ADC1/ADC1_D8: ADC1.12 (D8), Rif17.1
/ADC1/ADC1_D9: ADC1.11 (D9), Rif19.1
/ADC1/ADC1_D10: ADC1.10 (D10), Rif21.1
/ADC1/ADC1_D11: ADC1.9 (D11(MSB)), Rif23.1
/ADC1/ADC1_INPUT: ADC1.1 (+AIN), JP5.2 (B)
/ADC1/ADC1_OF_BIT: ADC1.27 (OF), Rif25.1
/ADC1/DAC1_CLEAR_LOW_ACTIVE: A1.CN12_64 (PE0), DAC1.23 (*CLR), Rpu13.2
/ADC1/DAC1_LOAD_LOW_ACTIVE: A1.CN11_61 (PE1), DAC1.24 (*LDAC), Rpu14.2
/Analog Frontend CH1/ANALOG_INPUT: CTrim1.1, Cin1.1, J1.1 (In), Rin1.1, Rin5.1
/Analog Frontend CH1/TRIGGER_SIGNAL: JP7.2 (C), Rhys1.1
/Connector uC/PE2: A1.CN11_46 (PE2), DAC1.4 ((LSB)D0), Rpu1.2
/Connector uC/PE3: A1.CN11_47 (PE3), DAC1.5 (D1), Rpu2.2
/Connector uC/PE4: A1.CN11_48 (PE4), DAC1.6 (D2), Rpu3.2
/Connector uC/PE5: A1.CN11_50 (PE5), DAC1.7 (D3), Rpu4.2
/Connector uC/PE6: A1.CN11_62 (PE6), DAC1.8 (D4), Rpu5.2
/Connector uC/PE7: A1.CN12_44 (PE7), DAC1.9 (D5), Rpu6.2
/Connector uC/PE8: A1.CN12_40 (PE8), DAC1.10 (D6), Rpu7.2
/Connector uC/PE9: A1.CN12_52 (PE9), Rhys3.1
/Connector uC/PE10: A1.CN12_47 (PE10), DAC1.11 (D7), Rpu8.2
/Connector uC/PE11: A1.CN12_56 (PE11), DAC1.12 (D8), Rpu9.2
/Connector uC/PE12: A1.CN12_49 (PE12), DAC1.13 (D9), Rpu10.2
/Connector uC/PE13: A1.CN12_55 (PE13), DAC1.14 (D10), Rpu11.2
/Connector uC/PE14: A1.CN12_51 (PE14), DAC1.15 (D11(MSB)), Rpu12.2
/Connector uC/PF2: A1.CN11_52 (PF2), Rif27.2, Rif28.1
/Connector uC/PF3: A1.CN12_58 (PF3), Rif1.2, Rif2.1
/Connector uC/PF4: A1.CN12_38 (PF4), Rif3.2, Rif4.1
/Connector uC/PF5: A1.CN12_36 (PF5), Rif5.2, Rif6.1
/Connector uC/PF6: A1.CN11_9 (PF6), Rif7.2, Rif8.1
/Connector uC/PF7: A1.CN11_11 (PF7), Rif9.2, Rif10.1
/Connector uC/PF8: A1.CN11_54 (PF8), Rif11.2, Rif12.1
/Connector uC/PF9: A1.CN11_56 (PF9), Rif13.2, Rif14.1
/Connector uC/PF10: A1.CN12_42 (PF10), Rif15.2, Rif16.1
/Connector uC/PF11: A1.CN12_62 (PF11), Rif17.2, Rif18.1
/Connector uC/PF12: A1.CN12_59 (PF12), Rif19.2, Rif20.1
/Connector uC/PF13: A1.CN12_57 (PF13), Rif21.2, Rif22.1
/Connector uC/PF14: A1.CN12_50 (PF14), Rif23.2, Rif24.1
/Connector uC/PF15: A1.CN12_60 (PF15), Rif25.2, Rif26.1
/Interface uC/5V_TRIGGERED_SIG_IN: Rhys2.1, Rif27.1, TP7.1, U4.14 (QA)
GNDA: A1.CN11_8 (GND_CN11), A1.CN11_19 (GND_CN11__1), A1.CN11_20 (GND_CN11__2), A1.CN11_22 (GND_CN11__3), A1.CN11_49 (GND_CN11__4), A1.CN11_60 (GND_CN11__5), A1.CN11_71 (GND_CN11__6), A1.CN11_72 (GND_CN11__7), A1.CN12_9 (GND_CN12), A1.CN12_20 (GND_CN12__1), A1.CN12_32 (AGND_CN12), A1.CN12_39 (GND_CN12__2), A1.CN12_54 (GND_CN12__3), A1.CN12_63 (GND_CN12__4), A1.CN12_71 (GND_CN12__5), A1.CN12_72 (GND_CN12__6), ADC1.6 (GND), ADC1.8 (GND), ADC1.21 (OGND), ADC1.24 (GND), C1.2, C2.1, C3.2, C4.1, Cby1.2, Cby2.2, Cby3.2, Cby4.2, Cby5.1, Cby6.2, Cby7.2, Cby8.2, Cby9.2, Cby10.2, Cby11.2, Cby12.2, Cby13.2, Cby14.2, Cby15.2, Cby16.2, Cby17.2, Cby18.2, Cby19.2, Cby20.2, Cby21.2, Cby22.2, Cby23.2, Cby24.2, Cby25.2, Cby26.2, Cby27.2, Cby28.2, Cby29.2, Cf2.2, Cf4.2, Cf6.2, Cf8.2, Cf9.2, DAC1.1 (*WR), DAC1.2 (*CSLSB), DAC1.3 (*CSMSB), DAC1.16 (GND), DAC1.17 (REFLO), DAC1.22 (X1/X2), H5.1, H6.1, J1.2 (Ext), JP3.2 (B), R20.2, Rif2.2, Rif4.2, Rif6.2, Rif8.2, Rif10.2, Rif12.2, Rif14.2, Rif16.2, Rif18.2, Rif20.2, Rif22.2, Rif24.2, Rif26.2, Rif28.2, Rin4.2, Rin5.2, U4.9 (LATCHENABLEB), U4.10 (GND), U4.15 (GND), U4.16 (LATCHENABLEA)
unnamed: ADC1.2 (-AIN), Cby24.1, Cby25.1, JP8.2 (B)
unnamed: ADC1.4 (SENSE), Rref1.2, Rref2.1
unnamed: ADC1.3 (VCM), Cby2.1
unnamed: ADC1.5 (VREF), Cby1.1, Rref1.1
unnamed: Cby7.1, Rref3.2
unnamed: Cf1.2, Rf1.2, Rf2.1
unnamed: Cf3.1, Rf3.2, Rf4.1
unnamed: Cf5.2, Rf5.2, Rf6.1
unnamed: Cf7.1, Rf7.2, Rf8.1
unnamed: D1.2 (A), H1.1
unnamed: D2.1 (K), H2.1
unnamed: D3.2 (A), H3.1
unnamed: D4.1 (K), H4.1
unnamed: DAC1.18 (REFHI), DAC1.19 (REFOUT), Rref3.1
unnamed: DAC1.21 (VOUT), Rref2.2
unnamed: Ccoup1.1, JP1.1 (A)
unnamed: JP1.3 (B), JP2.1 (A)
unnamed: CTrim1.2, Cin1.2, JP1.2 (C), Rin2.2, Rin3.1
unnamed: Ccoup1.2, JP2.3 (B)
unnamed: JP2.2 (C), JP3.1 (A), U1.3 (+)
unnamed: JP4.1 (A), JP7.1 (A), U1.2 (-), U1.6
unnamed: JP4.2 (B), Rf1.1
unnamed: Cf9.1, JP5.1 (A), JP6.1 (A), Rf9.2
unnamed: JP6.2 (B), JP7.3 (B)
unnamed: JP8.1 (A), RVoff1.2
unnamed: R17.2, RV2.1
unnamed: R18.1, RV2.3
unnamed: RVoff1.1, Roff1.2
unnamed: RVoff1.3, Roff2.1
unnamed: Rin1.2, Rin2.1
unnamed: Rin3.2, Rin4.1
unnamed: Cf2.1, Rf2.2, U2.3 (+IN1)
unnamed: Cf4.1, Rf4.2, U2.5 (+IN2)
unnamed: Cf1.1, Rf3.1, TP3.1, U2.1 (OUT1), U2.2 (-IN1)
unnamed: Cf3.2, Rf5.1, TP4.1, U2.6 (-IN2), U2.7 (OUT2)
unnamed: Cf6.1, Rf6.2, U3.3 (+IN1)
unnamed: Cf8.1, Rf8.2, U3.5 (+IN2)
unnamed: Cf5.1, Rf7.1, TP2.1, U3.1 (OUT1), U3.2 (-IN1)
unnamed: Cf7.2, Rf9.1, TP1.1, U3.6 (-IN2), U3.7 (OUT2)
unnamed: Rhys1.2, Rhys2.2, U4.2 (+INA)
unnamed: Rhys3.2, Rhys4.1, U4.7 (+INB)
unnamed: Cby28.1, Cby29.1, RV2.2, TP9.1, U4.1 (-INA)
unnamed: Cby26.1, Cby27.1, R19.2, R20.1, TP10.1, U4.8 (-INB)
V+: C3.1, Cby8.1, Cby9.1, Cby12.1, Cby13.1, Cby16.1, Cby17.1, D3.1 (K), U1.7 (V+), U2.8 (+VS), U3.8 (+VS)
V-: C4.2, Cby10.1, Cby11.1, Cby14.1, Cby15.1, Cby18.1, Cby19.1, D4.2 (A), U1.4 (V-), U1.9 (PAD), U2.4 (-VS), U3.4 (-VS)

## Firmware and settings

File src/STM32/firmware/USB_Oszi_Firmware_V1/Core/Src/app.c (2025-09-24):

/* ***************************************************************************************
 *  Project:    USB oscilloscope
 *  File:       app.c
 *
 *  Language:   C
 ************************************************************************************** */

/* #INCLUDES */
#include "app.h"
#include "main.h"
#include "fsm.h"
#include "usbd_cdc_if.h"
#include <string.h>


/* #DEFINES */
// usb transmission
#define USB_BUFLEN 64
#define CMD_RX_BUFFER_SIZE 128
#define CMD_TX_BUFFER_SIZE 128

// data transmission
#define MAX_TRANSFER_BYTELENGTH 1000

// sampling frequency
#define FREQ_TIMER 100000000
#define MAX_FREQ_ADC 10000000
#define MIN_FREQ_ADC 20000
#define INIT_FREQ_ADC MAX_FREQ_ADC

// moving average filter
#define MOV_AVG_MODE_CUMULATIVE 1
#define MOV_AVG_MODE_RECURSIVE 2
#define CUR_MOV_AVG_MODE MOV_AVG_MODE_RECURSIVE

#define MASK_D0_D6	0x7F
#define MASK_D7_D11 0xF80

/* PRIVATE FUNCTION PROTOTYPES */
static void applyMovingAverageFilter();
static void CDC_Send(uint8_t* data, uint16_t len);
static void receiveCommand();
static void processCommand(const char* cmd);
static void GPIO_Init();
static void EXTI_Init();
static void TIM3_Init();
static void DMA_Init(uint32_t numOfTransfers);
static int determineBufferAddresses(uint16_t buf[], uint32_t bufSize, uint32_t* addressArray[][NUMBER_OF_COLUMNS]);
static void TIM1_Init();

/* STATIC GLOBAL VARIABLES */
static char cmdTxBuffer[CMD_TX_BUFFER_SIZE];

static volatile uint8_t usbRxBuf[USB_BUFLEN];
static volatile uint16_t usbRxBufLen;
static volatile uint8_t usbRxFlag = 0;

static volatile uint8_t cmdRxBuffer[CMD_RX_BUFFER_SIZE];
static volatile uint16_t cmdRxIndex = 0;

/* configuration variables (controllable by PC application) */
static volatile uint32_t newSamplingFrequency = 10000000;
static volatile uint32_t currentSamplingFrequency = 10000000;

static volatile uint16_t newReferenceVoltage = 4095;
static volatile uint16_t currentReferenceVoltage = 4095;

static volatile TRIGGERMODE_T currentTriggerMode = TRIGGER_RISING_EDGE;

// number of points used by moving average filter
static volatile uint16_t newNumOfPoints = 51;
static volatile uint16_t currentNumOfPoints = 51;

/* status variables */
static volatile uint8_t overflowHappened = 0;

/* GLOBAL VARIABLES */

// array, that holds the base addresses for each DMA transaction
// <NUM_OF_TRANSFERS_PER_TRANSACTION> sample values are referenced per array element
volatile uint32_t* addressArray[NUMBER_OF_ROWS][NUMBER_OF_COLUMNS] = {0};

/* Global array variable for storing the 12bit sampling values from the ADC[D11...D0] */
volatile int16_t sampleBuffer[NUM_OF_SAMPLES] = {0};

// moving average filter output and status variable
volatile int16_t filteredSampleBuffer[NUM_OF_SAMPLES] = {0};
// 0 = inactive (default) ; 1 = active
static volatile uint8_t movAvgFilterActive = 0;

// overflowBuffer is needed to bridge the time until the DMA is disabled
// size is dependent on the number of possible transfers, before DMA is disabled in the ISR
volatile uint16_t overflowBuffer[1000] = {0};



/* FUNCTION DEFINITIONS */

/* app_Init()
 *
 * run all application initializations
 *	 													*/
void app_Init()
{
	__disable_irq();

	// peripheral initializations
	GPIO_Init();
	EXTI_Init();
	TIM3_Init();								// debounces button B1

	// determine all values for the addressArray
	uint32_t bufferSize = NUMBER_OF_ROWS*NUMBER_OF_COLUMNS*NUM_OF_TRANSFERS_PER_TRANSACTION;
	determineBufferAddresses(sampleBuffer, bufferSize, addressArray);
	DMA_Init(NUM_OF_TRANSFERS_PER_TRANSACTION);	// init value of NDTR: NUM_OF_TRANSFERS_PER_TRANSACTION

	TIM1_Init();								// creates clock-signal (default: freq=10MHz)

	__enable_irq();
}

void reInit_DMA()
{
	__disable_irq();
	DMA_Init(NUM_OF_TRANSFERS_PER_TRANSACTION);
	__enable_irq();
}

/* void setOnboardStatusLEDs(uint8_t status)
 *
 * uses onboard LEDs LD1...3 of NUCLEO-F767 for status display
 *
 * possible inputs: 0...7
 *
 * 0 is not recommended -> LEDs are off
 * (not distinguishable from error or invalid input)
 *	 													*/
void setOnboardStatusLEDs(uint8_t status)
{
	int ledMask = 0;
	// turn LD1..3 off
	GPIOB->ODR &= ~(LD1_Pin|LD2_Pin|LD3_Pin);
	switch(status)
	{
	case 0:
		break;
	case 1:
		ledMask = LD1_Pin;
		break;
	case 2:
		ledMask = LD2_Pin;
		break;
	case 3:
		ledMask = LD2_Pin|LD1_Pin;
		break;
	case 4:
		ledMask = LD3_Pin;
		break;
	case 5:
		ledMask = LD3_Pin|LD1_Pin;
		break;
	case 6:
		ledMask = LD3_Pin|LD2_Pin;
		break;
	case 7:
		ledMask = LD3_Pin|LD2_Pin|LD1_Pin;
		break;
	default:
		break;
	}
	GPIOB->ODR |= ledMask;
}

/* void configureTrigger(TRIGGERMODE_T triggerMode)
 *
 * configures the peripheral to set the sampling frequency
 * according to the variable newSamplingFrequency (value sent over from PC)
 *	 													*/
void configureSamplingFrequency()
{
	// disable TIM1
	TIM1->CR1 &= ~TIM_CR1_CEN;

	// ARR-value
	uint16_t TIM1_ticks = 0;

	// Timer-Clk: 100 MHz
	// Timer-Clk is set in TIM1_Init())

	// max. frequency: 10MHz (ADC DS p.4 - timing characteristics)
	if(newSamplingFrequency > MAX_FREQ_ADC)
	{
		newSamplingFrequency = MAX_FREQ_ADC;
	}
	// min. frequency: 20kHz (ADC DS p.4 - timing characteristics)
	else if(newSamplingFrequency < MIN_FREQ_ADC)
	{
		newSamplingFrequency = MIN_FREQ_ADC;
	}

	TIM1_ticks = (FREQ_TIMER / newSamplingFrequency) - 1;

	// set auto-reload register (ARR)
	TIM1->ARR &= ~(0xFFFF);
	TIM1->ARR |= TIM1_ticks;
	// set capture conmpare register
	TIM1->CCR1 &= ~(0xFFFF);
	TIM1->CCR1 |= (TIM1_ticks + 1) / 2;

	currentSamplingFrequency = FREQ_TIMER / (TIM1_ticks + 1);

	// enable TIM1
	TIM1->CR1 |= TIM_CR1_CEN;
}

/* void configureReferenceVoltage()
 *
 * configures the external DAC (LTC1450) to set the ADC reference voltage in mV
 * according to the variable newReferenceVoltage (value sent over from PC)
 *
 * µC[PE14:PE10, PE8:PE2] --> DAC[D11:D0]
 * PE0: /CLEAR
 * PE1: /LOAD
 * 														*/
void configureReferenceVoltage()
{
	// set LOAD=1 -> deactivate DAC-Latch (don't update DAC with value from data pins)
	GPIOE->ODR |= GPIO_ODR_OD1;

	// Vref = 4096mV - VDAC
	uint16_t DAC_val = 4095 - newReferenceVoltage;

	uint16_t DAC_ODR_val = 0, temp;

	// set bits DAC[D0:D6] ( µC[PE2:PE8] )
	temp = DAC_val & MASK_D0_D6;				// extract DAC[D0:D6]
	DAC_ODR_val |= (temp << 2);		// prepare assignment to µC[PE2:PE8]
	// set bits DAC[D7:D11] ( µC[PE10:PE14] )
	temp = (DAC_val & MASK_D7_D11) >> 7;			// extract DAC[D7:D11] and flush right
	DAC_ODR_val |= (temp << 10);		// prepare assignment to µC[PE10:PE14]

	// clear µC[PE2:PE8, PE10:PE14]
	GPIOE->ODR &= ~(GPIO_ODR_OD2|GPIO_ODR_OD3|GPIO_ODR_OD4|GPIO_ODR_OD5|GPIO_ODR_OD6|GPIO_ODR_OD7|GPIO_ODR_OD8|
				    GPIO_ODR_OD10|GPIO_ODR_OD11|GPIO_ODR_OD12|GPIO_ODR_OD13|GPIO_ODR_OD14);
	GPIOE->ODR |= DAC_ODR_val;					// assign DAC[D0:D11]

	currentReferenceVoltage = newReferenceVoltage;

	// set LOAD=0 -> activate DAC-Latch (update DAC with value from data pins)
	GPIOE->ODR &= ~GPIO_ODR_OD1;
}
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

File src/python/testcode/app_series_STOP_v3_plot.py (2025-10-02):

# file: app_series_STOP_v3_plot.py
# 
# This program traverses through the FSM of the µC INCLUDING DUMMY DATA RECEPTION.
# The FSM is controlled with string-commands send over the emulated Serial Interface (hardware: USB FS).
# 
# used driver on µC: USB CDC Device (STM32F7);
# 
# works with STM32CubeIDE-project "USB_Oszi_Firmware_V1"
#
# Beginning: FSM is in Initial State (Init)
# "APP\n" starts the application (Init->Idle)
# after execution of the program, the FSM is in Idle State
# 
# single commands can be easily sent via hterm-software
# https://www.der-hammer.info/pages/terminal.html
# Sent commands need to include a EOL-char (\n or \r) --> setting "send on enter XX" XX = LF or CR

import time
import serial
import matplotlib.pyplot as plt

def shift(a):
    return a >> 3

def mask(a):
    return a & 0xFFF

def twosComplToSignedInt(a):
    if(((a >> 11) & 1) == 1):
        a -= 1
        a ^= 0xFFF
        a = -a
    return a

datalength = 200000

# x-axis: indices of the list
indices = list(range(datalength//2))

#--configure port--
ser = serial.Serial()

# baud rate is emulated!
# real transmission speed is determined by USB speed (USB FS: 12MBit/s)
ser.baudrate = 115200

# timeout is needed for read()-/readline()-functions (e.g ACQUISITION:DONE)
ser.timeout = 5

# COM-port on Windows PC (VCP)
ser.port = 'COM13'

#print information (see default values of parameters, that were not explicitly set)
print(ser)

# open serial port
ser.open()
print('--Port opened: {0}--'.format(ser.is_open))
print('')

# reset
print('--RESET--')
print("out: \"RESET\"")
ser.write(b'RESET\n')
print('')

# start application of µC
print('--Start app--')
print("out: \"APP\"")
ser.write(b'APP\n')
# get acknoledgement (STATE:IDLE)
line = ser.readline()
print("in: {0}".format(line))
print('')

# configure trigger
print('--Configure trigger--')
print("out: \"CONFIGURE_TRIG_FALL_EDGE\"")
ser.write(b'CONFIGURE_TRIG_FALL_EDGE\n')
# get acknoledgement (TRIGGER:XXX_EDGE)     XXX=RISING, FALLING
line = ser.readline()
print("in: {0}".format(line))
print('')

print('--Start acquisiton (waits for trigger)--')
print("out: \"RUN_START\"")
ser.write(b'RUN_START\n')
# get acknoledgement (STATE:ACQUISITION_START)
line = ser.readline()
print("in: {0}".format(line))

print('--wait for end of acquisition--')
# get acknoledgement (STATE:ACQUISITION_DONE)
line = ser.readline()
print("in: {0}".format(line))

print('')

print('--Signal readiness for data reception--')
print("out: \"READY_FOR_DATA\"")
ser.write(b'READY_FOR_DATA\n')
# get acknoledgement (STATE:TRANSMISSION) !currently not sent by firmware!
# line = ser.readline()
# print("in: {0}".format(line))

# Data reception (100000 values -> 200000 bytes)
time1 = time.perf_counter()
time11 = time.time()
data = ser.read(datalength)
time2 = time.perf_counter()
time21 = time.time()
print('Transmission time: {0}'.format(time2 - time1))
print('Transmission time (alt): {0}'.format(time21 - time11))
print('Received Bytes: {0}'.format(len(data)))

# Convert byte string to list of 2byte-integers (data has same order as in µC memory)
time1 = time.perf_counter()
data_list = [
    int.from_bytes(data[i:i+2], byteorder='little')  # or 'big'
    for i in range(0, len(data), 2)
]
#for i in range(2000):
#    binary = format(data_list[i], 'b')
#    print(binary, end=" ")
data_list_shifted = list(map(shift, data_list))
data_list_masked = list(map(mask, data_list_shifted))
data_list_processed = list(map(twosComplToSignedInt, data_list_masked))
time2 = time.perf_counter()
print('Conversion time: {0}'.format(time2 - time1))
#print("{0}".format(data_list_processed))

print('')

print('--Acknowledge reception--')
print("out: \"RECEIVED\"")
ser.write(b'RECEIVED\n')
# get acknoledgement (STATE:WAIT_FOR_ACK)
line = ser.readline()
print("in: {0}".format(line))

print('')

print('--send ACK to µC: STOP--')
print("out: \"STOP\"")
ser.write(b'STOP\n') # alternative: CONTINUE -> back in STATE:ACQUISITION
# get acknoledgement (STATE:IDLE)
line = ser.readline()
print("in: {0}".format(line))

# close serial port
ser.close()

# Create the plot
plt.figure(figsize=(8, 4))
plt.plot(indices, data_list_processed, linestyle='-', color='blue')

# Add labels and title
plt.xlabel('index')
plt.ylabel('data value')
plt.title('list of data (index on X-axis)')
plt.grid(True)

# Show the plot
plt.show()

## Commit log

2025-09-24 format measurements and adding the probe setting
2025-09-24 add FW part in documentation (digital filter - recursive)
2025-09-24 FW fix moving average filter and add recursive variant
    [app.c]
2025-09-25 Hinzufügen von Grafiken, zur Darstellung der Softwarearchitektur
2025-09-30 fixed voltage format
2025-10-03 add subsubsection Auswahl und Definition der Messungen in SW Entwurf
2025-10-04 Fixed mistake base measure and added subsection Implementierung GUI und Messfunktionen und Anhang
2025-10-05 add appendix files
    [AAF.DSN, Analoges_Frontend_Simulation.dsn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]
2025-10-05 change directory structure
    [Entwurf1-B_Cu.gbr, Entwurf1-B_Mask.gbr, Entwurf1-B_Paste.gbr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]
2025-10-06 doc of HW part (change references to schematic)
2025-10-06 add link to pcb design rules (HW doc)
